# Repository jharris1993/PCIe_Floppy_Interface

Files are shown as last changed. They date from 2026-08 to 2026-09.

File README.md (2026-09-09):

# Floppy Drive Interface

A hardware/software project to develop a programmable floppy-disk controller and Shugart-interface platform, ultimately implemented as an internal PCIe card.

## Project goals

The primary goal is broad compatibility with floppy drives and disk formats that use conventional Shugart-derived interfaces, including 3.5-inch and 5.25-inch drives and, where practical, 8-inch drives.

The design should support programmable controller behavior rather than being restricted to the assumptions of a conventional PC floppy-disk controller. Future support for flux-transition timing is desirable, but it is secondary to the core controller/interface function and must not materially increase initial cost or complexity.

## Development approach

Development is intentionally staged:

1. Validate floppy-drive control and data handling using a practical FPGA or programmable-logic development platform.
2. Implement and test controller functions including drive selection, motor control, seeking, index handling, read/write operation, and FM/MFM data handling.
3. Develop the host-side software and investigate practical integration with current 64-bit Windows.
4. Migrate the validated design to PCIe.
5. Produce a custom single-board implementation when the architecture is sufficiently mature.

## Repository documentation

- [`Requirements.md`](Requirements.md) — authoritative current project requirements.
- [`Design.md`](Design.md) — current, non-authoritative project design.
- [`Dependencies.md`](Dependencies.md) — external projects, specifications, tools, and pinned baselines.
- [`AGENTS.md`](AGENTS.md) — instructions for Codex and other repository-aware coding agents.
- [`CONTRIBUTING.md`](CONTRIBUTING.md) — repository working practices and change discipline.
- [`Project_Decisions/`](Project_Decisions/) — non-authoritative engineering notebook of significant project choices and rationale.
- [`Documents/`](Documents/) — project-created supporting documentation.
- [`Reference_Documentation/`](Reference_Documentation/) — external technical documents and research.
- [`Reference_Illustrations/`](Reference_Illustrations/) — external explanatory illustrations.
- [`Reference_Implementations/`](Reference_Implementations/) — external implementations available for design reference.
- [`Tools/`](Tools/) — project development, verification, and automation tooling.

## Repository structure

```text
project-root/
├── .gitattributes
├── AGENTS.md
├── CONTRIBUTING.md
├── Dependencies.md
├── Design.md
├── Documents/
├── Drivers/
├── Firmware/
├── Hardware/
├── LICENSE.md
├── Licenses/
├── Project_Decisions/
├── README.md
├── Reference_Documentation/
│   ├── Documents/
│   ├── Pinouts/
│   ├── Research/
│   ├── Schematics/
│   ├── Specifications/
│   ├── README.md
│   └── Sources.md
├── Reference_Illustrations/
├── Reference_Implementations/
│   └── Greaseweazle/
├── Requirements.md
├── Software/
└── Tools/
```

Detailed organization should be defined close to the material it describes.

## Project status

Architecture and baseline documentation are under development. Hardware, firmware, host software, and driver implementation should not be assumed complete unless explicitly documented.

## License

This project is governed by the license conditions specified in [`LICENSE.md`](LICENSE.md).

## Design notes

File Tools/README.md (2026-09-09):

# Tools

This directory contains version-controlled development and verification tooling used by the project.

`Codex_Skills/kicad-eda` is the maintained source for the locally installed KiCad EDA skill. Its installation is a copy; removing that copy does not remove this source.

`Codex_Skills/literal-action-authorization` is the maintained source for the personal interaction rule that interprets questions, imperative instructions, and ambiguous requests in context.

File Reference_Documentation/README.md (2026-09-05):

# Reference Documentation

This directory contains external technical documents and project-created research used for engineering reference.

Material here does not define project requirements or the current project design. Evaluate each source for its origin, revision, applicability, and accuracy.

- `Documents/` contains retained reference documents.
- `Pinouts/` contains connector and interface pinouts.
- `Research/` contains project-created research.
- `Schematics/` contains externally sourced electrical schematics.
- `Specifications/` contains retained technical specifications.

See `Sources.md` for source information.

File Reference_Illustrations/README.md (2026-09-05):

# Reference Illustrations

This directory contains external illustrations retained for technical explanation or comparison.

Electrical schematics, connector pinouts, and technical documents belong in `Reference_Documentation/`.

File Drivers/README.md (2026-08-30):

# Drivers

This directory contains host operating-system driver source and related files.

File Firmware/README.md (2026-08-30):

# Firmware

This directory contains FPGA gateware and device firmware.

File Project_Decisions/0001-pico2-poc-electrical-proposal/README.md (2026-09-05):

# Pico 2 drive interface — tentative electrical design

Status: discussion proposal, 2026-09-01. Not a fabrication release or a hardware-verified circuit. This supplements the existing requirements; it does not select the final controller architecture. Pico GPIO numbers remain deliberately unassigned.

## Drawings

- `interface-cells.svg` / `.png`: reusable output, input, and configurable-direction circuits.
- `connector-map.svg` / `.png`: channel allocation, connector selection, and power connections.
- `draw_schematic.py`: editable drawing source; generates SVG and PNG using Python and Pillow. This is an electrical concept drawing, not a KiCad netlist; no electrical-rule check has been performed.

## Proposed circuit

Use discrete AO3400A N-channel MOSFETs as inverting open-drain outputs, and SN74LVC14A Schmitt-trigger inverters powered from the Pico's 3.3 V supply as receivers. All cable-side signals stay in the drive's 5 V domain. The Pico only sees 3.3 V logic. Both paths invert, so GPIO high means cable signal asserted low.

The MOSFET gate connects to its GPIO through 100 ohms, with 10 kilohms gate-to-source. Source is grounded; drain connects directly to the signal. A high GPIO asserts the signal. A low or high-impedance GPIO releases it. The pull-down is on the MOSFET side of any jumper. Do not infer suitability of an arbitrary substitute from gate threshold voltage: specify on-resistance at a gate voltage no greater than the actual GPIO high voltage. AO3400A specifies a maximum 48 milliohms at VGS = 2.5 V, at its stated 25 C test condition [S1]. Its switching figures use different gate drive/load conditions from this circuit; they are not a guaranteed board-level timing result.

Receiver: signal -> 100 ohms -> SN74LVC14A input; output -> 100 ohms -> GPIO. The receiver is powered at 3.3 V and accepts inputs up to 5.5 V. At 3.3 V +/- 0.3 V, the datasheet specifies a maximum propagation delay of 6.4 ns over -40 to +85 C, under its test conditions [S2]. Cable assertion produces a rising edge at the GPIO. Configure PIO accordingly, and sample READ DATA and INDEX with known relative timing.

For a role-changing signal, fit both paths and a 3-pin direction header. The centre contact connects to GPIO; one outer contact goes to the transmitter gate resistor, the other to the receiver output resistor. Fit one shunt only, or none for disabled. In receive mode the MOSFET gate pull-down holds the transmitter off. This provides configuration-time direction selection using one GPIO. It does not provide simultaneous transmit/readback. A genuinely bidirectional open-drain protocol would instead require independent TX and RX GPIOs, with the TX released during reception; a push-pull variant requires its own electrical review.

## Connector and channel allocation

Two 34-pin connectors are retained. For this inexpensive proposal, only one connector's signal bank is connected at a time. Seventeen 3-pin port-select headers route the 17 even-numbered signal positions to J1 (PC twisted cable) or J2 (approved alternate interface). Set the entire bank consistently with power off. Ground contacts are shared. This avoids connecting two terminator packs or incompatible signal outputs in parallel. Simultaneous operation on both connectors is not implemented by this proposal and remains an open requirement interpretation.

| Cable pin | PC controller-end interpretation | Alternate interface interpretation | Cell |
|---|---|---|---|
| 2 | Density control, if supported | Drive-specific; unresolved | Configurable |
| 4 | Reserved; disable | Drive-specific; unresolved | Configurable |
| 6 | Reserved; disable | DS4 on SA455/465 | Configurable |
| 8 | INDEX | INDEX / sector pulse where supported | RX |
| 10 | MOTOR A | DS1 on SA455/465 | TX |
| 12 | SELECT B | DS2 on SA455/465 | TX |
| 14 | SELECT A | DS3 on SA455/465 | TX |
| 16 | MOTOR B | MOTOR ON on SA455/465 | TX |
| 18 | DIRECTION | DIRECTION | TX |
| 20 | STEP | STEP | TX |
| 22 | WRITE DATA | WRITE DATA | TX |
| 24 | WRITE GATE | WRITE GATE | TX |
| 26 | TRACK ZERO | TRACK ZERO | RX |
| 28 | WRITE PROTECT | WRITE PROTECT | RX |
| 30 | READ DATA | READ DATA | RX |
| 32 | SIDE SELECT | SIDE SELECT, if supported | TX |
| 34 | DISK CHANGE, if supported | READY or drive-specific status | Configurable |

Signal names describe functions, not mandatory polarities or universal assignments. Check the exact approved drive manual before enabling pins 2, 4, 6, or 34. Conventional odd-numbered contacts are ground; nonstandard use of those positions needs a different adapter. J1 names are at the controller end of the twisted cable; do not apply the cable twist twice in firmware. The alternate map is an example, not approval of every SA455-family or full-height drive.

Total: nine fixed TX, four fixed RX, four configurable channels = seventeen GPIOs. Full population uses thirteen MOSFETs and eight receiver gates (two hex packages). Assign the receiver gates in cable-pin order 2, 4, 6, 8, 26, 28, 30, 34. SN74LVC14A 14-pin packages use A/Y pairs 1/2, 3/4, 5/6, 9/8, 11/10, 13/12; VCC = 14, GND = 7. Ground unused gate inputs and leave their outputs unconnected. Initial build may omit optional transmitter/receiver parts for unused channels. Additional jumper-sense GPIOs are optional and are not included in seventeen.

## Pull-ups and termination

For drive-to-controller lines, provision a removable 1 kilohm pull-up to +5V_IF near the receiver. Fit it for an open-collector output only after checking existing pull-ups and the drive's sink-current rating. At 5 V it draws approximately 5 mA. This is an initial short-cable value, not a universal floppy termination specification. Provide a footprint accepting an alternate value, including 150 ohms / 0.5 W only where the drive output specification permits that load.

For controller-to-drive lines, normally use the drive's existing input termination. Optional local pull-up footprints are DNP unless required by the selected drive; a local bias resistor does not replace specified far-end cable termination. Some older Shugart drives specify 150-ohm input termination and low-level currents up to 40 mA [S3]. At 5.25 V and a 150-ohm -5% resistor, the resistor alone draws about 36.8 mA. Include receiver input current and wiring/ground resistance in the final budget. A nominal 150-ohm resistor dissipates about 0.167 W when low at 5 V.

The selected MOSFET has ample static sink capability for one such load. A conventional LVC open-drain gate is not automatically suitable for this load. SN74LS06 is another plausible driver, but its specified VOL can reach 0.7 V at 40 mA [S4], whereas the cited old drive input specification calls for at most 0.4 V [S3]. The MOSFET avoids relying on typical TTL output saturation voltage. Do not install substantial series resistance in the drain/cable path: 33 ohms at 33 mA would add approximately 1.1 V to the low level.

## Timing assessment

For 250 kbit/s MFM, data-bit time is 4 us and legal transition intervals are 4, 6, or 8 us. Individual cable pulses are much narrower; their required width comes from the drive manual. A proof-of-concept should target clean edges on the order of 100 ns or better where practical and verify the actual read/write pulse widths at the cable connector.

Illustrative lumped-RC estimate: t(10-90%) = 2.2 R C. With an assumed total line capacitance of 100 pF, 1 kilohm gives 220 ns and 150 ohms gives 33 ns. A 10-kilohm pull-up would give 2.2 us. These are estimates, not simulations: actual cable, receiver, MOSFET drain capacitance (voltage-dependent), connector, and probe capacitance must be included. The gate also has a charging delay: AO3400A lists typical Ciss = 630 pF at its test point; 100 ohms alone gives a 63 ns RC time constant, before GPIO impedance and Miller effects. Do not reuse its fast datasheet switching figures as measurements of this circuit. Tune gate resistance/pulse programming based on scope measurements, or use a lower-charge, suitably specified MOSFET or gate buffer if necessary.

The receiver delay is comfortably below floppy bit periods. The output path is a credible DD prototype, but its pulse distortion and cable settling remain to be measured. PIO must generate edges and pulse widths; firmware should not bit-bang WRITE DATA under interrupts. Do not add debounce or large filter capacitors to READ DATA, WRITE DATA, or INDEX.

## Power and startup

Power the Pico through its USB connector for the prototype. Power receiver VCC from Pico 3V3(OUT). Obtain regulated +5V_IF from the same supply domain as the drive's 5 V electronics; drive power remains on the drive's separate power connector. Add any required 12 V there, according to the drive manual. Do not connect external +5V_IF to Pico VBUS or 3V3. All grounds are common; route motor power return separately from the interface return until the supply connection.

Fit 100 nF ceramic at each receiver IC and about 4.7 uF bulk on each local rail. Keep cable/ground connections short and retain the ribbon's ground conductors. No hot-plug or surge-protection qualification is claimed. The design assumes an internal, correctly wired 5 V drive interface; external/long-cable or odd-pin variants need explicit protection review.

Fit a removable WRITE ARM link in series with the WRITE GATE GPIO path, ahead of the gate resistor. Default is removed. Its MOSFET pull-down remains connected. This inhibits writes during bring-up even if firmware misconfigures the GPIO. On startup, set all TX data latches low before switching GPIOs to output, disable internal pull-ups on TX pins, and only arm writes after drive configuration. A hardware watchdog/write timeout is not implemented by this tentative circuit.

## Verification before drive testing

1. Confirm exact drive connector directions, termination, voltage limits, and pulse requirements.
2. Confirm the GPIO map suits the intended PIO programs and that jumpers match firmware configuration.
3. Test each TX into the expected pull-up load; measure VOL, pulse width, release time, and ringing, including worst simultaneous control states.
4. Test RX with realistic open-collector pulses; measure threshold crossing, polarity, and timing at the GPIO.
5. Check power-up/reset and disconnected-Pico behavior, with WRITE ARM removed. Check both selected/unselected connector banks.
6. Read known-good DD disks, then write expendable media and verify on an independent controller.

Completed for this proposal: datasheet review, DC/RC estimates, generated-drawing inspection. Not completed: SPICE simulation, EDA/ERC, PCB layout, oscilloscope measurements, or hardware read/write testing.

## Sources

- **S1:** [Alpha & Omega AO3400A datasheet](https://www.aosmd.com/sites/default/files/res/datasheets/AO3400A.pdf), Rev 3.1, July 2023, pp. 1-2: package, RDS(on), capacitance and switching conditions.
- **S2:** [TI SN74LVC14A datasheet](https://www.ti.com/lit/ds/symlink/sn74lvc14a.pdf), SCAS285AC, April 2022, sections 5, 6.4, 6.7, 6.9: pinout, voltage limits, thresholds, timing.
- **S3:** [Shugart SA455/465 manufacturer service manual, reproduced by ManualsLib](https://www.manualslib.com/manual/4220043/Shugart-Minifloppy-Sa455.html?page=18), sections 2.2.1-2.2.2, viewer pages 18-19: input current, low level, and 150-ohm termination. This is an illustrative legacy load; the actual proof-of-concept drive remains unspecified.
- **S4:** [TI SN74LS06 datasheet](https://www.ti.com/lit/ds/symlink/sn74ls06.pdf), SDLS020F, July 2016, section 6.5: VOL at specified sink currents.
- [Pico 2 datasheet](https://datasheets.raspberrypi.com/pico/pico-2-datasheet.pdf), release 5, July 2026, sections 3.1 and 5: board I/O and power connections.

Hardware drawings are under the repository's CERN-OHL-S-2.0 license. Drawing generator is under GPL-3.0-or-later.

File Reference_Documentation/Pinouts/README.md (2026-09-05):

# Pinouts

This directory contains connector and interface pinout references.

Pin assignments may vary between drive and interface families. Record each retained item and its applicability in `../Sources.md`.

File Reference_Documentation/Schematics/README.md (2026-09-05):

# Reference Schematics

This directory contains externally sourced electrical schematics.

Connector and interface pinouts belong in `../Pinouts/`.

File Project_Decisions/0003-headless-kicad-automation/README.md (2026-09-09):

# Headless KiCad 10 automation boundary

Date: 2026-09-09

## Context

The initial KiCad automation workflow used GUI conversion and, when automation failed, desktop capture/control. That occupied the user's foreground desktop and obscured whether a failure came from the Codex sandbox, KiCad IPC transport, or an unsupported API operation. KiCad 10 IPC requires a running GUI process, is focused on PCB Editor, and does not expose general schematic authoring. A successful IPC ping therefore is not evidence that document handlers are available.

## Decision

- Headless file and CLI workflows are the default.
- Desktop capture, mouse/keyboard automation, and launching KiCad's GUI require explicit user authorization for the current task.
- Native `.kicad_sch` sources are maintained directly. The scaffold tool only clones a known-good native schematic, regenerates UUIDs, updates instance project names, and changes existing title-block fields; it does not claim arbitrary symbol placement.
- Declarative PCB construction uses the `pcbnew` module bundled with the selected KiCad installation. Placement, pad-to-net assignments, and routes remain explicit inputs; the tool does not autoroute.
- `kicad-cli` is the verification and export authority for ERC, DRC, netlist/BOM, schematic renders, PCB renders, and fabrication outputs.
- On the Windows Codex host, all `kicad-cli` callers run outside the sandbox under the normal user through narrowly scoped approval. Maintained wrappers refuse the `CodexSandboxOffline` identity before invoking KiCad; Administrator elevation is not required.
- The KiCad 10 IPC client is pinned to `kicad-python` 0.7.1. IPC diagnostics distinguish transport connectivity from handler capability.
- Maintained source, dependency pins, tests, and fixtures are committed under `Tools/Codex_Skills/kicad-eda`. Personal skill copies, virtual environments, registry data, IPC sockets, and temporary renders are not committed.

## Consequences

The workflow is reproducible and reversible through Git without taking control of the desktop. KiCad 10 still cannot provide a supported fully general headless schematic editor; circuit-specific native-format changes require careful format work followed by ERC, exported connectivity/BOM checks, and visual inspection. The sandbox may emit nonfatal Windows registry warnings from `kicad-cli`; commands that need the real per-user KiCad state or IPC transport may require narrowly scoped execution outside the sandbox.

The regression suite covers native schematic cloning and CLI parsing, declarative PCB generation with a routed net and clean DRC, and rejection of an invalid duplicate-net specification. More complex fixtures should be added when their corresponding generator features are introduced.

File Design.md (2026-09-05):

# Design

This document describes the current design used to implement `Requirements.md`. It is not authoritative and does not override the project requirements. Implementation choices may change as long as the requirements remain satisfied or are deliberately revised.

## 1. Architectural concept

The system is divided into four primary layers:

```text
Host software / OS integration
            │
      Host command layer
            │
   PCIe interface / transport
            │
 FPGA controller and timing logic
            │
   Shugart-compatible drive I/O
            │
        Floppy drive
```

Early prototypes may replace PCIe with a simpler development transport while preserving the command/controller separation.

## 2. FPGA / programmable logic

The programmable-logic portion is expected to handle timing-critical functions such as:

- drive-control signal generation and sampling;
- step timing;
- index timing and measurement;
- read-data sampling;
- write-data generation;
- FM/MFM encode/decode support;
- data separation or equivalent timing recovery;
- configurable controller parameters;
- buffering and host-facing command execution.

The exact partition between FPGA logic and embedded/host software remains open until a development platform is selected.

## 3. Shugart interface

The drive-side interface should be designed for broad Shugart-derived compatibility rather than only the IBM-PC subset.

The electrical design must explicitly account for:

- signal direction;
- open-collector/open-drain behavior where applicable;
- pull-up requirements;
- voltage levels;
- termination;
- connector pinout variants;
- optional or historically reused signals;
- protection against incompatible external drive wiring.

Signal capabilities that are not required for a particular drive should be software- or hardware-disableable where practical.

## 4. Data handling

The first implementation should prioritize conventional sector operation using FM and MFM encoding.

The architecture should avoid unnecessarily discarding low-level timing information. If practical without substantial complexity, the read path should retain enough timing information to support later diagnostics or transition-level capture.

Full Greaseweazle-style flux capture/replay is not a first-stage requirement.

## 5. Host interface

The final host interface is PCIe.

A likely structure is:

```text
Host driver/software
       │
 command / descriptor interface
       │
 PCIe endpoint + DMA or mapped buffers
       │
 controller command engine
       │
 floppy timing/data engine
```

The exact PCIe endpoint architecture, DMA strategy, BAR layout, interrupt model, and driver interface remain open design decisions.

## 6. Host command model

Commands should express controller operations independently of the physical development transport where reasonable. Candidate operations include:

- query capabilities;
- select/configure drive;
- motor on/off;
- seek/step;
- read sector/track;
- write sector/track;
- read status;
- configure timing/format parameters;
- diagnostic timing operations.

Transport-independent command semantics will make it easier to develop against UART/USB/JTAG or another temporary interface before PCIe is available.

## 7. Windows integration

Windows integration is a research item, not an assumed solved problem.

The project should evaluate at least two host-facing models:

1. presentation as a conventional floppy/controller device where current Windows permits it; and
2. a project-specific device interface with user-mode software when conventional floppy enumeration is impractical.

The architecture should not depend on `A:`/`B:` drive-letter presentation until driver feasibility is demonstrated.

## 8. Development sequence

### Stage 1 — Controller proof of concept
Use a practical programmable-logic development platform to validate drive control, seeking, index handling, read/write timing, FM/MFM processing, and sector-level operation.

### Stage 2 — Command and host software
Define a stable host/controller command boundary and develop diagnostic/test software.

### Stage 3 — PCIe proof of concept
Move the host interface to PCIe using a development board or validated endpoint solution.

### Stage 4 — OS integration
Develop and validate the selected Windows/Linux driver and host integration strategy.

### Stage 5 — Custom hardware
Integrate the proven logic, electrical interface, PCIe endpoint, power, connectors, and protection circuitry onto the final board.

## 9. Open design questions

The following are intentionally unresolved and should be decided through analysis or prototypes rather than assumed:

- FPGA family and development board.
- PCIe endpoint implementation.
- DMA versus programmed-I/O balance.
- FPGA/firmware/software partitioning.
- Exact command protocol.
- Windows device/driver architecture.
- Level shifting and line-interface implementation.
- Extent of 8-inch-drive support.
- Extent of Greaseweazle compatibility.
- Depth and representation of optional flux-timing data.

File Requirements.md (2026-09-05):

# Requirements

This document is the authoritative current requirements specification for the floppy-drive interface project. Requirements are normative unless explicitly marked optional or future.

## 1. Functional scope

### R1 — Primary function
The system shall provide a programmable floppy-disk controller and digital Shugart-interface implementation suitable for a broad range of conventional floppy drives and disk formats.

### R2 — Drive compatibility
The system shall support 3.5-inch and 5.25-inch floppy drives using two separate 34-pin signal-interface connectors.

One connector shall support IBM PC/AT-compatible drives using the conventional twisted-cable drive-selection arrangement.

The second connector shall support other approved 34-pin interface variants, including compatible 5.25-inch drives and older full-height units where electrically practical. To the greatest extent practical, interface differences shall be selected by jumpers. Where possible, these jumpers shall provide configuration inputs to the controller or programmable logic, which shall reconfigure the applicable connector signals.

### R3 — Programmable geometry and timing
The controller shall avoid unnecessary fixed assumptions about disk geometry or drive mechanics. Where technically practical, software or firmware shall be able to configure parameters such as:

- cylinders/tracks;
- heads/sides;
- sectors per track;
- step behavior;
- rotational/index behavior;
- sector size;
- data rate;
- FM/MFM encoding;
- hard- or soft-sector operation where supported by the hardware;
- use or non-use of optional drive signals.

### R4 — Basic drive control
The system shall provide the drive-control functions needed for normal floppy operation, including as applicable:

- drive select;
- motor control;
- direction and step;
- track-zero sensing;
- write gate/data;
- read data;
- index;
- write protect;
- head/side selection.

### R5 — Sector-level operation
The initial functional target shall include reliable sector-oriented read and write operation using common FM and MFM formats.

## 2. Architecture

### R6 — Programmable logic
Timing-critical floppy-controller behavior should be implemented in FPGA or comparable programmable logic when that materially improves determinism, flexibility, or future extensibility.

### R7 — Host interface
The final hardware target shall be a single-board internal PCIe device. USB shall not be required as a bridge in the final product.

### R8 — Staged development
The design may use non-PCIe development hardware during early implementation when this reduces development risk. The architecture should avoid choices that unnecessarily prevent later migration to PCIe.

### R9 — Transport abstraction
Host commands and controller operations should be kept reasonably independent of the physical host transport so that early development interfaces can be replaced without redesigning the controller model.

## 3. Flux timing

### R10 — Future transition timing
The design should preserve a practical path to exposing read-transition timing and, potentially, write-transition timing for diagnostic or disk-reconstruction purposes.

### R11 — Secondary priority
Flux-transition capture/replay is a secondary capability. Components shall not be selected solely for full flux-level functionality when doing so materially increases cost or complexity for the primary controller requirements.

## 4. Host software

### R12 — Current 64-bit Windows research
The project shall investigate practical methods for presenting the hardware to current 64-bit Windows as a conventional floppy device where feasible.

### R13 — Drive-letter behavior
Conventional `A:`/`B:` floppy-drive presentation is desirable where supported by the operating system and driver architecture, but shall not be assumed feasible until demonstrated.

### R14 — OS limitations
Any operating-system, driver-signing, enumeration, or compatibility limitations discovered during implementation shall be documented rather than hidden behind emulation assumptions.

## 5. External compatibility

### R15 — Greaseweazle reference
The Greaseweazle project may be used as a technical reference and possible compatibility target for selected functionality. It shall not define the architecture when doing so conflicts with the project's primary programmable-FDC requirements.

### R16 — External baselines
Any external source code or design used as an implementation baseline shall be recorded in `Dependencies.md` with enough information to identify the exact upstream version or commit.

## 6. Engineering constraints

### R17 — Digital drive interface
The controller shall treat the normal Shugart drive connection as a digital interface. Magnetic-head analog processing remains internal to the floppy drive unless a future design explicitly changes this scope.

### R18 — Prototype practicality
Early prototypes may use development boards, adapters, or conventional prototyping methods. High-speed, signal-integrity, voltage, or placement constraints shall take precedence over a preferred prototyping form when necessary.

### R19 — Evidence before commitment
Unverified assumptions about PCIe, Windows driver behavior, legacy floppy support, or external-project compatibility shall be treated as open engineering questions until demonstrated or supported by authoritative documentation.

## 7. Documentation and change control

### R20 — Significant decisions
Significant architectural or compatibility decisions shall be recorded in `Project_Decisions/` when the rationale would otherwise be difficult to reconstruct later.

### R21 — Source of truth
When repository documents disagree, `Requirements.md` governs project requirements and supersedes conflicting repository documentation.

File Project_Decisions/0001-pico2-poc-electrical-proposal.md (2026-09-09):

# Pico 2 proof-of-concept electrical interface

Date: 2026-09-01

Status: proposed for discussion; not an approved final architecture or fabrication baseline.

## Context

The user requested an inexpensive proof of concept supplementing the original requirements, assumed a Pico 2 with an unspecified GPIO allocation, and requested a tentative drive-interface schematic. PCIe is outside this prototype discussion.

## Proposal

Use open-drain MOSFET transmitters, 3.3 V Schmitt-trigger receivers with 5 V-tolerant inputs, and hardware direction selection for variant connector signals. Preserve two connector options with one selected at a time. Detailed circuits and assumptions are in [the proposal README](0001-pico2-poc-electrical-proposal/README.md).

## Rationale and alternatives

Some legacy drives specify approximately 40 mA low-level interface loads. A suitably specified MOSFET avoids the low-voltage margin problem of assuming every open-drain logic IC can sink that load. Direction-selected circuits fit the existing seventeen-signal premise. True bidirectional operation would use distinct drive and sense paths and needs an explicit protocol requirement. Separate buffered ports would be preferable if both connectors must be electrically active concurrently.

## Consequences and unresolved items

Pico GPIO mapping, drive variants, pulse requirements, cable loading, and power sequencing remain to be validated. AO3400A is a candidate whose GPIO-driven switching must be measured. No hardware or simulation verification is claimed. This proposal does not supersede Requirements.md or commit the final design away from programmable logic.

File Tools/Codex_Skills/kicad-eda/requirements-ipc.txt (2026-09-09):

# Pinned, known-working KiCad 10 IPC environment (Python 3.11, Windows x64).
attrs==26.1.0
cffi==2.1.1
jsonschema==4.26.0
jsonschema-specifications==2025.9.1
kicad-python==0.7.1
protobuf==5.29.6
pycparser==3.0
pynng==0.9.0
PyYAML==6.0.3
referencing==0.37.0
rpds-py==2026.6.3
sniffio==1.3.1
typing_extensions==4.16.0

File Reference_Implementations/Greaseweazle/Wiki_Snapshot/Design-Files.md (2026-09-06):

Design files for all Greaseweazle boards are linked below:

- [F1 Adapter Board](#f1-adapter-board)
- [F7 v1](#f7-v1)
- [F7 v2](#f7-v2)
- [F7 v3](#f7-v3)
- [F7 Lightning](#f7-lightning)
- [F7 Lightning Plus](#f7-lightning-plus)
- [F7 Slim](#f7-slim)
- [V4](#v4)
- [V4 Slim](#v4-slim)
- [V4.1](#v41)

Test jig for F7 v3, F7 Lightning Plus, V4, V4.1, F1 Plus:
- [Test Jig v2.1](#test-jig-v21)

External links to design files for third-party boards:
- [F1 Plus][f1plusdiy]
- [F7 Plus][f7plusdiy]

## F1 Adapter Board

**DirtyPCBs:** The simplest method, using a [direct purchase
link][dirtypcbs] and costing approximately $25 in total. Once the
design is added to your cart, be sure to increase the *Size* to
*10x10*, or your order will be rejected! You can also choose *Color*,
and optionally increase *Thickness* to *1.6mm* without increasing
purchase cost. Your order will yield 10 PCBs, each containing 4 PC
34-pin adapters and 1 Amstrad 26-pin adapter: 50 in total!

**Custom order (Gerbers):** The Gerber sources for the 10x10cm panel
as in the above DirtyPCBs store link can be downloaded
[here](assets/adapter_rev1/F1_10x10_Gerbers.zip).

**Custom order (KiCad):** The original KiCad PCB design is available in my
[PCB Projects git repository][pcbprojects]. The single-board PC design
is available under *greaseweazle/*, the Amstrad design under *gw-26/*, and
the five-to-a-panel design (as in the DirtyPCBs store link) is under
*panels/GW*. You will need to use KiCad to generate Gerbers.

**Schematic:** You can design your own adapter board based on the
original schematic ([PDF](assets/f1_schematic.pdf)).

## F7 v1

Thanks to George R. Mezzomo for the hardware layouts and collaboration on
schematic design. These designs may be freely reproduced: for example, in
the manufacture of PCBs by your favourite board factory. When making boards
please use the latest version (currently v1.1).

**PCB v1.0:**
- [Schematic](assets/f7_rev1/F7_10_Schematic.pdf) (Note: Incorrect
values for C1,C2,C12,C19,C20,R6)
- [Gerbers](assets/f7_rev1/F7_10_Gerbers.zip)

**PCB v1.1:**
- [Schematic](assets/f7_v1.1/F7_11_Schematic.pdf)
- [Bill of Materials](assets/f7_v1.1/F7_11_Bill_Of_Materials.pdf)
- [Gerbers](assets/f7_v1.1/F7_11_Gerbers.zip)
- Fixes:
  - R1-R4 footprint (0603 rather than 0402)
  - DEBUG header extended to 5x1 to include RST pin
  - USB footprint pin spacing
  - USB connector moved closer to board edge
  - STM32 VBAT connected to VDD
  - Diode orientations marked on PCB
  - Board version added to bottom-side copper
  - Some passive component values fixed in schematic and BoM

## F7 v2

Thanks to George R. Mezzomo for the hardware layout and collaboration on
schematic design. These designs may be freely reproduced: for example, in
the manufacture of PCBs by your favourite board factory.

- [Schematic](assets/f7_v2/F7_v2_Schematic.pdf)
- [Bill of Materials](assets/f7_v2/F7_v2_Bill_Of_Materials.pdf)
- [Gerbers](assets/f7_v2/F7_v2_Gerbers.zip)

## F7 v3

Thanks to George R. Mezzomo for the hardware layout and collaboration on
schematic design. These designs may be freely reproduced: for example, in
the manufacture of PCBs by your favourite board factory.

- [Schematic](assets/f7_v3/F7_v3_Schematic.pdf)
- [Bill of Materials](assets/f7_v3/F7_v3_Bill_Of_Materials.pdf)
- [Gerbers](assets/f7_v3/F7_v3_Gerbers.zip)

## F7 Lightning

Thanks to George R. Mezzomo for the hardware layout and collaboration on
schematic design. These designs may be freely reproduced: for example, in
the manufacture of PCBs by your favourite board factory.

- [Schematic](assets/f7_lightning/F7_Lightning_Schematic.pdf)
- [Bill of Materials](assets/f7_lightning/F7_Lightning_Bill_Of_Materials.pdf)
- [Gerbers](assets/f7_lightning/F7_Lightning_Gerbers.zip)

## F7 Lightning Plus

Thanks to George R. Mezzomo for the hardware layout and collaboration on
schematic design. These designs may be freely reproduced: for example, in
the manufacture of PCBs by your favourite board factory.

- [Assets](assets/f7_lightning_plus/f7_lightning_plus.zip)

## F7 Slim

Thanks to George R. Mezzomo for the hardware layout and collaboration on
schematic design. These designs may be freely reproduced: for example, in
the manufacture of PCBs by your favourite board factory.

- [Schematic](assets/f7_slim/F7_Slim_Schematic.pdf)
- [Bill of Materials](assets/f7_slim/F7_Slim_BoM.pdf)
- [Gerbers](assets/f7_slim/F7_Slim_Gerbers.zip)

## V4

Thanks to George R. Mezzomo for the hardware layout and collaboration on
schematic design. These designs may be freely reproduced: for example, in
the manufacture of PCBs by your favourite board factory.

- [Assets](assets/v4/GW_V4_210511.zip)

## V4 Slim

Thanks to George R. Mezzomo for the hardware layout and collaboration on
schematic design. These designs may be freely reproduced: for example, in
the manufacture of PCBs by your favourite board factory.

- [Assets](assets/v4_slim/v4Slim.zip)

## V4.1

Thanks to George R. Mezzomo for the hardware layout and collaboration on
schematic design. These designs may be freely reproduced: for example, in
the manufacture of PCBs by your favourite board factory.

- [Assets](assets/v4.1/GW_V41_231112.zip)

## Test Jig v2.1

Thanks to George R. Mezzomo for the hardware layout and collaboration on
schematic design. These designs may be freely reproduced: for example, in
the manufacture of PCBs by your favourite board factory.

- [Assets](assets/testjig/greaseweazle-testjig-v2.1.zip)

[f1plusdiy]: https://github.com/solarmon/greaseweazle
[f7plusdiy]: https://github.com/aerobaticant/greaseweazle-F7-Plus
[dirtypcbs]: https://dirtypcbs.com/store/designer/details/keirfraser/6387/greaseweazle-rev-1-panel
[pcbprojects]: https://github.com/keirf/pcb-projects

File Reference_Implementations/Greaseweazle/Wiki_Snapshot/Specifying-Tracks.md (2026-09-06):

The read, write and erase commands can all act on a specified set of
disk tracks. The format specifier is presented by **--tracks=** and can
contain any of the following elements:
- **c=\<set\>**: Set of cylinders to access
- **h=\<set\>**: Set of heads (sides) to access
- **step=[0-9]**: Number of physical head steps between cylinders (default 1)
- **hswap**: Physical drive heads are swapped
- **h[01].off=[+-][0-9]**: Physical cylinders of the specified head are offset by the specified amount (used for flippy-modded 5.25" drives only!)

**\<set\>** is a comma-separated list of integers and integer ranges.

For example:
- `c=0-7,9-12:h=0-1`: Accesses both sides of cylinders 0-7 and 9-12.
- `c=0-39:h=0:step=2`: Read a single-sided 40-cyl disk in an 80-cyl drive.
- `c=0-79:h=0:hswap`: Treat physical side 1 as a second single-sided image on a double-sided disk.
- `c=0-79:h=0,1:h1.off=-8`: Read both sides of a C64 flippy disk, including half tracks, in one pass.

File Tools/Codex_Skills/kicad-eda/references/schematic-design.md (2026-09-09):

# Schematic design

## Required inputs

Establish the intended function, interfaces, supply rails, tolerances, environmental conditions, safety constraints, programmable behavior, and test strategy. Obtain authoritative datasheets for every active or pin-sensitive component. Mark missing values as unresolved.

## Structure

- Partition sheets by function and signal flow. Keep sheet interfaces explicit and stable.
- Use descriptive net names. Distinguish rails whose nominal voltage is the same but whose filtering, sequencing, or current path differs.
- Show connector pin numbers, polarity, active-low notation, direction, voltage domain, and off-board protection clearly.
- Put decoupling, bias, termination, protection, clock, reset, and programming circuitry next to the device or interface they serve.
- Use net labels to clarify structure, not to conceal an unreadable connection graph.

## Components and BOM data

Verify symbol pin numbers and electrical types against the exact package/datasheet. Assign an exact footprint before PCB work. Populate manufacturer, manufacturer part number, description, tolerance/rating, and procurement fields required by the project. Record substitutions explicitly; do not treat a parametric match as approved.

## Verification

Run annotation and ERC. Resolve warnings by correcting the circuit; use exclusions or no-connect markers only when their intent is documented. Export a netlist/BOM and check that references, values, footprints, and part numbers agree with the schematic. Render all changed sheets and inspect junctions, labels, overlapping text, bus entries, power symbols, and page boundaries.

## KiCad 10 headless boundary

KiCad 10 has no supported headless schematic-authoring API. Create or transform native `.kicad_sch` files only from a known native source whose embedded symbols and instance data are preserved. `Build-KiCadSchematic.py` can create a project-specific native scaffold from such a template, regenerate UUIDs, update the root instance path, and set title-block metadata. It does not add arbitrary symbols or infer pin geometry. Circuit-specific composition must be followed by CLI ERC, netlist/BOM export, PDF rendering, and visual inspection.

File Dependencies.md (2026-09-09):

# Dependencies and External References

This file records external projects, specifications, tools, and implementation baselines that materially affect the project.

Do not record an external project merely because it was consulted during discussion. Add it when the repository depends on it, implements compatibility with it, or uses it as a significant engineering baseline.

## Source-code baselines

No source-code baselines have been selected.

## Hardware / protocol specifications

Add authoritative specifications here when selected, for example:

| Specification | Purpose | Revision | Source | Notes |
|---|---|---|---|---|
| PCI Express Base Specification | PCIe endpoint/interface design | TBD | PCI-SIG | Record the actual revision used. |
| Floppy/Shugart interface references | Drive electrical and signal behavior | TBD | TBD | Prefer original manufacturer documentation where available. |

## Development tools

Tool versions should be pinned when reproducibility depends on them.

| Tool | Purpose | Required version | Notes |
|---|---|---|---|
| KiCad | Schematic capture, PCB layout, libraries, verification, and fabrication output | 10.0.6 | Standard Windows x64 installation with official libraries and API server enabled. The packaged libraries are the selected baseline; do not replace them with moving GitLab `master` branches. |
| kicad-python | Official KiCad IPC Python binding | 0.7.1 | Last binding release aligned with KiCad 10. Installed in an isolated Codex tool environment; exact transitive versions are recorded by the installer. Requires a running KiCad 10 instance and is limited mainly to PCB operations. |
| FPGA vendor toolchain | HDL synthesis/place-and-route/programming | TBD | Define after FPGA selection. |
| HDL simulator | Simulation and automated verification | TBD | Define after HDL/toolchain selection. |
| Host compiler/toolchain | Host utilities and driver support | TBD | Record separately per supported OS if needed. |

### KiCad 10.0.6 standard-library baseline

The standard installer contains packed/installed forms of the official library repositories. The release-tag commits corresponding to the selected KiCad version are:

| Library | Upstream | Release/tag | Commit | License | Local installed form |
|---|---|---|---|---|---|
| Schematic symbols | `https://gitlab.com/kicad/libraries/kicad-symbols` | `10.0.6` | `7800d91437ce44e2ed0928f2ad31a287457b8a68` | CC BY-SA 4.0 | 223 packed `.kicad_sym` libraries |
| PCB footprints | `https://gitlab.com/kicad/libraries/kicad-footprints` | `10.0.6` | `819223b66f96508feaeaa305301b5e6bb5c1038b` | CC BY-SA 4.0 | 155 `.pretty` libraries containing 15,450 files |
| 3D models | `https://gitlab.com/kicad/libraries/kicad-packages3D` | `10.0.6` | `e62ed1fc7862da83f789bd562671b5e4b82afcdf` | CC BY-SA 4.0 | 7,251 STEP models |
| Project templates | `https://gitlab.com/kicad/libraries/kicad-templates` | `10.0.6` | `3ed4538b0f965d821df63a5fffc4441e723cfe7f` | CC BY-SA 4.0 | 19 template directories |

The separate `kicad-packages3D-source` repository is not an implementation dependency. It contains editable/generator sources for contributing 3D models and is unnecessary for schematic capture, footprint assignment, PCB layout, 3D viewing, or fabrication exports. Add and pin it only if the project begins maintaining custom generated 3D models from those source formats.

## Rules for adding dependencies

For every implementation dependency, record:

1. canonical upstream location;
2. exact release/tag/commit where practical;
3. purpose in this project;
4. applicable license;
5. local modifications or patches, if any;
6. update procedure or compatibility constraint when relevant.

Do not silently update an implementation baseline. A change that can affect compatibility or behavior should be documented and, when significant, recorded in `Project_Decisions/`.

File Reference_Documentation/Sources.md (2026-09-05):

# Reference Sources

## Shugart SA800/801 manual

- Local file: `Documents/SA800-801 Diskette Storage Drive.pdf`
- Subject: Shugart SA800/801 diskette storage drives
- Source and version:

## 34-pin floppy-interface pinout

- Local file: `Pinouts/fdd-bus-interface-34p.png`
- Subject: 34-pin floppy-drive interface
- Source and version:

## Online references

### Floppy interface

- Shugart interface reference: https://retrocmp.de/fdd/general/floppy-bus.htm
- Floppy disk drive interface overview: https://en.wikipedia.org/wiki/Floppy_disk_drive_interface
- Floppy-drive pinout: https://dfarq.homeip.net/floppy-drive-pinout/
- Floppy drives and media: https://www.retrotechnology.com/herbs_stuff/drive.html

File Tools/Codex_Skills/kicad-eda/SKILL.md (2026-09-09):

---
name: kicad-eda
description: Create, edit, inspect, verify, and release KiCad schematics, symbol and footprint libraries, PCB layouts, BOMs, plots, and fabrication outputs. Use for .kicad_pro, .kicad_sch, .kicad_pcb, .kicad_sym, .kicad_mod, ERC, DRC, placement, routing, stackups, Gerbers, drills, or KiCad IPC work. Do not use for unrelated electronics prose that does not involve a KiCad artifact.
---

# KiCad EDA

Produce electrically justified, mechanically consistent, reviewable KiCad artifacts. Treat a project as the unit of work: keep its project, schematic, board, project-local libraries, rules, and release configuration together.

## Before changing a design

- Read repository instructions and the applicable requirements, design, dependency, and decision documents. Requirements govern when documents disagree.
- Identify unresolved electrical, mechanical, fabrication, component-availability, and interface assumptions. Do not convert an assumption into a design choice silently.
- Inspect the whole KiCad project and determine its saved KiCad version. Work on a Git-backed branch or other recoverable copy before a format upgrade or substantial edit.
- Prefer official KiCad 10 CLI and IPC APIs. Do not install or execute third-party plugins, libraries, scripts, or models without checking provenance, license, version, and authorization.

## Route the task

- For schematic creation, connectivity, annotation, power flags, hierarchy, and BOM fields, read [references/schematic-design.md](references/schematic-design.md).
- For placement, stackup, constraints, routing, planes, return paths, and mechanical layout, read [references/pcb-layout.md](references/pcb-layout.md).
- For symbols, footprints, 3D models, design blocks, and templates, read [references/libraries-and-templates.md](references/libraries-and-templates.md).
- For ERC, DRC, plots, BOMs, Gerbers, drills, position files, STEP, and release gates, read [references/release-workflow.md](references/release-workflow.md).
- For a running KiCad session or API-based PCB manipulation, read [references/ipc-automation.md](references/ipc-automation.md).
- In this repository, also read [references/pcie-floppy-project.md](references/pcie-floppy-project.md).

## Editing methods

Choose the least fragile method that supplies the needed capability:

1. Prefer headless, file-based work: native KiCad sources, KiCad's bundled `pcbnew` Python for PCB construction, and `kicad-cli` for checks and exports.
2. Use the official `kicad-python` IPC binding only for operations its capability probe confirms against a running KiCad session. KiCad 10 IPC does not provide general schematic authoring.
3. Invoke [scripts/Invoke-KiCad.ps1](scripts/Invoke-KiCad.ps1) for deterministic checks and exports. On this Windows host, every process that invokes `kicad-cli` must run outside the Codex sandbox under the normal user through a narrowly scoped approval. The wrapper and regression runner enforce this by refusing the `CodexSandboxOffline` identity. This is sandbox escape approval, not Administrator elevation.
4. Use [scripts/Build-KiCadPcb.py](scripts/Build-KiCadPcb.py) for declarative PCB construction and [scripts/Build-KiCadSchematic.py](scripts/Build-KiCadSchematic.py) for native schematic scaffolding or checked transformations. If schematic scaffolding uses `--kicad-cli`, run that process outside the sandbox too.
5. Edit native KiCad S-expressions only when the format and operation are understood. Preserve or regenerate UUIDs deliberately, keep embedded library data consistent, make narrow edits, and validate connectivity plus rendered output.

Do not capture or control the user's desktop, launch KiCad's GUI, or use GUI keystroke/mouse automation unless the user explicitly authorizes that method for the current task. A headless limitation is a capability boundary to report, not implicit permission to take over the desktop.

Never claim that a syntactically valid file is an electrically correct design. Never infer pin numbers, footprints, voltage limits, polarity, stackup, impedance, or manufacturer ordering data from a similar-looking part.

## Completion gates

- Schematic work: verify annotation, connectivity, pin mapping, required fields, and ERC; render every affected sheet and visually inspect it.
- PCB work: verify schematic parity, board outline, stackup/rules, placement constraints, routing, zones, and DRC; inspect relevant copper, mask, silkscreen, fabrication, and 3D views.
- Release work: generate outputs from a clean verified source, inspect the output manifest, and keep generated files separate from source unless repository policy says otherwise.
- Report the exact KiCad/tool versions, checks run, violations or exclusions, generated outputs, and anything not verified. Hardware behavior remains unverified without hardware testing or authoritative evidence.

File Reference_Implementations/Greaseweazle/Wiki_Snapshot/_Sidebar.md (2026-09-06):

## Getting Started
- [**Purchase a Greaseweazle**](Purchase-a-Greaseweazle)
- [**Download the Host Tools**](Download-Host-Tools)
- [Greaseweazle Models](Greaseweazle-Models)

## Building a Weazle
- [Design Files](Design-Files)
- [Hardware Assembly](Hardware-Assembly)
- [Firmware Programming](Firmware-Programming)

## User Installation
- [Hardware Setup](Hardware-Setup)
  - [V4 Setup](V4-Setup)
  - [V4.1 Setup](V4.1-Setup)
- [Software Installation](Software-Installation)
- [IPF Images](IPF-Images)

## Usage
- [Getting Started](Getting-Started)
  - [Yann Serra's Tutorial](Yann-Serra-Tutorial)
- [Supported Image Types](Supported-Image-Types)
- [Drive Select](Drive-Select)
- [Specifying Tracks](Specifying-Tracks)
- [Write Precompensation](Write-Precompensation)
- [Flippy Disks](Flippy-Disks)
- [Firmware Update](Firmware-Update)

## Support
- [Troubleshooting FAQ](Troubleshooting-FAQ)
- [STM32 Fakes](STM32-Fakes)
- [Building Firmware](Building-Firmware)
- [GitHub][github]
- [Discord][discord]

[github]: https://github.com/keirf/greaseweazle/discussions
[discord]: https://discord.gg/fqKm8GJ9jj

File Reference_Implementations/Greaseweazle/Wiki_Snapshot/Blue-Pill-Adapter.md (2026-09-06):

**NOTE: If you received a pre-assembled adapter then
you can skip straight to [Hardware Setup](Hardware-Setup).**

**NOTE: If you received a pre-programmed kit then
you can skip straight to [Through-Hole Assembly](#through-hole-assembly).**

- [Parts List](#parts-list)
- [SMT Assembly](#smt-assembly)
- [Through-Hole Assembly](#through-hole-assembly)
- [Firmware Programming](Firmware-Programming)

## Parts List

Directly connecting a "Blue Pill" to your floppy drive requires the
following parts:
- STM32 "Blue Pill" board
- Adapter PCB
- 2.54mm-pitch Male Header Pins
- 4 x 0805 1k resistors

The "Blue Pill" is available very cheaply from many Chinese Ebay
sellers for less than £2 including postage. The best search term is
"*STM32F103C8T6 board*", sorted by lowest price first, and look for a
board identical to below.

**UPDATE**: Please be aware of [fake STM32 chips](STM32-Fakes) flooding
the Chinese market. You may be advised to use a local source for your
Blue Pill: For example, in UK they can be purchased for £3-4, you can more
easily question a local seller, and you have wasted much less time if
your chip does turn out to be fake.

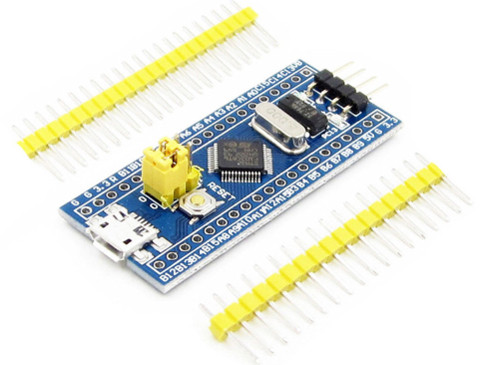
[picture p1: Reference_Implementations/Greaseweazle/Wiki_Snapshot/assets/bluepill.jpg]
STM32 Blue Pill


Two types of adapter PCB are available: One for 34-pin PC-compatible
floppy drives, the other for 26-pin 3-inch Amstrad drives (used in CPC
and Spectrum +3).

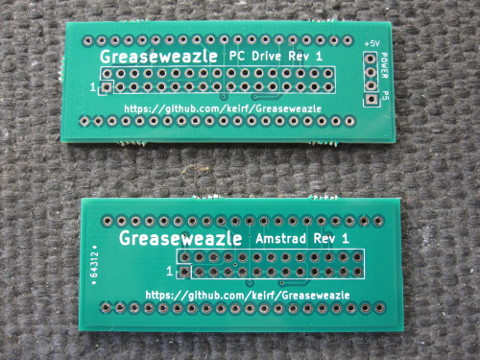
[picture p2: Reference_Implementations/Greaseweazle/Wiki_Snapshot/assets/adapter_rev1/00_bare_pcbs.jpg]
STM32 Blue Pill Adapters


You can have the PCBs made yourself:

**DirtyPCBs:** The simplest method, using a [direct purchase
link][dirtypcbs] and costing approximately $25 in total. Once the
design is added to your cart, be sure to increase the *Size* to
*10x10*, or your order will be rejected! You can also choose *Color*,
and optionally increase *Thickness* to *1.6mm* without increasing
purchase cost. Your order will yield 10 PCBs, each containing 4 PC
34-pin adapters and 1 Amstrad 26-pin adapter: 50 in total!

**Custom order (Gerbers):** The Gerber sources for the 10x10cm panel
as in the above DirtyPCBs store link can be downloaded
[here](assets/adapter_rev1/F1_10x10_Gerbers.zip).

**Custom order (KiCad):** The original KiCad PCB design is available in my
[PCB Projects git repository][pcbprojects]. The single-board PC design
is available under *greaseweazle/*, the Amstrad design under *gw-26/*, and
the five-to-a-panel design (as in the DirtyPCBs store link) is under
*panels/GW*. You will need to use KiCad to generate Gerbers.

## SMT Assembly

Solder four 1k 0805 resistors to the adapter PCB, skipping the
location marked **USBPU**.

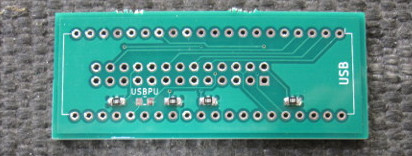
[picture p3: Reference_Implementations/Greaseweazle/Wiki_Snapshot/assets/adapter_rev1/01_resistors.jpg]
Blue Pill resistors


## Through-Hole Assembly

Solder male header pins to the floppy and power headers
(note that the power header is omitted on the Amstrad adapter). On the
PC adapter board I recommend that you remove header pin 5, as in the
picture below (be careful of orientation and pin numbering!). This
picture also illustrates use of a Berg power
connector in place of 1x4 header pins.

Be careful to solder the pins straight: You may wish to solder one pin
on each header, then heat that pin while ensuring the header is correctly
seated. It is very hard to adjust after all pins are soldered!

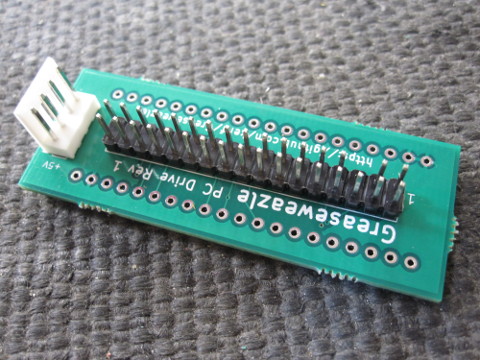
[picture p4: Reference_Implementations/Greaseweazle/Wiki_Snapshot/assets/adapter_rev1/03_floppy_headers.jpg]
Adapter Headers


Now solder the pair of 20-pin header strips to the Blue Pill, making
sure they are straight, and solder the Blue Pill to the reverse side
of the adapter board. Please note:
* The Blue Pill is a tight fit to the adapter: Make
sure the pins are lined up, and expect to press firmly.
* Be careful not to press the Blue Pill fully flush with
the adapter as you will risk shorting the backsides of the two boards
against each other: Instead leave a small clearance of 1-2mm.
* Be sure to install your Blue Pill the right way round: The USB end is
marked on the adapter.

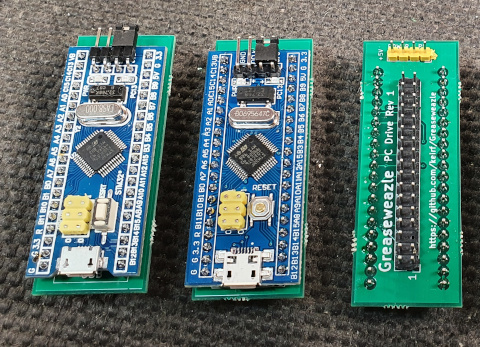
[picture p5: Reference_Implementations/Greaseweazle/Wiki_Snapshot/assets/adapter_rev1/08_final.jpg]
Final result


Ensure that the boot jumpers are both set to 0, otherwise the
Greaseweazle firmware will not run at power on. Note in the picture above
that this setting has been soldered on the underside of the Blue Pill, and
the boot jumper pins have been cropped: You do not need to do this.

[dirtypcbs]: https://dirtypcbs.com/store/designer/details/keirfraser/6387/greaseweazle-rev-1-panel
[pcbprojects]: https://github.com/keirf/pcb-projects

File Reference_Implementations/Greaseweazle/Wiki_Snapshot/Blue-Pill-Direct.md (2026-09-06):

- [Parts List](#parts-list)
- [Firmware Programming](#firmware-programming)
- [Floppy Drive](#floppy-drive)
- [Host PC](#host-pc)

This method is *deprecated** and **unreliable** due to use of weak
Dupont connections. Do not expect support if your direct-connection
setup doesn't work!

## Parts List

Directly connecting a "Blue Pill" to your floppy drive requires the
following parts:
- STM32 "Blue Pill" board
- Dupont jumper wires (Female-Female)

The "Blue Pill" is available very cheaply from many Chinese Ebay
sellers for less than £2 including postage. The best search term is
"*STM32F103C8T6 board*", sorted by lowest price first, and look for a
board identical to below.

**UPDATE**: Please be aware of [fake STM32 chips](STM32-Fakes) flooding
the Chinese market. You may be advised to use a local source for your
Blue Pill: For example, in UK they can be purchased for £3-4, you can more
easily question a local seller, and you have wasted much less time if
your chip does turn out to be fake.

STM32 Blue Pill

## Firmware Programming

Before programming your Blue Pill board you should solder the supplied
header pins.

Please see the [Firmware Programming page](Firmware-Programming) for
further instructions.

## Floppy Drive

You can connect the Blue Pill to any floppy drive implementing a Shugart
interface: Old PC 3.5-inch and 5.25-inch drives are a good choice,
or an Amstrad 3-inch drive for Amstrad CPC and Spectrum +3 disks.
Note that the drive need not be the same model as in the system
to which the disks belong: a Shugart drive is a Shugart drive, and
it only really matters that it takes the correct size physical media.

3.5-inch drives typically require only 5v power and can be supplied
directly from the 5-volt pin on the Greaseweazle board. Older
5.25- and 3-inch drives typically are more power hungry and require 12v
power too: These you must connect to a separate power source.

Connections are as follows, for a PC 34-pin drive and for an
Amstrad 26-pin drive:

| GW Pin | Signal | PC Pin | Ams Pin |
|---|---|---|---|
|  B9 | DENSEL | 2 | - |
|  B6 | INDEX  | 8 | 2 |
|  B10 | SELECT |  12 | 4 |
|  B11 | MOTOR  |  16 | 8 |
|  B12 | DIR |  18 |  10 |
|  B13 | STEP |  20 |  12 |
|  B4 | DKWD |  22 |  14 |
|  B14 | DKWE |  24 |  16 |
|  B7 | TRK0 |  26 |  18 |
|  B8 | WRPROT |  28 |  20 |
|  B3 | DKRD |  30 |  22 |
|  B15 | SIDE |  32 |  24 |

Odd numbered pins may be connected to Ground on the Greaseweazle board.
It is mandatory to connect at least one odd-numbered pin if you are
using an external power source for your floppy drive, to connect the
ground planes of Greaseweazle and the drive.

See the following diagram showing the Dupont jumper connections.

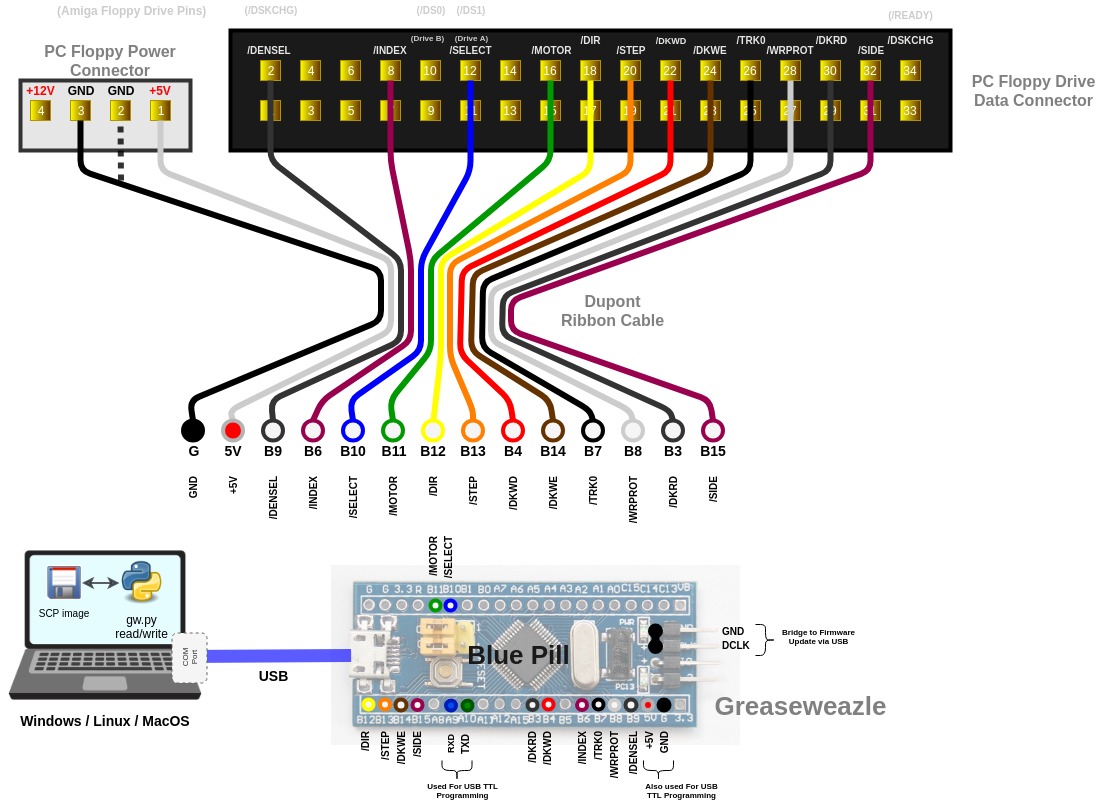
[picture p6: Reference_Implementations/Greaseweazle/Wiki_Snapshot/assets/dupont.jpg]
Connection with Dupont wires


[FULL RESOLUTION DIAGRAM HERE][hires]

In the above example please note that no odd-numbered 34w pins need be
connected to **GND** as grounds are already connected via the power
connector. This would not be the case if using an external power
source.

## Host PC

Connect to your host PC (Linux, Mac, Windows, etc) using a normal USB cable.
Greaseweazle appears as a serial or modem device, depending on your OS.

[hires]: https://github.com/keirf/greaseweazle/wiki/assets/dupont.jpg

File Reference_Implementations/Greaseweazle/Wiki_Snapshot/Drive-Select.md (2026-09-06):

Greaseweazle supports Shugart and IBM/PC multi-drive setups<sup>1</sup>.

The **read** and **write** commands both accept option `--drive N`
where **N** is one of **A**, **B**, **0**, **1**, or **2**. Note that **N**
is not case sensitive: **a** and **b** are also accepted.

The default is **A** (IBM/PC Drive A) requiring an IBM/PC drive and
a "cable with a twist" (see the explanation below). If your drive fails
with a *Track 0 not found* error, you may have:
- A Shugart drive, strapped for DS0 (pin 10): Connect with straight ribbon and use `--drive 0`
- A PC drive being used with a straight cable: Use `--drive b`

**Note:** Greaseweazle F1 does not support multiple drives and any specified non-default
drive letter will be ignored.

### A,B: IBM/PC



In IBM/PC mode the Greaseweazle header acts the same as on a PC
motherboard: Two drives may be connected, each with an independent motor-enable
line. All PC drives are strapped for drive-select DS1 (pin 12),
and a cable twist is used to differentiate between drives **A** and **B**:
- **A**: Drive connected via a cable with twist on pins 10-16
- **B**: Drive connected via a straight ribbon cable

A two-drive cable will have connector(s) before and after a twist,
as shown.

### 0,1,2: Shugart

Up to three drives may be connected, with drive-select lines DS0-DS1 on
pins 10, 12 and 14 respectively. All drives share a common motor-select
signal on pin 16. Drives are addressed by drive identifiers **0**, **1**,
and **2**.

### Summary

The diagrams below summarise the use of pins 10-16 on the respective buses.
Click for full-size.




1. Except Greaseweazle F1 (basic Blue Pill model).

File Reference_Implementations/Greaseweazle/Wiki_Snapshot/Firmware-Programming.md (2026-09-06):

**NOTE: If you have a pre-assembled Greaseweazle device, or a kit
with the MCU pre-soldered, then it is already programmed and
you should skip this section!!**

- [**Programming V4 Devices via USB-DFU**](#programming-v4-devices-via-usb-dfu)
- [**Programming F1 and F7 Devices via ST-Link**](#programming-f1-and-f7-devices-via-st-link)

## Programming V4 Devices via USB-DFU

**WARNING:** All V4 devices are sold pre-programmed and end users should
only need to perform [firmware updates](Firmware-Update). However, the
reflashing process is documented here in case a V4 device is ever somehow
"bricked".

Firstly, the V4 board must be jumpered for programming mode:
- **V4:** Place a jumper across DFU and 3V3 pins on the 12-pin header block
- **V4 Slim:** Place a jumper across the BOOT pins on the 6-pin header block

Download and install the [ArteryISP software][arteryisp] (Windows
only) via the **Program and Debug** -> **ISP Programmer** download
link.

Download the latest firmware release from [here][dlfw].

Connect your V4 board to the Windows host machine, and run the ArteryISP
software.
- Select Port Type **USB DFU**
- Confirm that the V4 board is found and listed
- Click **Next** until you reach the screen including **Download to device**
- Click **Download to device**
- Click **Add** and select the **at32F4** hex file in the **hex/** subfolder of the firmware release
- Click **Next** and then **OK** at the read-protection warning that is shown
- Click **Close**, disconnect the V4 board, remove the programming jumper

## Programming F1 and F7 Devices via ST-Link

**WARNING:** Do not connect to the Greaseweazle USB port during
programming. Greaseweazle is powered by your programmer:
bad things may happen if you simultaneously provide USB power.

Programming requires an ST-Link v2 programmer, clones of which are
available cheaply on Ebay. The clones are recommended over the
official programmer because they are much cheaper, and because they
also power the board during programming; the official programmer requires
the Greaseweazle to be powered separately.

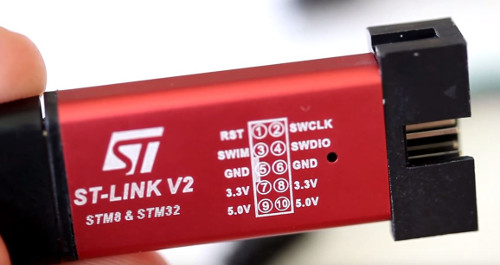
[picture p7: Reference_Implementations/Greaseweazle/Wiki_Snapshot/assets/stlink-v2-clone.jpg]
Example ST-Link v2 clone


Connect the programmer to the **DEBUG** header of the F7 board, or the
right-angle four-pin header of the Blue Pill board:

Programmer | Blue Pill | F7 DEBUG
-----------|-----------|----------------
SWCLK | DCL | CK
SWDIO | DIO | DIO
GND   | GND | GND
3.3V  | 3.3 | 3V3<sup>1</sup>
1. F7 PCB Rev 1: Pin is named VCC

**WARNING: Do not connect to the programmer's **5.0V** pin as you
will destroy your STM32 chip!**

**Windows:**
- Download the latest firmware zip file from [here][dlfw].
- Download and run the ST-Link software ([STSW-LINK004](https://www.st.com/en/development-tools/stsw-link004.html)).
- Connect your ST-Link programmer (**not** Greaseweazle!) to your Windows PC via USB.
- Click **Connect to the target** in the ST-Link software.
- Click **Open file**, navigate to the **hex/** subfolder, and open the correct hex file for your board
  - **f1** hex file for Blue Pill, **f7** hex file for F7 boards
- Click **Program verify**

**MacOS / Linux:**
- Download the latest firmware zip file from [here][dlfw].
- Install [stlink](https://github.com/stlink-org/stlink): `brew install stlink`
- Connect your ST-Link programmer (**not** Greaseweazle!) to your Mac via USB.
- Identify the correct hex file for your board in the **hex/** subfolder
  - **f1** hex file for Blue Pill, **f7** hex file for F7 boards
- Write the file: `st-flash --reset --format ihex write filename`
- Ensure no errors were reported

[arteryisp]: https://www.arterychip.com/en/support/tools.jsp
[dlfw]: https://github.com/keirf/greaseweazle-firmware/releases/latest

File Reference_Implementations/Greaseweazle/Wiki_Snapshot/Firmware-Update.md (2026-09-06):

The Greaseweazle host tools may sometimes require newer firmware
to be programmed into the Greaseweazle device.

Firmware update requires no hardware jumper (except the F1 model, discussed
separately [below](#f1-update-procedure)).
Simply run the update command on your host PC, for example:
```
gw update
```

In the unlikely event that your Greaseweazle is not recognised by your
PC, or otherwise fails to accept the update command, you can force
Greaseweazle into update mode:
- Disconnect USB
- Place a jumper across the **TXO/RXI** pins of the **UART** header
- Connect to USB
- Run the update command
- Disconnect USB and remove the jumper

It is also possible, but not generally recommended, to
[update the bootloader](#bootloader-update-procedure).

## F1 Update Procedure

Before connecting Greaseweazle F1 to your host PC, install a jumper across
**GND** and **DCLK** pins on the 4-pin header situated at one end of the
Blue Pill board, as indicated in the following diagram.

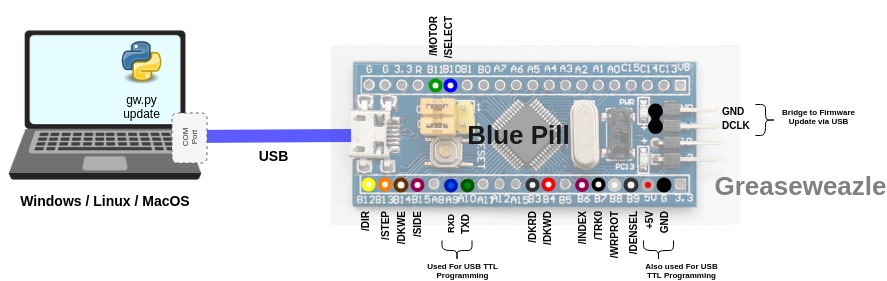
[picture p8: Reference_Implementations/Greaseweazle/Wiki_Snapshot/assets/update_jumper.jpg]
Jumper connection diagram


When you connect Greaseweazle it will now run its built-in
**Update Bootloader**. You can update the firmware to the latest
version from the host PC:
```
gw update
```

On report of successful update you should disconnect Greaseweazle
and then remove the Programming Jumper (**DCLK**-**GND**).

[hires]: https://github.com/keirf/greaseweazle/wiki/assets/dupont.jpg

## Bootloader Update Procedure

**WARNING: An error while updating the bootloader firmware can
brick your device, and require full manual
[Firmware Reprogramming](Firmware-Programming)!!**

Note that it is **NOT** usually necessary to update your bootloader.
Unlike the main firmware it does not need to be version-matched to the
host tools, and it does not sprout new features or bug fixes. If it ain't
broke, don't fix it!

With that said, the process is very similar to a normal update, except that
it is done with the device in normal mode rather than update mode. Thus it
is not necessary to jumper your F1 device.
```
gw update --bootloader
```

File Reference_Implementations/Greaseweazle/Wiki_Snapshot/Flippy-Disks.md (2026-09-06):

Several 8-bit home computers used 5.25" drives with a single read head
but used both sides of the disk to store data, requiring the user to
*flip* the disk to access side B. Double-sided drives
with two heads cannot read both sides in one pass, for two reasons:
1. The second drive head is offset inwards by several tracks, such that
the outer tracks on side B of a flippy disk are inaccessible.
2. The side-B tracks which the double-sided drive *can* read will appear
to be recorded backwards.

The obvious solution is to physically flip the disk, as in the original
system. However if you try this you will receive the error
`Command Failed: GetFluxStatus: No Index`. This is because the index
hole in the disk jacket is in the wrong position for the drive sensor
when the disk is flipped. There are a few possible solutions, which are
also summarised on page 7 of the
[Kryoflux flippy-drive manual][kryoflux_manual]:
1. Punch a second index hole in the disk jacket in the correct flipped
position. This will require removal of the inner disk media from its
jacket.
2. Fake the index pulse signal using Greaseweazle. This requires a drive
which will spin up in the absence of index pulses (many will not).
3. Modify a drive to include a second index sensor (see PDF guides
[here][adafruit] and [here][cowlark]). This allows to select the
correct index sensor based on a switch setting on the modified drive.
4. Obtain a flippy-modded disk drive which can read both sides of a
flippy disk in a single pass.

### Faking the index pulse

First measure the precise rotation speed of your drive by placing a
disk in the drive and running `gw rpm --nr 10`. The
RPM values should be relative constant for every measurement.

Now you can flip the floppy disk in your drive as you would do on
the original hardware and use the following command prefix: `gw read
--fake-index --tracks h=0 ...`. For example, to read a raw single-sided
image of side B:
```
gw read --fake-index 300 --tracks h=0 --drive 0 --raw test.scp
```

### Flippy-modded disk drive

This requires a specially-modified drive as originally specified by
the [Kryoflux project][kryoflux_manual]. You can then read flippy disks
in a single pass, for example (including C64 half tracks):
```
gw read c=0-79:h=0,1:h1.off=-8 test.scp
```

Note that side B will be read backwards in this case. Conversion software
will need to be aware of this.

[adafruit]: https://cdn-learn.adafruit.com/downloads/pdf/flippy-floppy-drive-modification.pdf
[cowlark]: http://cowlark.com/fluxengine/doc/Index_sensor_mod_FDD_1.1.pdf
[kryoflux_manual]: https://www.kryoflux.com/download/kf_525modded_manual.pdf

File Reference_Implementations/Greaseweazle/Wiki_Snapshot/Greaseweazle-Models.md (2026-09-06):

- [Overview](#overview)
- [Features](#features)
- [Gallery](#gallery)
- [Previous Models](#previous-models)

## Overview

There are three MCU lines supported by Greaseweazle, with hardware
identified as follows:
- **F1**: Based on the STM32F103 MCU and the "Blue Pill"
development board.
- **F7**: Based on the STM32F730 MCU and custom PCB,
available in a range of models.
- **V4**: Based on the AT32F4xx MCUs and custom PCB, available in a range
of models.

## Features

**Feature** | F1   | F1 Plus | F7 Lightning Plus | V4.1
------------|------|---------|-------------------|------
Jumperless Update |    | Yes | Yes | Yes
Multiple Drives  |     | Yes | Yes | Yes
Write-Protect Jumper | | Yes | Yes | Yes
Buffered Outputs |     | Yes | Yes | Yes
High-Speed USB   |     |     | Yes |    
12v Power        |     | Yes | Yes |    
Flippy Drive     |     | Yes | Yes | Yes
Disk Change Detect |   | Yes | Yes | Yes
User Outputs | 1 | 3 | 3 | 3

**Multiple Drives:** Allows simultaneous connection
to two PC, or three Shugart, drives on a single ribbon cable. Useful for
cased installations.

**Write-Protect Jumper:** Physically disables write capability, making it
impossible to accidentally overwrite disks during preservation.

**Buffered Outputs:** Higher (40mA) output drive capability, needed for
older floppy drives with strong input pull-ups (resistance <1kOhm).

**High-Speed USB:** 480Mbps bus transfer rate, compared with 12Mbps on
Full-Speed models. Provides greater bandwidth headroom and future
expandability. Not needed for floppy disks up to High Density data rates
(eg 1.44MB PC disks).

**12v Power:** Allows board and drive to be powered from a single 12v
power brick. These models are the only ones to directly support drives
requiring a 12v supply; other models require such drives to be separately
powered.

**Flippy Drive:** Supports [flippy-modded][fmyt] Panasonic drives for reading
5.25" *flippy disks* in a single pass. 

**Disk Change Detect:** Allows disk change signal to be monitored at floppy
interface pin 34. Used by projects such as Rob Smith's
[WinUAE Greaseweazle integration][rsmith].

**User Outputs:** User-configurable outputs. Useful for non-standard
control signals such as *reduced write current* (8" drives).

## Gallery

Model | Picture
------|--------
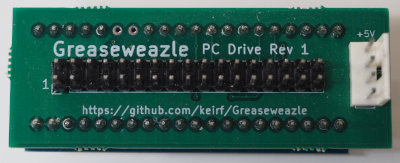
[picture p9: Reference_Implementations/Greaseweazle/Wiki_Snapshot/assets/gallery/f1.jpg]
F1
F1 | 
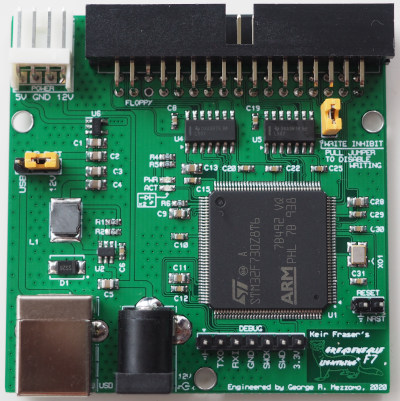
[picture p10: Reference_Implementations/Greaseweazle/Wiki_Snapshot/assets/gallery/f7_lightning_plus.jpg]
F7 Lightning Plus
F7 Lightning Plus | 
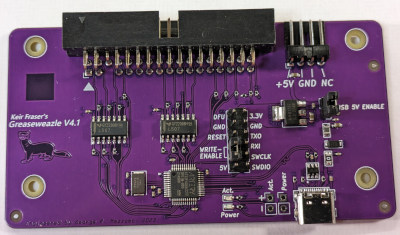
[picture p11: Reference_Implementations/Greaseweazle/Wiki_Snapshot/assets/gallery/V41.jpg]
V4.1
V4.1 | 

## Previous Models

These models are no longer available, but continue to be supported
by the Greaseweazle software. [Design files](Design-Files) are
available for DIY makers.

**Feature** | F7 v1 | F7 v2 | F7 v3 | F7 Plus | F7 Lightning | F7 Slim<sup>1</sup> | V4 | V4 Slim<sup>1
------------|-------|-------|-------|---------|--------------|---------------------|----|---------
Jumperless Update | Yes | Yes | Yes | Yes | Yes | Yes | Yes | Yes
Multiple Drives  | Yes | Yes | Yes | Yes | Yes | | Yes |
Write-Protect Jumper |     | Yes | Yes | Yes | Yes | Yes | Yes | Yes
Buffered Outputs |     | | Yes | Yes | Yes | | Yes |
High-Speed USB   |     | | | | Yes | | |
12v Power | | | | Yes | | | |
Flippy Drive | | | Yes | | | | Yes |
Disk Change Detect | | | Yes | | | Yes | Yes | Yes
User Outputs | 1 | 3 | 3 | 2 | 3 | 0 | 3 | 0
1. Slim models have 26-pin FFC connector, supporting slim-line 3.5-inch
laptop/embedded drives.

Model | Picture
------|--------
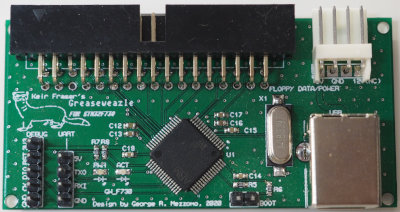
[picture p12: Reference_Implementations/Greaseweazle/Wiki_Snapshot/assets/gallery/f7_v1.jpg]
F7 v1
F7 v1 | 
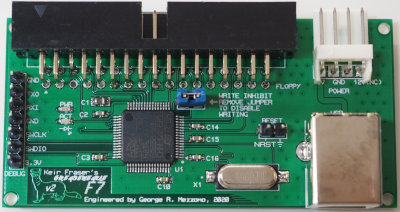
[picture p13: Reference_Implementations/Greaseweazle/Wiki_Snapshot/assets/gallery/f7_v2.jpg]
F7 v2
F7 v2 | 
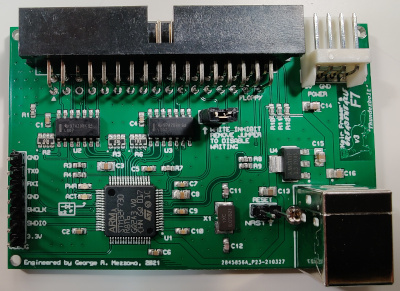
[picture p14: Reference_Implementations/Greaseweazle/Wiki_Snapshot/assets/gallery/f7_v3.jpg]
F7 v3
F7 v3 | 
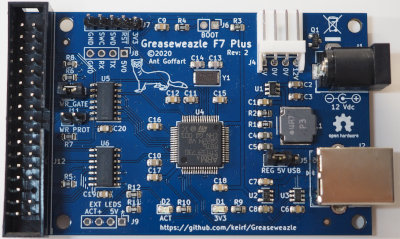
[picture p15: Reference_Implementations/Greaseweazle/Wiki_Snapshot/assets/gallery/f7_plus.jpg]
F7 Plus
F7 Plus | 
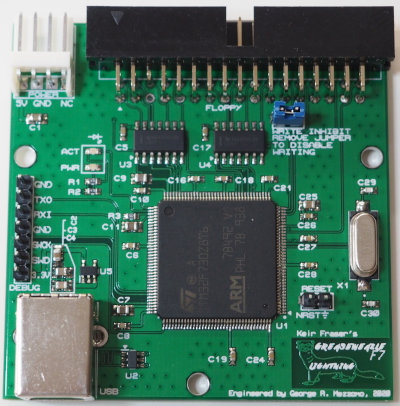
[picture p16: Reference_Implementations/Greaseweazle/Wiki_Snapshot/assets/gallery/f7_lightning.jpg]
F7 Lightning
F7 Lightning | 
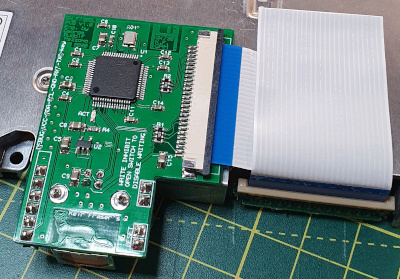
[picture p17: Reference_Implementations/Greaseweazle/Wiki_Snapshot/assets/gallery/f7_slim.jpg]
F7 Slim
F7 Slim | 
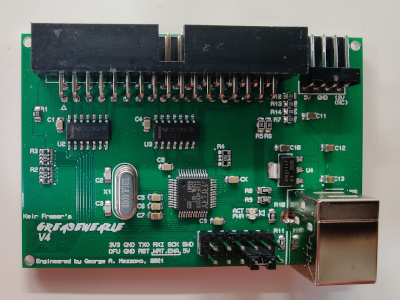
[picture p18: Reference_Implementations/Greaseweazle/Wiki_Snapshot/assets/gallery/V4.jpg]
V4
V4 | 

[fmyt]: https://www.youtube.com/watch?v=WcqluH7dEj4
[rsmith]: https://amiga.robsmithdev.co.uk/winuae

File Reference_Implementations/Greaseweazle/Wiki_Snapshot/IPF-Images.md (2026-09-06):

Greaseweazle optionally supports reading IPF image files via the CAPS/SPS
library, which must be installed in your Greaseweazle folder, or in a
standard system location.

On Windows the CAPS/SPS library is installed automatically alongside the
Greaseweazle executable. On other platforms the
library should be downloaded from the [SPS website][sps].

Please note that the library supports *read-only* access to IPF images: it
is not possible to create new IPF image files.

## Windows

Installed automatically. No further steps required.

## macOS

**Intel:**
1. Download version 4.2 for Mac OS X
([ipflib42_macosx-universal.dmg.zip][sps-mac]).
2. Copy the `CAPSImage.framework` folder to `/Library/Frameworks`.

**M1, M2 (ARM64):**
1. Download version 5.1 for Mac OS X on ARM64
([CAPSImg_5.1.3_macOS_ARM64.tar.xz][fsuae-macos]).
2. Copy the `CAPSImg.framework` folder to `/Library/Frameworks`.

When you first attempt to use the library you may see a dialog appear stating
*"CAPSImage.framework" cannot be opened because the developer cannot be
verified*. In this case:
1. Press **Cancel**
2. Run **Setting** -> **Security**. Click on **Allow Anyway**.
3. Run Greaseweazle again. If the dialog reappears, click **Open**.

## Linux

Download version 4.2 for 32-bit ([ipflib42_linux-i686.tar.gz][sps-linux32])
or 64-bit ([ipflib42_linux-x86_64.tar.gz][sps-linux64]) Linux as appropriate.
The file `libcapsimage.so.4.2` should be installed to a standard system-wide
location. For example (as root):
```
cp libcapsimage.so.4.2 /usr/lib
ldconfig
```
Alternatively set environment variable `LD_LIBRARY_PATH` to the location
of the library. For example, if the library is in the current working
directory:
```
export LD_LIBRARY_PATH=`pwd`
```

[sps]: http://softpres.org/download
[sps-w32]: http://softpres.org/_media/files:ipflib42_w32.zip
[sps-mac]: http://softpres.org/_media/files:ipflib42_macosx-universal.dmg.zip
[sps-linux32]: http://softpres.org/_media/files:ipflib42_linux-i686.tar.gz
[sps-linux64]: http://softpres.org/_media/files:ipflib42_linux-x86_64.tar.gz
[fsuae-macos]: https://fs-uae.net/download#macosx

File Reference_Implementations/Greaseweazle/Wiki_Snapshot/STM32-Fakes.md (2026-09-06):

Unfortunately in sourcing STM32 parts outside the proper retail channels
(ie. cheap Chinese sources on Ebay and AliExpress) we need to be aware
of fake chips being sold as STM32F103C8.

On this page I present a [Rogues' Gallery](#rogues-gallery) of fake
parts, describe how they are not equivalent to a proper STM32F103C8
part, and explain how to test your own STM32 parts and "pill"
development boards.

## Testing your Pill

Greaseweazle includes a Blinky test firmware in the **alt/** subfolder.
When written to a correct and working Blue Pill board, this firmware will
flash the PC13 LED once per second (ie. LED toggles every 500ms).

At the same time, a test diagnostic is logged to the serial line at
115200 baud, 8n1. On failure you can use this, if interested, to work out
which parts of the chip are bad or missing. Note that serial output is on
the programming interface at pins **A9** and **A10**: Not via the USB port!

All chips in the [Rogues' Gallery](#rogues-gallery) fail the Blinky test.

## Good STM32F103C8

First note that the chip must have "STM32F103C8" written on it. If the text
says anything different then the part is probably fake, or less powerful,
or both. The text fills the top of the chip, and there is one circular
depression, indicating the pin-1 corner of the chip.

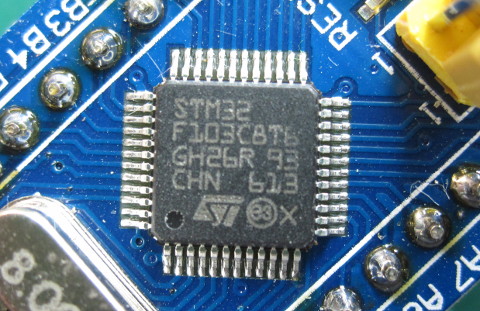
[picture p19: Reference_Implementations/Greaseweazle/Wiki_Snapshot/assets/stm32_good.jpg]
Good STM32F103C8


## Rogues' Gallery

### STM32FEBKC6

This chip was found on a Blue Pill sold as "STM32F103C8T6". This chip is
up front about its fakeness: "STM32FEB" is a Chinese clone of the genuine
STM32, while "KC6" indicates a low-density part with missing features.

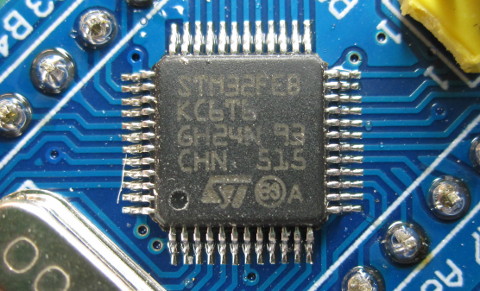
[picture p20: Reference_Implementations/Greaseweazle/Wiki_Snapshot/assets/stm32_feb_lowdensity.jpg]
Low-density fake


### Fake STM32F103C8

Harder to spot, this bad fake has been found on cheap Blue and Black Pills
alike. Note the physical differences from a genuine part in the side-by-side
shot below: There are extra circular depressions on the chip surface, and the
writing is smaller. However note that there are also physical variations 
among genuine chips, and the only way to be sure is to run Blinky.

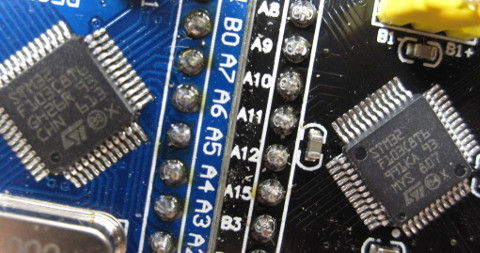
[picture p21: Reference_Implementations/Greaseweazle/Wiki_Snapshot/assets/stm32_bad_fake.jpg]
Bad fake


Of course this part fails Blinky. Although it seems to have all the required
peripherals present on the chip, it does not work properly in many ways.
These are differences from the genuine part that I found in my testing:
- Cannot program at 921600 baud. Success at 115200 baud.
- Cannot start firmware from System Bootloader (Bootloader may not set the Reset SP?)
- Debug registers return valid non-zero info (contravenes Erratum 2.3 of genuine parts)
- Writing to backup registers, and then turning off the backup interface clock, seems to lock up parts of the chip: Future writes to certain registers hang forever with no exception or reset
- I2C peripheral won't allow CR1_ACK to be set in the same write that sets CR1_PE
- DMA peripheral generates spurious extra completion interrupts and is generally prone to lockup

## Fakes Which Pass Blinky

### CS32F103

This clone (which probably also appears in remarked chips posing as genuine
STM32F103) actually passes Blinky and seems to work okay in general. Note that
this chip fixes Erratum 2.3 of genuine STM32F103 (return values from debug
registers) and thus can be detected as a clone part.

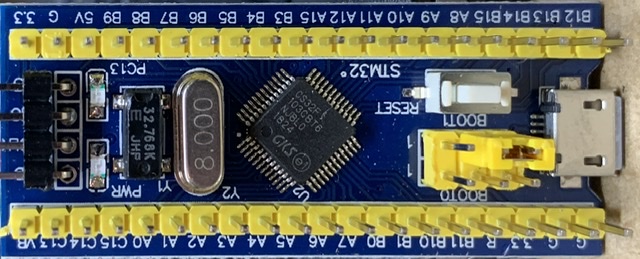
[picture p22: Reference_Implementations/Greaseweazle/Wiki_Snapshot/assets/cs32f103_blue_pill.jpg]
Good fake


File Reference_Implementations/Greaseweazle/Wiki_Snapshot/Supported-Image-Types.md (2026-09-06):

## Sector Image Types

Supported for read and write, with automatic verification:
- ADF (Commodore Amiga, 880k and 1760k; Acorn ADFS)
- ADS, ADM, ADL (Acorn ADFS)
- DSD, SSD (Acorn DFS)
- [DSK, EDSK](#edsk-imd-td0) (Amstrad CPC; Also used by Spectrum +3, SAM Coupé, and others)
  - Automatically disambiguated from raw-sector DSK by header signature
- D64 (Commodore 64 1541 GCR)
- D71 (Commodore 64 1571 GCR)
- D81 (Commodore 64 1581 MFM)
- HDM, XDF (PC-98)
- [IMD](#edsk-imd-td0) (IBM Sectors)
- [IMG, IMA, DSK](#img-ima-dsk) (Generic suffixes for IBM FM/MFM Raw Sector)
- MGT (Sinclair ZX Spectrum DISCiPLE/+D, SAM Coupé)
- MSA, ST (Atari ST)
- SF7 (Sega SF-7000)

#### IMG, IMA, DSK

These formats store the payload data of all sectors back-to-back, in
logical order, with no separators and no metadata.

The sectors appear in increasing logical order of Track #, Head #,
Sector #. Physical layout attributes such as sector interleave are
not represented in these image files.

For example on a double-sided, 80-track, 9-sectors format, the order
of sectors in the file will be:

- T0 H0 S1, T0 H0 S2, ..., T0 H0 S9
- T0 H1 S1, T0 H1 S2, ..., T0 H1 S9 
- ...
- T79 H1 S1, ..., T79 H1 S9

Since these image types do not describe the physical disk and track
layout, they can only be handled by Greaseweazle in concert with a
specified `--format`.

#### EDSK, IMD, TD0

These formats contain an image header and additional metadata which
describes the physical layout and identificatoon of sectors within
each track. This will include attributes such as: Track #, Head #,
Sector #, and checksum.

Thus, unlike the headerless image types described above, these formats
can represent physical attributes such as sector interleave and skew,
and some simple copy protections (bad checksum, unusual sector ids,
and so on).

Greaseweazle can import these image types without need of a specified
`--format`, because they are sufficiently self-describing.

## Import-Only Image Types

Supported only for importing existing images. Can be written to disk
with automatic verification:
- D88, DCP, DIM, FDI, NFD (PC-98)
- IPF (Universal 'Golden Image' Format)
- [TD0](#edsk-imd-td0) (IBM Sectors)

## Raw Image Types

Universal raw image types supported for read and write, no automatic
verification:
- HFE (Raw Bitcells, 1 revolution per track)
- [Kryoflux](#kryoflux) (Raw Flux, multiple revolutions per track)
- SCP (Raw Flux, multiple revolutions per track)

These can be used or analysed in several ways:
- WinUAE, FS-UAE (Universal Amiga Emulator): Directly support SCP files
- [Disk-Utilities][du]: A command-line analyser and transcoder
- [HxC Software][hs]: A GUI visualiser, analyser and transcoder

Import-only (existing image to disk):
- A2R (Applesauce 3.x Raw Flux)

#### Exporting raw flux

Please note that by default `gw read` will re-generate flux when you
specify `--format`. To export
raw flux directly from the disk you *must* specify both `--raw` and
`--format`, or neither. For example:
```
gw read --format=ibm.720 not_raw_flux.scp
gw read --format=ibm.720 --raw really_raw_flux.scp
```

If you specify a `--format` but not `--raw`, the file will store
digitally regenerated "perfect" flux data, and bad sectors will be
filled with `==[BAD SECTOR]==` data. This is probably not what you
want when saving raw flux data!

#### Kryoflux

Kryoflux stream files are supported for both import and export. This
files are stored one per track in the form `name<track>.<side>.raw`. For
example: name00.0.raw, name00.1.raw, ..., name79.1.raw.

To specify a set of Kryoflux stream files to Greaseweazle, simply pass
the name of any one individual file. For example:
```
gw read --tracks=c=0-39 name00.0.raw
```

[du]: https://github.com/keirf/Disk-Utilities/blob/master/README.md
[hs]: https://hxc2001.com/download/floppy_drive_emulator/HxCFloppyEmulator_soft.zip

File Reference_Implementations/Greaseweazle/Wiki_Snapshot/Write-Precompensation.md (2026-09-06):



When writing to a disk, some or all tracks can have **write precompensation**
applied. This technique compensates for the tendency for consecutive flux
transitions to interact and cause them to spread apart. The effect is
particularly noticeable on inner tracks where the bit density is highest.

The precomp specifier is presented by **--precomp=** and can
contain any of the following elements:
- **type=\<t\>**: Precomp type (**mfm**, **fm**, **gcr**): Default **mfm**
- **\<c\>=\<p\>**: Precompensate all cylinders >= **c** by **p** nanoseconds.

For example:
- `40=125`: Apply 125ns MFM precompensation to cylinders 40 and higher

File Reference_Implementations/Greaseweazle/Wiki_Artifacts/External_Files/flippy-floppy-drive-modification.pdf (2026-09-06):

# Flippy Floppy Drive Modification

Created by Jeff Epler

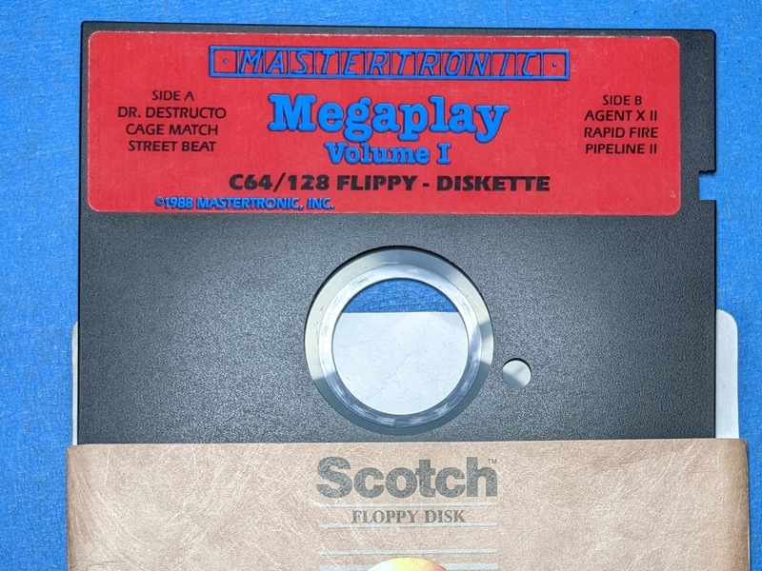
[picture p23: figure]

https://learn.adafruit.com/flippy-floppy-drive-modification

Last updated on 2024-06-03 03:34:20 PM EDT

©Adafruit Industries | Page 1 of 14

3

6

10

13

## Table of Contents

Overview
- Why is a modification required?
- Parts
Modify Your Drive
- Perform a Quick Test
3D Printing & Assembly
- Replacement bezel with opening for slide switch
Using your Modified Drive
- Using the modification
- Copying a normal double-sided disk
- Copying the front side of a single-sided or flippy disk
- Copying the back side of a flippy disk
- Writing the back side of a flippy disk

# Overview

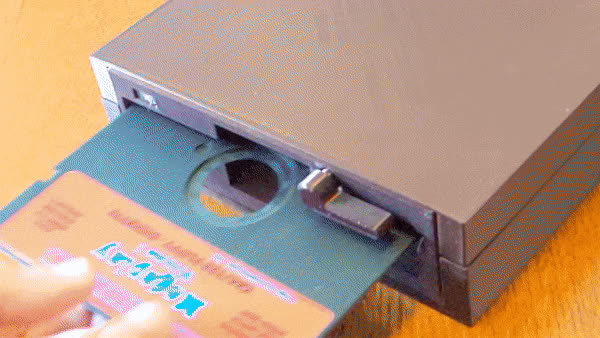
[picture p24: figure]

Some classic 8-bit systems' floppy drives (notably: Apple, Atari, Commodore) did not have an index sensor and had only one read head. As a consequence, it was possible to flip a floppy over and use it to store additional data, a capability used by commercial software and home users alike. These were called "flippy floppies" or "flippies".

But! You can't read the flip side of these disks in an unmodified PC drive, even if you're using archival software like FluxEngine or GreaseWeazle. This guide shows a self-contained and reversible modification for TEAC FD55-GFR drives that enables you flip your floppies like it was the 80s again, and get both sides backed up.

## Why is a modification required?

Because PC drive electronics require the index pulse, the second side of flippy disks can't be read with unmodified PC drives (except for some extremely uncommon disks with two index holes). The second read head doesn't help, because the two heads are offset; the second read head's "track 0" is not the same as the first read head's.

While the procedure outlined here is intended to be safe and reversible, there's always a risk of damage when modifying electronics.


However, it is possible to modify many floppy drives to supply an alternate revolution sensor, and then read the second side of flippy floppies! The method here is based on a procedure proposed by the author of fluxengine, David Given (http://cowlark.com/fluxengine/doc/Index_sensor_mod_FDD_1.1.pdf) (https://adafru.it/YDR) and is for TEAC FD55-GFR drives. The general principle can be applied to other drives, but these instructions are specific to the TEAC FD55-GFR. Even among TEAC FD55-GFR drives there is some variation as PCBs were revised over the drive's lifetime (my drive's main PCB is marked SAN-S294VO or maybe SAN-S294V0). Additionally, there are drives with similar names (such as TEAC FD55 with no -suffix) that are quite different.

However, with care you can apply this technique to various other drives as long as you can locate

+5V
GND
The existing revolution signal, which must be open-collector, not push-pull

Our method is a little different than David Given's, because we made ours fully reversible. However, a consequence of the fully reversible version is that you have to turn off the new sensor using the switch whenever inserting a disk "right side up".

You'll find other methods proposed on the internet, including ones that make modifications to the metal frame of the disk to increase the range of motion and copy both disk sides with a single operation. If you're up to it, check out some other options and then do the one that is best for you! Otherwise, pick up the components below and let's get started soldering (https://learn.adafruit.com/flippy-floppy-drive-modification/soldering) (https://adafru.it/YDS).

•
•
•

## Parts


Reflective Infrared IR Optical Sensor with 470 and 10K Resistors (https://www.adafruit.com/product/2349)
This Reflective IR Sensor is a simple plastic casing with two elements - an IR LED and an IR phototransistor. You can control the IR LED and turn it on to bounce IR...
https://www.adafruit.com/product/2349


Breadboard-friendly SPDT Slide Switch (https://www.adafruit.com/product/805) These nice switches are perfect for use with breadboard and perfboard projects. They have 0.1" spacing and snap in nicely into a solderless breadboard. They're easy to switch...
https://www.adafruit.com/product/805


Silicone Cover Stranded-Core Wire - 50ft 30AWG Black (https://www.adafruit.com/product/3164)
Silicone-sheathing wire is super-flexible and soft, and its also strong! Able to handle up to 200°C and up to 600V, it will do when PVC covered wire wimps out. We like this wire...
https://www.adafruit.com/product/3164


Silicone Cover Stranded-Core Wire - 50ft 30AWG Red (https://www.adafruit.com/product/3165)
Silicone-sheathing wire is super-flexible and soft, and its also strong! Able to handle up to 200°C and up to 600V, it will do when PVC covered wire wimps out. We like this wire...
https://www.adafruit.com/product/3165

Silicone Cover Stranded-Core Wire - 50ft 30AWG Blue (https://www.adafruit.com/product/3166)
Silicone-sheathing wire is super-flexible and soft, and its also strong! Able to handle up to 200°C and up to 600V, it will do when PVC covered wire wimps out. We like this wire...
https://www.adafruit.com/product/3166


# Modify Your Drive

If your drive is in an enclosure, take it out. Disconnect any power and data cables and lay it on a work surface upside down, so that the side with the spindle motor (a large aluminum disk) is facing up.

Take black "electrical" tape and wind it around the spinning motor assembly, leaving a gap of about 1/4 inch (6mm) or so in the circle. If needed, trim excess tape away and make sure the spindle still spins freely.


It may help to first transfer your tape from a large roll to a smaller diameter tool such as the shaft of a screwdriver as shown in the image, so that it can be positioned right next to the drum and unrolled. No matter which tape you use, it is most important to cover the side of the drum all the way to the bottom (PCB side), because of how the sensor will sit. Leave any gaps at the top of the drum.

The author found that 1/2 inch (12mm) tape was a bit wide, but that after winding the part that stuck above the drum could be trimmed back with a utility knife. 1/4 inch (6mm) tape is a bit narrow and care has to be taken to position it vertically for the sensor to function properly. The perfect tape width might be 3/8 inch (9mm), but the author didn't receive any in time for testing.
Next, it's time to do some soldering. Solder the 470 ohm resistor between the two center legs of the sensor, then solder wires for GND, +5V, and the signal switch. Use generous lengths of wire at each point, because the wire must route around the inside of the floppy drive and to the front panel. Check out the photos below to get an idea of how much wire you'll need and where to route it.


Fritzing sketch for the above image (https://cdn-learn.adafruit.com/assets/assets/000/117/620/original/flippy-sensor.fzz?1674571326) https://adafru.it/18eL


On the Adafruit sensor, model H048W, the sensor side is indicated with a transistor symbol on the left in this photo and corresponds to the side marked "S" above. The emitter side on the right is marked with a diode symbol and corresponds to the side marked "E" above.


Using an M2.5x10 screw and nut, affix the sensor to the drive in the location shown. Leave a 1mm gap between the motor and the sensor. By moving it gently with your fingertips, make sure the drive motor can still rotate freely 360 degrees. If not, you may need to adjust the sensor position in its slot, or re-apply the black tape.
If you do need to re-apply the tape, it's recommended to use fresh tape each time.

Solder the VCC, GND, and switch signals to the main PCB as shown:

Red VCC to J5-5
Black GND to J5-2

•
•


Blue switch output to TP-1


Carefully route your wires so that they cannot interfere with the floppy spindle motor. You can route them under the PCB on the side with the ribbon cable, or use the retaining clip for the stepper motor's ribbon cable.

## Perform a Quick Test

Plug everything in and perform a little test using fluxengine.

Call the switch position on the un-soldered side the NORMAL position and the other position the FLIPPY position.

Put the switch in the NORMAL position, insert a floppy right side up, and run fluxengine rpm . Your drive's rotational speed, usually around 360rpm, should be

•

printed. If you get a lower number, make sure the tape and sensor are not interfering with the rotation. If you get a "no index pulse" error, your wiring is incorrect.

Pull the floppy out, turn it over, and reinsert it. Put the switch in the FLIPPY position
and run | fluxengine rpm | again. Your drive's rotational speed, again around
360RPM, should again be printed. If you get a "no index pulse" error, your wiring is incorrect or incomplete. If you get a wildly higher rotational speed, your black tape or sensor positioning is not good.

Hopefully everything was just fine and you're ready to 3D print a fresh bezel for your drive. (https://learn.adafruit.com/flippy-floppy-drive-modification/3d-printing-assembly) (https://adafru.it/YDP)

# Good result

$ ./fluxengine rpm
Rotational period is 167.475 ms (358.262 rpm)

# Bad result -- too slow. Check if motor spins freely

$ ./fluxengine rpm
Rotational period is 442.19 ms (135.688 rpm)

# Bad result - too fast (too many pulses). Check wiring &amp; switch $ ./fluxengine rpm

Rotational period is 143.998 ms (416.673 rpm)

# Bad result - no pulses. Check wiring &amp; switch

$ ./fluxengine rpm
Error: GreaseWeazle error: No index

# 3D Printing & Assembly


## Replacement bezel with opening for slide switch

This modification is super tidy when you print your own bezel with a spot for the slide switch. Print one 525cut.stl, from the file below, in the color of your choice, face up, with supports touching build plate.

525cut.stl is based on 5.25 TEAC drive face plate by jerryt74332 (https://www.thingiverse.com/thing:4003832) (https://adafru.it/YDM) but with an added opening for Adafruit's Breadboard-friendly SPDT Slide Switch (https://www.adafruit.com/product/805) (http://adafru.it/805). The extra opening was added to the original STL file using the Free & Open Source "OpenSCAD (https://openscad.org/) (https://adafru.it/XD4)" program, available for Linux, Windows, and Mac. The OpenSCAD file is included with the models for printing, which may be useful if you want to reposition or resize the opening for the slide switch.

Optionally, also print:

led.stl from 5.25 TEAC drive face plate by jerryt74332 (https://www.thingiverse.com/thing:4003832) (https://adafru.it/YDM), in "clear" or "natural" filament
drive-lever-Body.stl in the color of your choice. The drive lever is modeled after the original lever using the Free & Open Source "FreeCAD (https://www.freecad.org/) (https://adafru.it/YGA)" program, available for Linux, Windows and Mac. The design file "drive-lever.FCstd" is included with the models for printing. If the knob doesn't go on properly or is too loose, change your slicer's "horizontal expansion" in small steps to get a good friction fit.
floppycase-Body.stl and floppycase-Body1.stl, a two-part 5.25" drive enclosure

3D Models For Printing on
Thingiverse (https://www.thingiverse.com/thing:5336383)
https://adafru.it/Zfd
3D Models for Printing on
Printables (https://www.printables.com/model/158541-teac-525-drive-case)
https://adafru.it/Zfe

•

•

•


Gently press the LED diffuser and slide switch into their openings, enlarging the openings slightly with a file if needed. If desired, or if the parts feel loose, add a dab of hot glue on the back to secure them. Note which side the un-soldered contact on the switch is; this will be the NORMAL position. In the photo here, the position towards the middle of the bezel is NORMAL.


Pull the lever gently but firmly out to remove it. Then remove two screws on the bottom of the face plate. Slide the original face plate off. Reverse these steps to mount your new face plate and install the new lever, noting the orientation of the "D"-shaft.


Make sure you haven't disturbed the wiring during this process, then continue on to use your modified drive (https://learn.adafruit.com/flippy-floppy-drive-modification/3d-printing-assembly) (https://adafru.it/YDP).

If the plain jane floppy enclosure isn't for you, you can also check out Adafruit's own case for 5.25 inch floppy disk drives (https://learn.adafruit.com/floppy-case) (https://adafru.it/YDQ).

# Using your Modified Drive


## Using the modification

When you installed the switch in the new bezel (or other location of your choice), you noted which of the 3 terminals of the switch didn't have a wire soldered to it. This is the NORMAL position, and your drive will operate as usual. The other position is the FLIPPY position, which links the output of the added sensor into the drive's control circuitry. Once you've established which is which, it's a great idea to add a small sticker or mark so that you don't have to remember it forever.

Sample command lines for are shown below, but the mod is also tested with and is expected to work with other host software as well.

Greaseweazle (https://github.com/keirf/greaseweazle/wiki/) (https://adafru.it/YDU)
FluxEngine (https://cowlark.com/fluxengine/) (https://adafru.it/YDV)

## Copying a normal double-sided disk

Use this mode for capturing true double sided formats, like ibm360_525 or ibm1200_525. Slide the switch to NORMAL and insert the disk face up:

fluxengine read ibm360_525 -o diskname.img

•
•

## Copying the front side of a single-sided or flippy disk

Use this mode for capturing the front side of a disk, or the back side of the (rare!) flippy disk with two index holes. Slide the switch to NORMAL and insert the disk face up. If using a "head specification", select head 0 only.

fluxengine read commodore1541 -h 0 -c 0-79x2 -o diskname-s1.d64

## Copying the back side of a flippy disk

Use this mode for capturing the second side of a flippy disk. Set the slide switch to FLIPPY and insert the disk face down. If using a "head specification", select head 0 only.

fluxengine read commodore1541 -h 0 -c 0-79x2 -o diskname-s2.d64

## Writing the back side of a flippy disk

I didn't test it, but this mod should also enable writing to the second side of a flippy disc.

This requires a write-enable notch on the left hand side of the disk (or a second write-protect-ignore modification, not documented here). Set the slide switch to FLIPPY and insert the disk face down. If using a "head specification", select head 0 only.

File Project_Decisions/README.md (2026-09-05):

# Project Decisions

This directory is the project's non-authoritative engineering notebook. It records significant project choices and their rationale, including important alternatives where useful.

Each record should identify the decision, context, alternatives considered, rationale, consequences, and relevant references.

Records in this directory do not override `Requirements.md`. When a project choice changes a requirement or the current design, update `Requirements.md` or `Design.md`, as applicable.

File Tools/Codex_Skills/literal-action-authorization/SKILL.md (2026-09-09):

---
name: literal-action-authorization
description: Interpret user messages in context and distinguish questions, imperative instructions, and ambiguous requests before changing files, settings, repositories, applications, or external state.
---

# Contextual Action Authorization

Use conversational context to understand the request while keeping authorization explicit when wording or consequences make it necessary.

## Interpretation process

1. Read the message together with the relevant preceding conversation.
2. Classify it as an unambiguous question, an unambiguous imperative instruction, or ambiguous between those meanings.
3. Answer questions without performing the action being discussed.
4. Follow imperative instructions only within their explicit scope.
5. Treat ambiguous wording as a question. Explain what is possible and wait for an imperative statement before changing state.

Context can resolve references such as “it,” “that change,” or “the previous plan.” It cannot supply missing authorization when the wording remains genuinely ambiguous.

A topic label, hypothetical, preference, or discussion of proposed work is not an instruction. Read-only inspection may be used when necessary to answer accurately, provided it does not perform the action being discussed.

## Destructive-action boundary

Do not delete, overwrite, discard, publish, push, deploy, install system-wide software, change permissions, control the desktop, or perform another destructive, irreversible, privileged, externally visible, or difficult-to-recover operation unless the user gives an imperative statement authorizing that specific action and target.

Authorization for one action does not imply authorization for related actions such as staging, committing, pushing, publishing, installing, deleting, sending messages, deploying, or controlling the desktop.

## Examples

- “Can you repair this file?” → If both a polite request and a capability question remain plausible, explain whether it can be repaired; do not edit it.
- “Please repair this file.” → Repair it within the stated scope.
- “We discussed the repair. Go ahead with it.” → Perform the previously defined repair.
- “Would deleting the cache solve this?” → Answer the question; do not delete it.
- “Please delete only the generated cache directory.” → Resolve that directory precisely, then delete it.
- “Should this be committed?” → Recommend whether to commit; do not stage or commit.
- “Please commit these changes locally.” → Stage and create the local commit; do not push unless separately instructed.

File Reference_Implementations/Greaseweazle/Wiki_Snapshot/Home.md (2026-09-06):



**Greaseweazle** is a USB device and host tools allowing versatile
floppy drive control. By extracting the raw flux transitions from a
drive, any disk format can be captured and analysed: PC, Amiga,
Amstrad, PDP-11, musical instruments, industrial equipment, and
more. Greaseweazle also supports writing to floppy disks, from a range
of image file formats including those commonly used for online
preservation (ADF, IPF, DSK, IMG, HFE, ...).

### [Purchase a Greaseweazle][Purchase]
### [Download the Host Tools][Download]

### Greaseweazle V4.1 Users

Please read the V4.1-specific [setup page](V4.1-Setup) for discussion of the
V4.1 board and how to connect to a floppy drive.

### Redistribution

Greaseweazle source code, and all binary releases, are freely redistributable
in any form. Please see the [license][COPYING].

[Purchase]: https://github.com/keirf/greaseweazle/wiki/Purchase-a-Greaseweazle
[Download]: https://github.com/keirf/greaseweazle/wiki/Download-Host-Tools
[COPYING]: https://github.com/keirf/greaseweazle/blob/master/COPYING

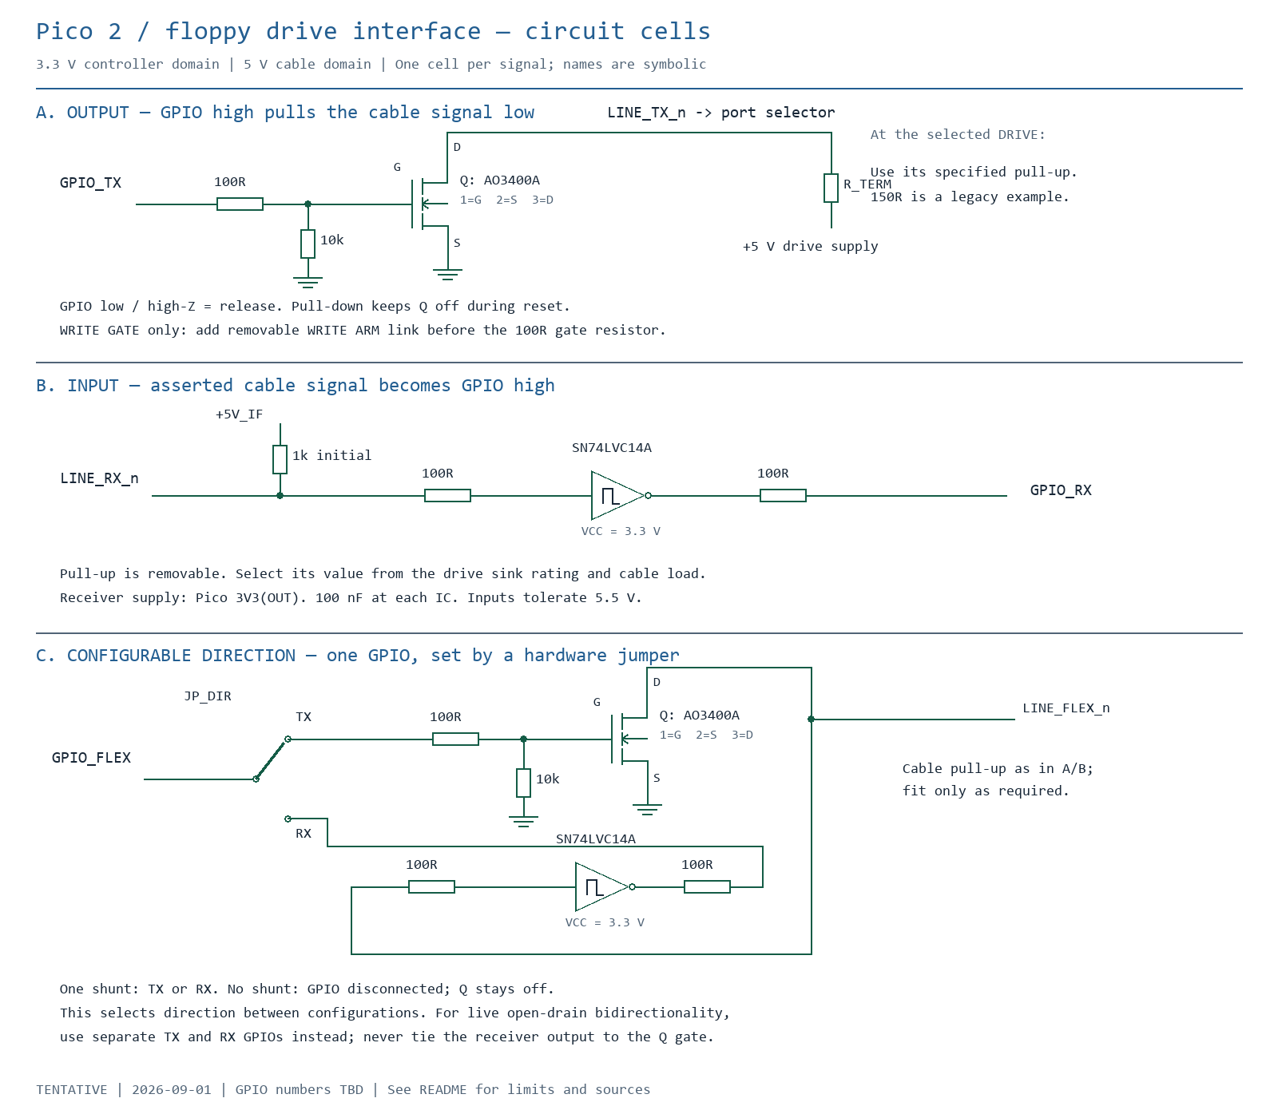
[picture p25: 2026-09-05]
Project_Decisions/0001-pico2-poc-electrical-proposal/interface-cells.png

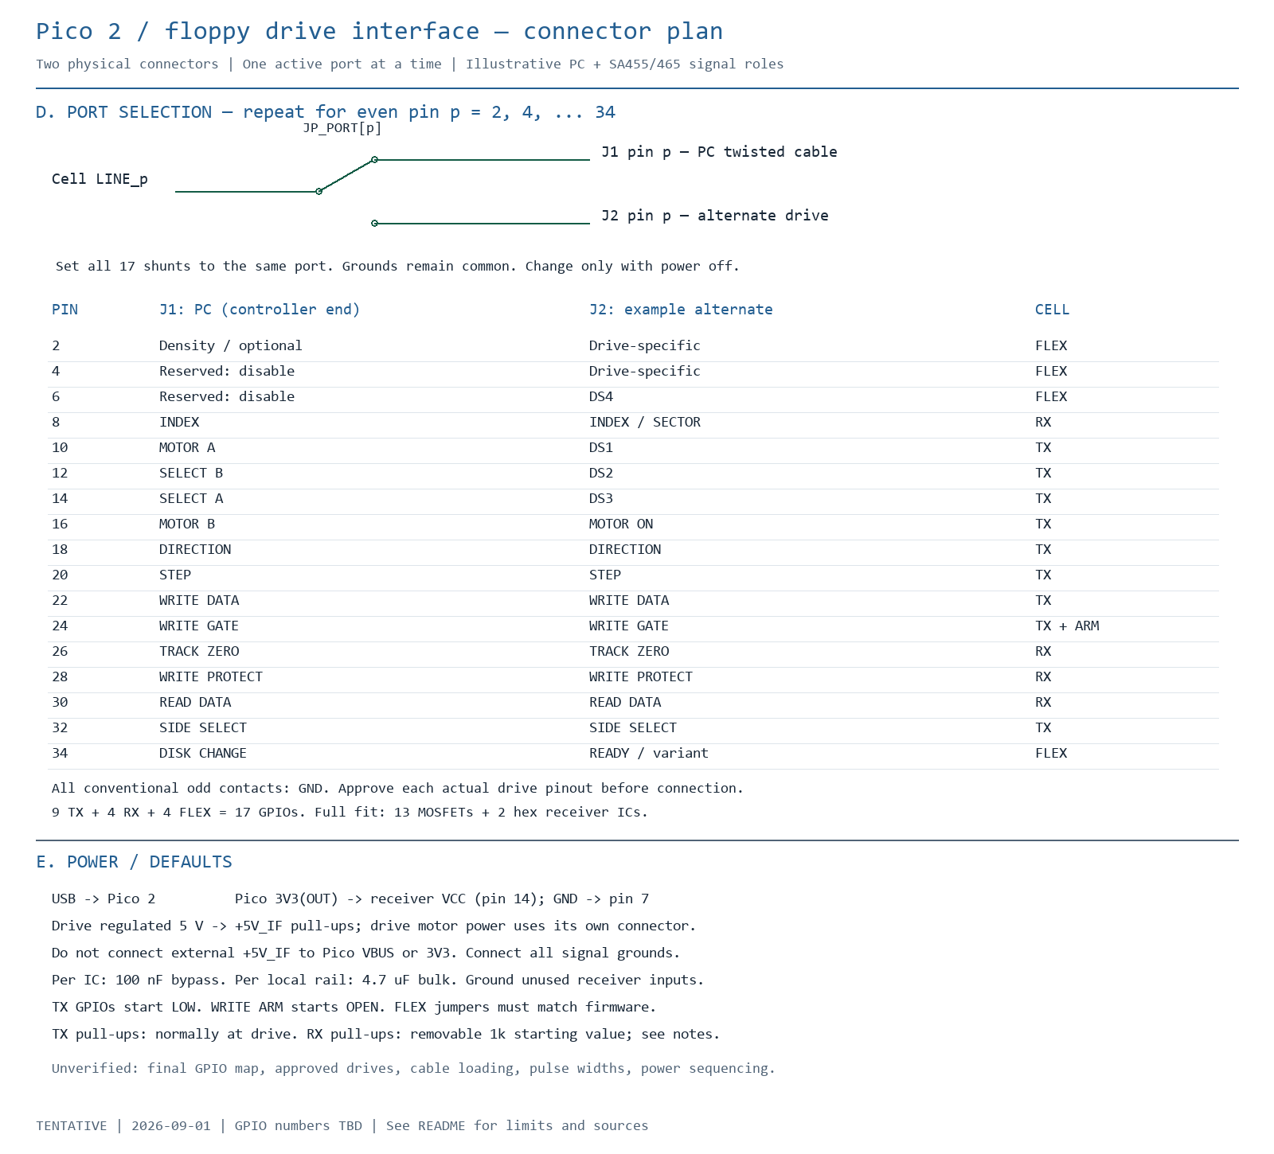
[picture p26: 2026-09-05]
Project_Decisions/0001-pico2-poc-electrical-proposal/connector-map.png

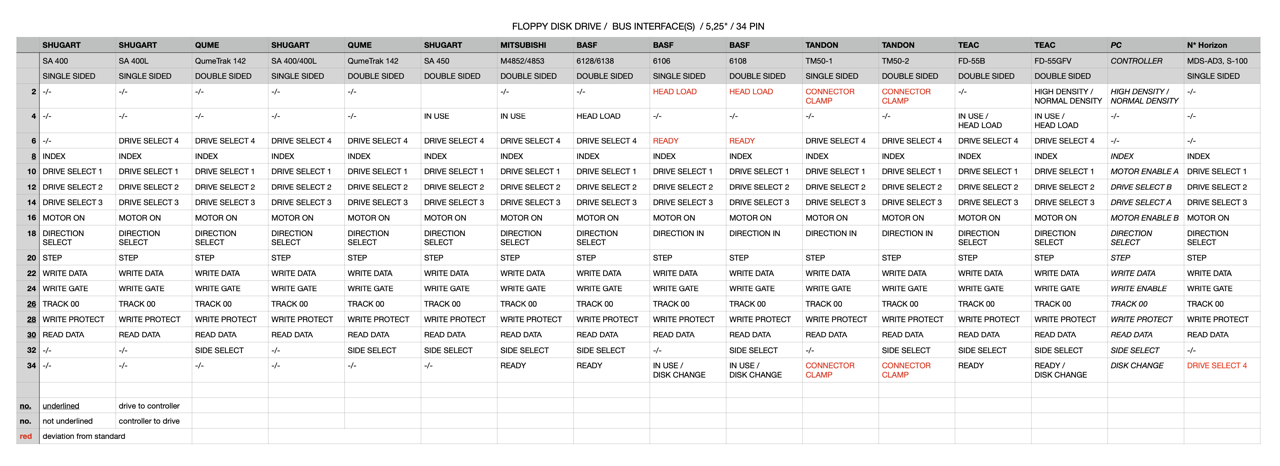
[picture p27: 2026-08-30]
Reference_Documentation/Pinouts/fdd-bus-interface-34p.png

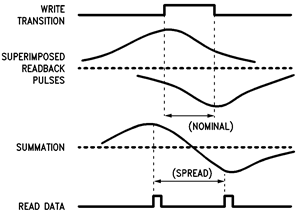
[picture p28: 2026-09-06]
Reference_Implementations/Greaseweazle/Wiki_Snapshot/assets/bit-shift.png

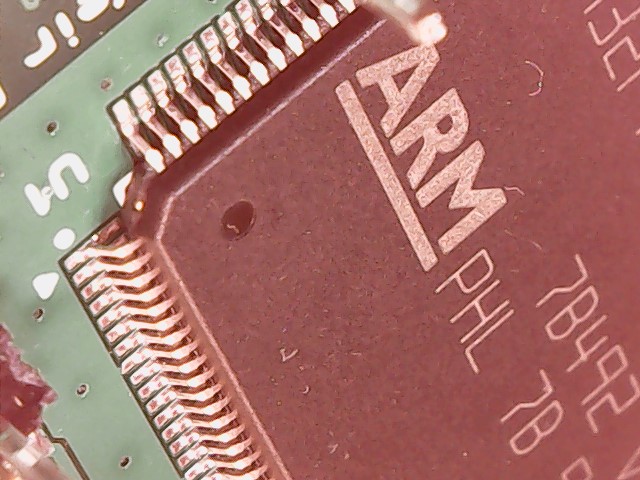
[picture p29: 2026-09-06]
Reference_Implementations/Greaseweazle/Wiki_Snapshot/assets/f7_lightning_plus/WIN_20200910_11_55_07_Pro.jpg

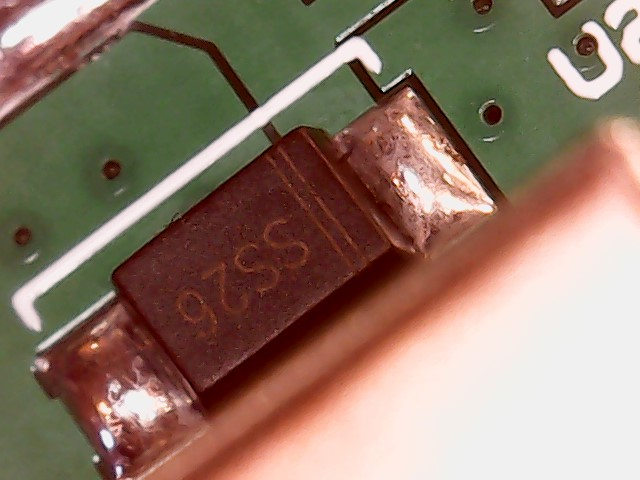
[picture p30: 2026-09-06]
Reference_Implementations/Greaseweazle/Wiki_Snapshot/assets/f7_lightning_plus/WIN_20200910_11_38_08_Pro.jpg

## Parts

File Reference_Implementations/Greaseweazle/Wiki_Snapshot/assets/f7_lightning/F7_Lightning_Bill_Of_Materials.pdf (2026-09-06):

## Bill Of Materials for Greaseweazle F7 Lightning

Design Title | Greaseweazle F7 Lightning
Author | George Rudolf Mezzomo
Document Number | 01
Revision | 1.1
Design Created | terça-feira, 19 de novembro de 2019
Design Last Modified sábado, 23 de maio de 2020

### Total Parts In Design 55

30 Capacitors
Quantity | References | Value | PCB Package
3 | C1,C4,C12 | 10u | CAPC2012X100_MOD
4 | C2-C3,C14,C25 | 1.0u | CAPC2012X100_MOD
18 | C5-C6,C8,C10,C13,C15-C24,C26-C28 | 100n | CAPC1608X87_MOD
3 | C7,C9,C11 | 2.2u | CAPC2012X100_MOD
2 | C29-C30 | 27pF | CAPC1608X87_MOD
Sub-totals:
11 Resistors
Quantity | References | Value | PCB Package
2 | R1-R2 | 470 | 0603
1 | R3 | 3.00K | 0603
5 | R4,R8-R11 | 1.0K | 0603
3 | R5-R7 | CAY16-103J4LF | CAY16-103J4LF
Sub-totals:
5 Integrated Circuits
Quantity | References | Value | PCB Package
1 | U1 | STM32F730Z8T6 | QFP50P2200X2200X160-144N
1 | U2 | USBLC6-2SC6 | SOT95P280X145-6N
2 | U3-U4 | 7407 | SO14
1 | U5 | AP2112K-3 | SOT95P282X130-5N
Sub-totals:
9 Miscellaneous
Quantity | References | Value | PCB Package
2 | ACT,PWR | DIODE-LED | 0603
1 | DEBUG | CONN-SIL7 | CONN-SIL7
1 | FLOPPY | 10056845-134LF | CON34_2X17_R2_FCI
1 | POWER | CONN-H4 | CONN-SIL4
2 | RESET,WRITE INHIBIT | CONN-SIL2 | CONN-SIL2
1 | USB | 61729-0010BLF | 617290010BLF
1 | X1 | ABLS-16 | ABLS
Sub-totals:

Totals:

| | | terça-feira, 26 de maio de 2020 05:33:31

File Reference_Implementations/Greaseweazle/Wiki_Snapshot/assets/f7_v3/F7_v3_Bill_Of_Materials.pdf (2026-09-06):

# Bill Of Materials for Greaseweazle F7 Thunderbolt

Design Title | Greaseweazle F7 Thunderbolt
Author | George Rudolf Mezzomo
Document Number | 01
Revision | 1.0
Design Created | 10 February 2020

## Design Last Modified 25 March 2021 Total Parts In Design 41 16 Capacitors

Quantity | References | Value
8 | C1-C2,C4-C7,C9-C10 | 100n
1 | C3 | 4.7u
2 | C8,C15 | 1.0u
2 | C11-C12 | 30pF
3 | C13-C14,C16 | 10u
Sub-totals:

## 12Resistors

Quantity | References | Value
5 | R1,R7,R10-R12 | 1.0K
3 | R2,R5-R6 | CAY16-103J4LF
3 | R3,R8-R9 | 3k
1 | R4 | 4K7
Sub-totals:

## 4 IntegratedCircuits

Quantity | References | Value
1 | U1 | STM32F730R8T6
2 | U2-U3 | 7407
1 | U4 | LD1117S33
Sub-totals:

## 9Miscellaneous

Quantity | References | Value
2 | ACT,PWR | DIODE-LED
1 | DEBUG | CONN-SIL7
1 | FLOPPY | 10056845-134LF
1 | POWER | CONN-H4
2 | RESET,WRITE INHIBIT | CONN-SIL2
1 | USB | 61729-0010BLF
1 | X1 | X50328MSB2GI
Sub-totals:
Totals: | 25 March 2021 11:32:40

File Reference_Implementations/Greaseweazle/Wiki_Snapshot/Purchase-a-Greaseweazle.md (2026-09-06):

Official retail links for fully-assembled Greaseweazles are listed below.

  - UK:
    - Direct sales via my [ebay store][ebay] (Zero Flux Development)
    - [AmigaDeals][amigadeals]
    - [AmigaKit][amigakit]
    - Retro Ready: [webstore][retroready], [ebay][retroready-ebay]
    - [RetroEZ][retroez]
    - [RetroPassion][retropassion]
  - EU:
    - [amigastore.eu (ES)][amigastore]
    - [HobbyRetro (ES)][hobbyretro]
    - [Retro-Updates.com (NL)][retro-updates-nl]
    - [Sordan (IE)][sordan] (also available [with case][sordancase])
    - [ultimateMiSTer (PT)][mister] (free shipping coupon: **KEIRFRASER**)
  - North America:
    - [Decromancer][decromancer]
    - Emmy Bear: [ebay][eba-ebay], [tindie][eba-tindie]
  - Australia:
    - [RetroKit][retrokit-au]

Although listed by region, most resellers will ship worldwide.

[f7plusbuy]: https://sellmyretro.com/offer/details/43881
[ebay]: https://www.ebay.co.uk/usr/zeroflux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
[sordan]: https://sordan.ie/product/1527/newest-greaseweazle-v41-usb-floppy-adapter-flux-reader-writer/
[sordancase]: https://sordan.ie/product/1530/greaseweazle-v41-usb-floppy-adapter-flux-reader-writer--case/
[mister]: https://ultimatemister.com/product/greaseweazle-v4-usb-floppy-adapter-flux-reader-writer
[amigadeals]: https://www.amigadeals.com/products/greaseweazle-v4-1
[amigakit]: https://www.amigakit.com/greaseweazle-p-91322.html
[retroready]: https://retroready.one
[retroready-ebay]: https://www.ebay.co.uk/sch/i.html?_ssn=retro_ready_one
[retroez]: https://www.retroez.com/store/Greaseweazle-V4-USB-Floppy-Adapter-Flux-Reader-Writer-p381405857
[retropassion]: https://www.retropassion.co.uk/product/greaseweazle/
[eba-ebay]: https://www.ebay.com/str/emmybeararcadeshackerlan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
[eba-tindie]: https://www.tindie.com/stores/emmybeararcades/
[amigastore]: https://amigastore.eu/en/894-greaseweazle-v4.html
[decromancer]: https://decromancer.ca/greaseweazle/
[hobbyretro]: https://hobbyretro.com/en/retro/greaseweazle-v4-usb-floppy-adapter-flux-reader-writer
[retro-updates-nl]: https://www.retro-updates.com/product/11583377/greaseweazle-v4-usb-floppy-adapter-flux-reader-writer
[retrokit-au]: https://www.retrokit.com.au/product/greaseweazle-v4/

## Greaseweazle Merch

T shirts and other merchandise are available via Spreadshirt, shipping from
the EU and USA. These shops make no profit for the project; they exist
just for fun and to spread the Greaseweazle word!

 - EU shop: [greaseweazle.myspreadshop.co.uk](https://greaseweazle.myspreadshop.co.uk/all)
 - USA shop: [greaseweazle.myspreadshop.com](https://greaseweazle.myspreadshop.com/all)

Further notes:
1. The EU shop is a UK domain with UK pricing. However the shirts are
manufactured in Germany. Hence there will be no import taxes to pay
when shipping within the EU.
2. Conversely, UK shipping may attract
import tax if the value is over £135. However Spreadshirt promise to
refund these taxes if you contact them.
3. The T Shirt design is
tested. I have not seen a hoodie or mug in the flesh. Send me pictures
if you order one!
4. Spreadshirt have various other garments and items available for
splashing with the Greaseweazle logo. Let me know if there are any
specific items you would like to see added from their range.
5. Finally: Always click the discount-code banner. (There always seems to
be one!)

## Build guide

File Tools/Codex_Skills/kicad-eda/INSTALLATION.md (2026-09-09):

# Local installation record

The maintained skill source is this directory. The normal installed copy is:

`%USERPROFILE%\.codex\skills\kicad-eda`

The optional official IPC client environment is:

`%USERPROFILE%\.codex\tools\kicad-eda-python`

The installer records exact package versions in `installed-packages.txt` inside that environment and verifies the installed skill against this source.
The reproducible package set is also committed as `requirements-ipc.txt`.

KiCad's bundled Python at `C:\Program Files\KiCad\10.0\bin\python.exe` supplies the matching `pcbnew` module for headless board construction. It is part of KiCad and is not copied into the Codex environment.

Approve KiCad CLI work outside the Codex sandbox using the exact installed `kicad-cli.exe` path. Scripts that invoke it must run as the normal Windows user; they intentionally stop when executed as `CodexSandboxOffline`. Outside-sandbox execution does not require Administrator elevation.

The maintained repository copy is authoritative. Reinstall by copying this directory to the personal skills directory and recreating the isolated environment from `requirements-ipc.txt`. The local copy and environment are deployment artifacts, not repository content.

To uninstall, remove only the installed skill directory and IPC environment shown above, then restart Codex. Project files and this maintained source are unaffected. KiCad itself is not modified by this skill installation.

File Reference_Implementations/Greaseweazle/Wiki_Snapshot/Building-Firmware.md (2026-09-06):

This project is cross-compiled on an x86 Ubuntu Linux system. However
other similar Linux-base systems (or a Linux virtual environment on
another OS) can likely be made to work quite easily.

To install the prerequisites:
```
sudo apt install git gcc-arm-none-eabi python3-pip srecord stm32flash zip
python3 -m pip install --user bitarray crcmod pyserial requests
```

To build the firmware, producing a distribution folder and zip
archive:
```
git clone https://github.com/keirf/greaseweazle-firmware.git
cd greaseweazle-firmware
make dist
```

If you wish to build firmware incrementally, for example for development
testing, then you can build all targets as follows (you can modify or
remove the `-j8` parameter to adjust build parallelism):
```
make -j8
```

You will now find HEX files for flashing at:
```
out/<mcu>/<level>/greaseweazle/target.hex
<mcu> := at32f4 | stm32f1 | stm32f7
<level> := debug | prod
```

You can flash the relevant HEX to your Greaseweazle via
serial or ST-Link. The `flash` and `ocd` build targets may be
useful for automatically doing this on Linux, via
serial adapter or OpenOCD/ST-Link.

If you require debug logging over the serial line at 3Mbaud then
use the HEX file within the relevant `debug` folder.

For example, to build and automatically flash the F7 firmware with
debug logging to an attached Greaseweazle via ST-Link and OpenOCD:
```
make -j8 ocd target=stm32f7/debug
```

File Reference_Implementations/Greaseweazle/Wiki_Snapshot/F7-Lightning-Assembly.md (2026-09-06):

**NOTE: If you received a pre-assembled adapter then
you can skip straight to [Hardware Setup](Hardware-Setup).**

- [Parts List](#parts-list)
- [Assembly Guidance](#assembly-guidance)
- [Firmware Programming](Firmware-Programming)

## Parts List

You should obtain (or have received) the following parts, in addition
to the Greaseweazle PCB. Note that kits may include
an excess quantity of the "passives" (resistors, capacitors).

Board Reference | Footprint | Value/Type | Quantity
----------|------|-------|---------
C1,C4,C12 | 0805 | 10uF  | 3
C2-C3,C14,C25 | 0805 | 1uF | 4
C5-C6,C8,C10,C13,C15-C24,C26-C28 | 0603 | 100nF | 18
C7,C9,C11 | 0805 | 2.2uF | 3
C29-C30   | 0603 | 27pF  | 2
 | | | 
R1-R2     | 0603 | 470R  | 2
R3        | 0603 | 3k0   | 1
R4,R8-R11 | 0603 | 1k0   | 5
R5-R7     | CAY16 | 10k   | 3
 | | | 
U1        | LQFP144 | STM32F730Z8 | 1
U2        | SOT23-6L | USBLC6-2SC6 | 1
U3-U4     | SOIC-14 | 74LS07 | 2
U5        | SOT25 | AP2112K-3 | 1
 | | | 
ACT,PWR   | 0603 | LED | 2
DEBUG | 7x1 | Pin Header | 1
RESET, WRITE_INHIBIT | 2x1 | Pin Header | 2
FLOPPY POWER | 4x1 | TE 171826-4 | 1
FLOPPY DATA | 17x2 | Box Header | 1
USB       | USB-B | | 1
X1        | HC-49/US | 16MHz | 1

## Assembly Guidance

Please note that the small size and pitch of some components, particularly
U1, means that you will need some soldering proficiency, and
equipment such as the following:
- A workbench with decent lighting
- Moderate magnification (eg. a magnifying bench light)
- Good quality leaded (60/40) solder (eg. Stannol, Kester)
  - **Avoid lead-free solder!**
- Plenty of flux
- Tweezers

Although not a step-by-step guide, I will note some caveats.

1. The kit comes with the STM32 chip placed in a fold of antistatic
material, taped to the PCB. Be warned, the chip will be loose when you
peel the tape!

2. The kit-supplied LEDs are manufacturer codes HSMS-C190 and
HSMY-C190.  The cathode terminal is marked by a *tiny* dot, and should
be oriented towards the right-hand side of the PCB.
You can find the manufacturer datasheet
[here](https://docs.broadcom.com/docs/AV02-0551EN).

3. You may wish to remove pin 5 and/or pin 3 from the FLOPPY DATA header.
Some floppy-drive cables use one of these pins as an orientation key.

4. The 10k resistor arrays are a little tight on their pads. Be careful
that they are correctly aligned.

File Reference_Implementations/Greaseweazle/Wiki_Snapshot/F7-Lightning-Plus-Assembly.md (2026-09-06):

**NOTE: If you received a pre-assembled adapter then
you can skip straight to [Hardware Setup](Hardware-Setup).**

- [Parts List](#parts-list)
- [Assembly Guidance](#assembly-guidance)
- [Firmware Programming](Firmware-Programming)

## Parts List

You should obtain (or have received) the following parts, in addition
to the Greaseweazle PCB. Note that kits may include
an excess quantity of the "passives" (resistors, capacitors).

Board Reference | Footprint | Value/Type | Quantity
----------|------|-------|---------
C2-C5,C14 | 0805 | 10uF<sup>1</sup>  | 5
C9,C11,C13 | 0805 | 2.2uF | 3
C1,C7,C17,28 | 0805 | 1uF | 4
C8,C10,C12,C15-C16,C18-C27,C29-C31 | 0603 | 100nF | 18
C6   | 0603 | 10nF  | 1
 | | | 
R1        | 0603 | 49.9k | 1
R2        | 0603 | 9.53k | 1
R3,R9-R11,R14 | 0603 | 1k0   | 5
R4 | 0603 | 470R | 1
R5-R6,R13,R15 | 0603 | 3k0   | 4
R7-R8,R12     | CAY16 | 10k   | 3
 | | | 
U1        | LQFP144 | STM32F730Z8 | 1
U2        | SOT23-6L | AP3211KTR-G1 | 1
U3        | SOT23-6L | USBLC6-2SC6 | 1
U4-U5     | SOIC-14 | 74LS07 | 2
U6        | SOT25 | AP2112K-3.3TRG1 | 1
 | | |
D1 | SMAF | SS22F, SS26F | 1
L1 | 5mmx5mm | 4.7uH 2A | 1
12V | PRT-00119 | PRT-00119 | 1
ACT   | 0603 | G-Y LED | 1
PWR   | 0603 | Red LED | 1
DEBUG | 7x1 | Pin Header | 1
RESET, WRITE_INHIBIT | 2x1 | Pin Header | 2
PWR_SLCT | 3x1 | Pin Header | 1
FLOPPY POWER | 4x1 | TE 171826-4 | 1
FLOPPY DATA | 17x2 | Box Header | 1
USB       | USB-B | | 1
XO1       | 4-SMD | ECS-3225MV-160 | 1
1. C5 must be rated 16V or higher

## Assembly Guidance

Please note that the small size and pitch of some components, particularly
U1, means that you will need some soldering proficiency, and
equipment such as the following:
- A workbench with decent lighting
- Moderate magnification (eg. a magnifying bench light)
- Good quality leaded (60/40) solder (eg. Stannol, Kester)
  - **Avoid lead-free solder!**
- Plenty of flux
- Tweezers

Although not a step-by-step guide, I will note some caveats.

1. The DIY kit comes with the STM32 chip placed in a fold of antistatic
material, taped to the PCB. Be warned, the chip will be loose when you
peel the tape!

2. The LED cathode terminal is marked by a green dot under the lens,
which should be oriented towards the right-hand side of the PCB.

3. You may wish to remove pin 5 and/or pin 3 from the FLOPPY DATA header.
Some floppy-drive cables use one of these pins as an orientation key.

4. The 10k resistor arrays are tight on their pads. Be careful
that they are correctly aligned.

5. Jumpers are required at WRITE_INHIBIT (to enable writes) and at
PWR_SELECT to select power from USB or external 12V supply.

6. Be careful not to use too much solder for the external oscillator (XO1).
It is easy to flood solder up the side of the can and short the device.
In this case the activity LED will flash three times repeatedly, at power
on. You will need to try wicking up the excess solder. It may be safer to
use hot air to attach XO1.

#### Assembly Video

With thanks to [Martijn Wieland](https://www.tsb.space/).

Lightning Plus assembly video (http://www.youtube.com/watch?v=bOUBt1eJvGM "Lightning Plus assembly video")

#### IC Orientations








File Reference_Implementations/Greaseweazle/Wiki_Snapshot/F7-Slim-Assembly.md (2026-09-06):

**NOTE: If you received a pre-assembled adapter then
you can skip straight to [Hardware Setup](Hardware-Setup).**

- [Parts List](#parts-list)
- [Assembly Guidance](#assembly-guidance)
- [Firmware Programming](Firmware-Programming)

## Parts List

You should obtain (or have received) the following parts, in addition
to the Greaseweazle PCB. Note that kits may include
an excess quantity of the "passives" (resistors, capacitors).

Board Reference | Footprint | Value/Type | Quantity
----------|------|-------|---------
C1-C2,C4,C6,C10-C14 | 0603 | 100nF | 9
C3        | 0805 | 4.7uF | 1
C5,C7-C8  | 0805 | 1uF   | 3
C9,C15    | 0805 | 10uF  | 2
 | | | 
R1-R2     | CAY16 | 10k  | 2
R4        | 0603  | 470  | 1
 | | | 
U1        | LQFP64 | STM32F730R8 | 1
U2        | SOT25 | AP2112K-3 | 1
 | | | 
ACT       | 0603 | LED | 1
DEBUG | 6x1 | Pin Header | 1
RESET, WRITE_INHIBIT | 2x1 | Pin Header | 2
FLOPPY DATA | 26x1mm | FFC Connector | 1
USB       | USB-B | | 1
XO1       | 4-SMD | ECS-3225MV-160 | 1

## Assembly Guidance

Please note that the small size and pitch of some components, particularly
U1, means that you will need some soldering proficiency, and
equipment such as the following:
- A workbench with decent lighting
- Moderate magnification (eg. a magnifying bench light)
- Good quality leaded (60/40) solder (eg. Stannol, Kester)
  - **Avoid lead-free solder!**
- Plenty of flux
- Tweezers

Although not a step-by-step guide, I will note some caveats.

1. The kit comes with the STM32 chip placed in a fold of antistatic
material, taped to the PCB. Be warned, the chip will be loose when you
peel the tape!

2. The LED cathode terminal is marked by a green dot under the lens,
which should be oriented towards the STM32 chip.

3. The 10k resistor arrays are tight on their pads. Be careful
that they are correctly aligned.

4. XO1 should be soldered with hot air: The pads are too small for safe
hand soldering.

5. Pin 1 of the floppy connector is towards the USB end of the board. Do
not connect the wrong way round!

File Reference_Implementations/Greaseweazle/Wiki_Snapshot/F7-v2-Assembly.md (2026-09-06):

**NOTE: If you received a pre-assembled adapter then
you can skip straight to [Hardware Setup](Hardware-Setup).**

- [Parts List](#parts-list)
- [Assembly Guidance](#assembly-guidance)
- [Firmware Programming](Firmware-Programming)

## Parts List

You should obtain (or have received) the following parts, in addition
to the Greaseweazle PCB. Note that kits may include
an excess quantity of the "passives" (resistors, capacitors).

Board Reference | Footprint | Value/Type | Quantity
----------|------|-------|---------
C1        | 0805 | 4.7uF | 1
C2-C7,C10-C11,C13-C16 | 0603 | 100nF | 12
C8-C9,C12 | 0805 | 1uF   | 3
C17-C18   | 0603 | 27pF  | 2
C19-C20   | 0805 | 10uF  | 2
 | | | 
R1-R2     | 0603 | 470R  | 2
R3-R6     | 0603 | 1k    | 4
 | | | 
U1        | LQFP64 | STM32F730R8 | 1
U2        | SOT25 | AP2112K-3 | 1
 | | | 
ACT,PWR   | 0603 | LED | 2
DEBUG | 7x1 | Pin Header | 1
RESET, WRITE_INHIBIT | 2x1 | Pin Header | 2
FLOPPY POWER | 4x1 | TE 171826-4 | 1
FLOPPY DATA | 17x2 | Box Header | 1
USB       | USB-B | | 1
X1        | HC-49/US | 8MHz | 1

## Assembly Guidance

Please note that the small size and pitch of some components, particularly
U1, means that you will need some soldering proficiency, and
equipment such as the following:
- A workbench with decent lighting
- Moderate magnification (eg. a magnifying bench light)
- Good quality leaded (60/40) solder (eg. Stannol, Kester)
  - **Avoid lead-free solder!**
- Plenty of flux
- Tweezers

Although not a step-by-step guide, I will note some caveats.

1. The kit comes with the STM32 chip placed in a fold of antistatic
material, taped to the PCB. Be warned, the chip will be loose when you
peel the tape!

2. The kit-supplied LEDs are manufacturer codes HSMS-C190 and
HSMY-C190.  The cathode terminal is marked by a *tiny* dot, and should
be oriented towards the right-hand side of the PCB.
You can find the manufacturer datasheet
[here](https://docs.broadcom.com/docs/AV02-0551EN).

3. You may wish to remove pin 5 and/or pin 3 from the FLOPPY DATA header.
Some floppy-drive cables use one of these pins as an orientation key.

### STM32 Orientation

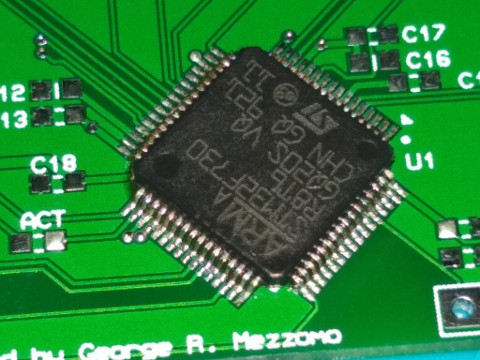
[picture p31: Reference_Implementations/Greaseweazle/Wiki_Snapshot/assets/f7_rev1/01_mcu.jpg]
STM32 orientation


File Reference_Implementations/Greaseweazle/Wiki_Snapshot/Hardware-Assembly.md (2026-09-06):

Model-specific assembly instructions.

- [**F1 "Blue Pill": Adapter Board**](Blue-Pill-Adapter)
- [**F7 Lightning Plus**](F7-Lightning-Plus-Assembly)

### Archive

These models are not available for self assembly, but build instructions
and design files are archived here.

- [**F7 v1**](F7-v1-Assembly)
- [**F7 v2**](F7-v2-Assembly)
- [**F7 Lightning**](F7-Lightning-Assembly)
- [**F7 Slim**](F7-Slim-Assembly)

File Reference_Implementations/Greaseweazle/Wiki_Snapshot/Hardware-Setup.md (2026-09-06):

This is the hardware setup page for F1 and F7 models of Greaseweazle. If you
have a **V4** device then please read the [dedicated setup page](V4-Setup).

You should
also read the [**Software Installation**](Software-Installation) page to set up
the control software on your host PC, and peruse the **Usage** pages listed in
the wiki sidebar.

## Greaseweazle Jumper Configuration

Some of the more complex Greaseweazle boards have jumpers which can
configure certain actions:

**WRITE INHIBIT:** Install this jumper to *enable* writes. You can
remove this jumper when preserving disks, to avoid any possibility
of accidental writes.

**PWR SELECT:** On the Lightning Plus a jumper is used to determine
whether the board and floppy-power connector are powered from USB or
from external 12V supply.

Please see the [F7 Plus wiki](https://github.com/aerobaticant/Greaseweazle-F7-Plus/wiki)
for instructions on configuring the F7 Plus.

## Floppy Drive

You can connect Greaseweazle to any floppy drive implementing a
Shugart interface: Old PC 3.5-inch and 5.25-inch drives are a good
choice, or an Amstrad 3-inch drive for Amstrad CPC and Spectrum +3
disks.  Note that, broadly speaking, the drive need not be the same
model as in the system to which the disks belong: a Shugart drive is a
Shugart drive, and it only really matters that it takes the correct
size physical media.

Please also note that GCR formats (as used by Apple II, Mac, and
Commodore 64) can be problematic with some floppy drives due
to the non-standard bitcell timings. Unfortunately finding a compatible
drive can be a matter of trial and error.

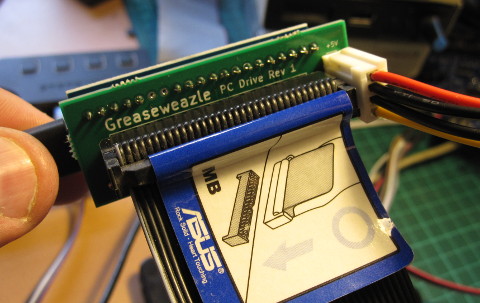
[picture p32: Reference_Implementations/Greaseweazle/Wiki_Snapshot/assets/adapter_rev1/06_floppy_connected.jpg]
Floppy Connection


### Power

3.5-inch drives typically require only 5v power and can *usually* be
supplied directly from the power header on the Greaseweazle
board. Older 5.25- and 3-inch drives typically are more power hungry
and require 12v power too: These you must connect to a separate power
source, or use a Greaseweazle Plus which accepts an external 12v
supply.

If you have problems accessing your drive via a Greaseweazle you believe
is correctly set up, it can be because the drive requires more power than
it can obtain via USB. In this case try connecting your drive to its own
power supply.

### Drive Terminations

The standard floppy bus is *open collector* with *termination*
(pull-up resistors) at the far receiving end.

The terminations on older 5.25- and 8-inch drives can be as strong as
150 ohms, requiring buffered outputs in the Greaseweazle to
successfully drive these signal lines low. These drives will thus only
work with [buffered models](Greaseweazle-Models) such as F7 Plus and
F7 Lightning Plus. It is also important that only *one* drive in a
bussed setup has 150-ohm terminations: Greaseweazle cannot drive into
multiple strong pull-ups in parallel.

The strong termination in older drives is usually *optional*
because only the last drive on a ribbon cable is expected
to terminate. The terminating resistors on intermediate drives are
traditionally either disabled by a jumper, or removed entirely.
This correctly terminates the signal lines and also prevents overloading
the drive controller's outputs with excessive pull-up current.
However, if termination is missing entirely then the
drive input signals will float (usually at around 2 volts) with unpredictable
results!

1. If using 3.5-inch and 3-inch drives, this is not a concern. Their
terminations are weaker and cannot be disabled.
2. If using a 5.25- or 8-inch drive on its own, make sure that the
termination resistors are present and enabled.
3. If using a 5.25- or 8-inch drive in a multi-drive setup, you probably
do not need the termination resistors.

Note that an unterminated setup will work with other flux boards such
as Kryoflux and Supercard Pro, which actively drive their outputs both
high and low. Greaseweazle by contrast has standard open-collector
outputs which rely on termination resistors to pull signals high.

## Host PC

Connect to your host PC (Linux, Mac, Windows, etc) using a normal USB cable.
Greaseweazle appears as a serial or modem device, depending on your OS.

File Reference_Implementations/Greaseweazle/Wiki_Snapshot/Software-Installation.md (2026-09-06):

Installation steps depend on your host OS:
- [Windows](#windows)
- [macOS](#macos)
- [Linux](#linux)

## Windows

Greaseweazle is packaged as a Windows executable, hence there are no
extra application components to download or install. Simply
[download](Download-Host-Tools) the Greaseweazle host software, unzip,
and run it in place from a CMD window.

Greaseweazle uses Microsoft's **usbser.sys** device driver. The steps
to install the driver depend on your Windows OS version.

**Windows 10 & 11:** The correct driver is automatically installed.

**Windows 8.1:** The driver must be manually installed as follows:
1. Download and install [**Zadig**][zadig]
2. Connect Greaseweazle via USB
3. Start Zadig
4. Select "*List all devices*" from the Options pull-down menu
5. Select "*Greaseweazle*" in the dropdown list
6. Select "*USB Serial (CDC)*" as the driver
7. Select "*Install driver*" or "*Replace driver*"

From now on Greaseweazle will automatically appear as a **COM** device
(typically **COM3**). To test correct connection to Greaseweazle hardware:
```
gw info
```

After installing the Greaseweazle command-line tools, you may be interested
in a Windows GUI wrapper. There are two available, maintained by third parties:
- [FluxMyFluffyFloppy][fmffgui] (Frank Bopple)
- [GreaseweazleGUI][ggui] (Don Mankin)

## macOS

Greaseweazle tools are installed as a Python 3 package from the command line.

To install Python 3 and Xcode tools:
```
xcode-select --install
brew install python
```

If available, the easiest way to install Greaseweazle is using pipx:
```
brew install pipx
pipx ensurepath
pipx install git+https://github.com/keirf/greaseweazle@latest
```

If pipx is unavailable, you can instead install into your system Python
environment:
```
python3 -m pip install git+https://github.com/keirf/greaseweazle@latest
```

When you connect Greaseweazle it will automatically appear as a
**/dev/cu.usbmodem** device.

To test correct connection to Greaseweazle hardware:
```
gw info
```

## Linux

Greaseweazle tools are installed as a Python 3 package from the command line.

To install Python 3 and C compiler on Ubuntu and other Debian-derived Linux:
```
sudo apt install gcc python3-pip python3-dev
```

If available, the easiest way to install Greaseweazle is using pipx:
```
sudo apt install pipx
pipx ensurepath
pipx install git+https://github.com/keirf/greaseweazle@latest
```

If pipx is unavailable, you can instead install into your system Python
environment:
```
python3 -m pip install git+https://github.com/keirf/greaseweazle@latest
```

To make the Greaseweazle device accessible as a normal user, and to
avoid conflicts with ModemManager under Ubuntu Linux, you need
to add some udev rules (included in the
[release download](Download-Host-Tools)) before connecting the Greaseweazle:
```
sudo cp scripts/49-greaseweazle.rules /etc/udev/rules.d/.
```

When you connect Greaseweazle it will automatically appear as a
**/dev/ttyACM** device (typically **/dev/ttyACM0**). To test correct
connection to Greaseweazle hardware:
```
gw info
```

If you install the Ubuntu udev rules, Greaseweazle should also appear
as **/dev/greaseweazle** (this is a symlink to the correct ttyACM device).

[fmffgui]: https://github.com/FrankieTheFluff/FluxMyFluffyFloppy
[ggui]: https://desertsagesolutions.com/greaseweazlegui
[bitarray]: https://www.lfd.uci.edu/~gohlke/pythonlibs/#bitarray
[zadig]: https://zadig.akeo.ie/

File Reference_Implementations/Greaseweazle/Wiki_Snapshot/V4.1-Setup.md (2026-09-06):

This page describes hardware setup of the **Greaseweazle V4.1**. You should
also read the [**Software Installation**](Software-Installation) page to set up
the control software on your host PC, and peruse the **Usage** pages listed in
the wiki sidebar.

To set up your V4.1 board you will need the following additional items:
- [Floppy drive](#floppy-drive)
- [Floppy data cable](#floppy-data-cable)
- [Floppy power](#floppy-power)
- [USB cable](#usb-cable)

See the following advanced notes on setup:
- [Jumper configuration](#jumper-configuration)
- [Drive terminations](#drive-terminations)
- [External LEDs](#external-leds)

## IMPORTANT NOTE

To avoid damage to your drive or Greaseweazle, please set up your
hardware in the following order:
1. Connect your drive to Greaseweazle before connecting to USB
or external power supply.
2. Connect Greaseweazle to USB power.
3. Switch on drive power, if drive is not powered via Greaseweazle.
4. Disconnection order is the opposite of connection order.

## Additional Items

### Floppy drive

You can connect your V4.1 to any floppy drive implementing a Shugart
interface: Old PC 3.5-inch and 5.25-inch drives are a good choice, or
an Amstrad 3-inch drive for Amstrad CPC and Spectrum +3 disks.  Note
that, broadly speaking, the drive need not be the exact same model as
in the system to which the disks belong: a PC 3.5-inch drive can read
and write Amiga and ST disks, for example.

An 8-inch drive can be connected via a suitable interface board such
as [FDADAP](http://www.dbit.com/fdadap.html).

Please also note that GCR formats (as used by Apple II, Mac, and
Commodore 64) can be problematic with some floppy drives due
to the non-standard bitcell timings. Unfortunately finding a compatible
drive can be a matter of trial and error.

### Floppy data cable

Your drive connects to Greaseweazle using a standard 34-pin ribbon
cable. Note that pin 1 is furthest from the Greaseweazle power connector,
and thus is "upside down" compared with the connector on most floppy
drives.

By default the V4.1 boards acts like an IBM-PC controller addressing
**Drive A**: This assumes a PC floppy drive and a ribbon cable with a
'twist' on pins 10-16.

A common alternative setup is a PC drive with straight ribbon cable.
In this case you must select drive **B** (`--drive=b`)

Another common setup is an Amiga, Atari ST, or other vintage drive
which responds to drive-select DS0 (pin 10). In this case you must use
a straight cable and select drive **0** (`--drive=0`).

For further info please
see the documentation for [Drive Select](Drive-Select).

### Floppy power

3.5-inch drives typically require only 5v power and can *usually* be
supplied directly from the power header on the Greaseweazle
board. Older 5.25- and 3-inch drives typically are more power hungry
and require 12v power too: These you must connect to a separate power
source.

If you have problems accessing your drive and you believe your Greaseweazle
is correctly set up, it can be because the drive requires more power than
it can obtain via USB. In this case try connecting your drive to its own
power supply.

For a suitable drive power supply for 3.5- and 5.25-inch drives, search for
*"Molex power supply"*. These usually feature 5V and 12V supply at 2A, and
a full-size Molex power connector; They connect directly to a
5.25" drive, or to a 3.5" drive via a Molex-to-floppy adapter cable.

When using an external power supply you have two options for powering the
Greaseweazle board:
1. **USB (Default):** Make sure to connect Greaseweazle
to its USB power source **before** powering your drive.
2. **External:** Connect external power source via Greaseweazle power
connector. Remove jumper **USB 5V ENABLE**. You may switch on external
power before or after connecting to USB.

### USB cable

V4.1 requires a USB-C data cable to connect to your host PC (Linux,
Mac, Windows, etc). Greaseweazle appears as a serial or modem device,
depending on your OS.

## Jumper configuration

Greaseweazle V4.1 has various jumpers through which a number of features
can be accessed:

* **WRITE-ENABLE**: Factory-jumpered to allow your
Greaseweazle to write to disk. Remove this jumper to physically
disable write support and provide an extra layer of safety when
preserving precious vintage media.

* **USB 5V ENABLE**: Factory-jumpered to power your Greaseweazle board
(and optionally your drive) via USB. Disconnect this jumper if you power
Greaseweazle and drive from a shared external power source.

* **Firmware Update Mode:** Your V4.1 will automatically enter firmware-update
mode when requested. However this mode can also be manually forced by placing
a jumper across the **TXO** and **RXI** pins.

## Drive terminations

The standard floppy bus is *open collector* with *termination*
(pull-up resistors) at the far receiving end.

The terminations on older 5.25- and 8-inch drives can be as strong as
150 ohms. It is also important that only *one* drive in a bussed setup
has 150-ohm terminations: Greaseweazle V4.1 cannot drive into multiple
strong pull-ups in parallel.

The strong termination in older drives is usually *optional*
because only the last drive on a ribbon cable is expected
to terminate. The terminating resistors on intermediate drives are
traditionally either disabled by a jumper, or removed entirely.
This correctly terminates the signal lines and also prevents overloading
the drive controller's outputs with excessive pull-up current.
However, if termination is missing entirely then the
drive input signals will float (usually at around 2 volts) with unpredictable
results!

1. If using 3.5-inch and 3-inch drives, this is not a concern. Their
terminations are weaker and cannot be disabled.
2. If using a 5.25- or 8-inch drive on its own, make sure that the
termination resistors are present and enabled.
3. If using a 5.25- or 8-inch drive in a multi-drive setup, you probably
do not need the termination resistors.

Note that an unterminated setup will work with other flux boards such
as Kryoflux and Supercard Pro, which actively drive their outputs both
high and low. Greaseweazle by contrast has standard open-collector
outputs which rely on termination resistors to pull signals high.

## External LEDs

If casing your V4.1, you may want to use external LEDs in place of the
on-board ones. This can be achieved by connecting LEDs across the supplied
**Act.** and **Power** LED headers. A series current-limiting resistor is
built into the +ve terminal of each header. If you wish to use a different
resistor value, instead connect the +ve lead of your LED to the 5V pin on
the 6x2 jumper block via your chosen resistor.

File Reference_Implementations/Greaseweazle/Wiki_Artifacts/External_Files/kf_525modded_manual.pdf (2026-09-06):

KRYOFLUX 5.25 MODIFIED FLOPPY DISK DRIVE FOR PRESERVATION AND FORENSICS

Drive modification engineered by Robert McIntyre and Christian Bartsch; manual by Christian Bartsch, Aki Sivula and John Ferrell. Photos by Aki Sivula and Tommi Lempinen.

Manual Revision 0.24 (2024-05-03)

www.kryoflux.com | forum.kryoflux.com

This drive has been carefully aligned and modified to be able to read side 1 even if this has been written with the disk flipped over in a single headed drive.

There are two versions of this modification/drive:

Version #1 (“Panasonic”) works by modifying the drive so that it can step into the negative domain and access a virtual track -8 on the upper head – which is the location of track 0 of a “flipped disk” written with a single headed drive. Note: During a dump you'll see a message that says "00.0 : Control Command Rejected by the Device" - When you see this, it has passed the track 0 sensor. Since the Teac and Newtronics do not bypass the track 0 sensor, neither are the prone to getting stuck in the negative domain, nor are they passing the track 00 sensor. This drive can be used like a standard drive with a standard controller as well.

Version #2 (“Teac”, “Newtronics”) works by re-aligning track 0 to -8, which means that it is permanently shifted, so data read off standard disks will need to be adjusted in software. The version #2 drive does therefore no longer work with a standard controller (as it is permanently track-shifted).

IMPORTANT

Version #1 must be the only device on the Shugart bus (=connected to KryoFlux) OR any other drive connected (only one modded drive per bus) must not have contact to pin 33 (usually ground, used here for TRK00 bypass). Also, regardless of what the manual might say, KryoFlux must be powered (=connected to USB) before the drive itself is powered. Otherwise track 00 might become “invisible” for the drive. In both scenarios the drive will bang its head against the mechanical barrier trying to find track 00.

Note: This drive is by definition to be used with the KryoFlux floppy disk controller only. Chances are that, depending on brand and model, the drive will work with other controllers. However, such operation cannot be guaranteed.

© 2009-2024 KryoFlux Products & Services Limited | 57 Warburton Road | Twickenham | TW2 6EW | United Kingdom | http://www.kryoflux.com

SETUP

This drive can be connected to the KryoFlux with the supplied (if bought with a KryoFlux) or a standard floppy disk data cable. Please note that the data connector on the PCB has a marking for data line #1 which must be aligned with the red (or otherwise coloured) stripe of the data cable. As outlined above, Version #1 must be the only drive on the bus or any other drive must not be connected to data line 33.

WARNING: Floppy disk drives tend to initialize themselves at startup, e.g. by doing a seek to tack 00, which will activate the track 00 sensor (“/TRK00”). Stopping a dump process while the drive is below track 0 (reading between -8 and -1) will leave the drive in an undefined position. The KryoFlux controller will, at the end of any dump process, re-position the drive to track 0. If the drive is left undefined, the next access (with a seek for track
00) will move the head further back (“outwards”) until it reaches a mechanical barrier. This will result in “banging”, a loud rattling sound, which might misalign or further damage the drive. If you hear such sound, remove power immediately. The drive can then carefully be repositioned by turning the motor spindle which moves the head. DO NOT PUSH the head carriage by hand!

Damage caused by scenarios outlined above is exempt from warranty.

CLEANING

Disks are old and most are very dirty. You may need to clean the heads on your drive from time to time to ensure you are producing accurate dumps.

Old media might be mouldy or the coating might come off the surface of the floppy disk platter. Regardless of these edge cases, even normal use will produce some dirt which, over time, will clog the heads. Even though heads are made of ceramic and are very sturdy, the construction they are being held by in place (usually sheet metal) allows for some wobble to enable the best contact to the magnetic platter. These small joints of metal are VERY FRAGILE. When cleaning the drive use only cotton swabs and 100% pure isopropyl alcohol (“IPA”). Do not use abrasive cleaners or solvents. Please also avoid cleaning disks. They only reach parts of the head which are in direct contact with the surface, but not the edges, where most of the clogging will occur. When cleaning, DO NOT PUSH. Excessive force will damage the device.

Cleaning of the drive head

Simply use cleaning floppy for the drive with IPA. For best results unscrew the drive's metal lid and gently clean the drive head (upper and lower heads with cotton swabs + IPA). Be careful when lifting the upper head up. When cleaning the heads excessive force may damage the heads or their alignment. It is possible to permanently damage the head carriage with a cotton swab.

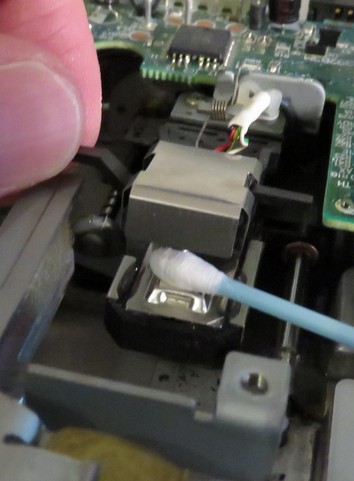
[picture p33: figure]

Fig. 1: Cleaning the lower head while carefully lifting the upper one

Typically a disk drive reads a disk without any distracting noise but by carefully listening as it spins you can hear the difference when the disk or the drive head requires cleaning. When the drive head starts to squeal, to drag or even scrape the diskette stop dumping immediately and clean the drive head and the disk.

Bear in mind that dirty drive head that contains pieces of iron oxide may damage a disk’s surface permanently by scratching it. Always after cleaning try dumping first the known good disk that loads without problems and disk surface is clean.

Cleaning the disk surface

A common problem with old disks is the iron oxide coating that can strip away as its binders become brittle. Mould or dirt can as well be the reason for the fault but often reading is still possible after careful cleaning.

Spin the disk manually 360 degrees and check both sides. Dip the cotton swab in IPA mixed with distilled water and clean the disk surface carefully to remove mould or dirt. Practice is best way to learn how to properly clean the disk surface. We recommend to practice with spare/scratch disks. If you want to be really careful, take a new disk, cut the sleeve (three sides available) and remove the platter. Then cut original disk open, clean the platter on a clean surface and eventually put the cleaned disk in the new disk sleeve and try to read the disk.

Disks cleaning with 100% IPA is possible but often IPA mixed with distilled water gives better results. 40% IPA is recommended. In some rare cases 100% IPA might damage the disk surface, so be careful with very fragile disks. Don’t practice on master disks! IPA availability depends on country, but often pharmacies or electronics stores are a good place to start. Anything non-pure should be avoided!

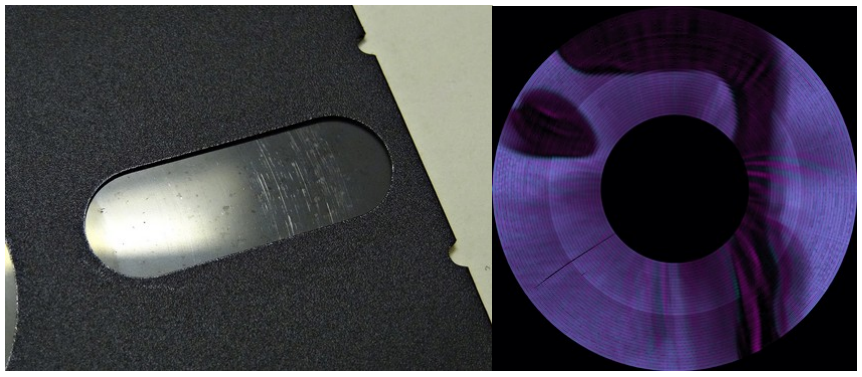
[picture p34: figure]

Fig. 2+3: Physically damaged disk surface (left) and partially degaussed disk (right; analogue illustration)

Left disk is an example of severe damage of the disk surface. Right disk was only partially readable since disk was very likely damaged by a magnet that was sweept over the disk.

USAGE

Please read the main manual, here are some command lines to get you started.

Note: All of these command line parameters can also be added to the GUI as presets.

Open a command prompt and navigate to where DTC resides. Now use the following commands depending on which flippy modded drive you have. These commands are to dump disks made for a C64 and will work on a computer where drive D: is the data directory.

Commodore 64 command examples:

Panasonic dual sided dump:
dtc –dd1 -p -b-8 -fD:\DiskName\DiskName_ -i0 -g2 –y –i6 –l8 –t10

Panasonic single sided dump:
dtc –dd1 -p -b-8 -fD:\DiskName\DiskName_ -i0 -g0 –i6 –l8 –t10

Newtronics and Teac dual sided dump:
dtc -p -a8 -fD:\DiskName\DiskName_ -i0 -g2 –y –i6 –l8 –t10

Newtronics and Teac single sided dump (g0 = side 0, g1 = side 1)
dtc -p -a8 -fD:\DiskName\DiskName_ -i0 -g0 –i6 –l8 –t10

Commodore 64 (side 0) and Atari 8-bit (side 1)
dtc –dd1 -p -b-8 -fD:\DiskName\DiskName_ -i0 -g0 –i6 -y -g1 -i3a –l8 –t10
- Convert streams to G64 files
dtc -p -m1 -fD:\DiskName\DiskName_ -i0 -fD:\DiskName.g64 -y -g2 -k2 -i22a -l8

Parameters explained:

-dd1 sets the drive density line to 1. It means double-density mode; but it actually depends on the model and jumper settings. This is a flip switch, hence correct operation might depend on opposite setting as well.

Finding the correct setting is easy with a Panasonic drive: dump an unformatted, degaussed disk with with dd0 and dd1 and compress dump data (e.g. ZIP or RAR). Whichever archive is smaller is the mode you are looking for. DD mode on the Panasonic enables longer flux transitions to pass without the AGC kicking in and adding a "random" flux transition. The result is smaller archives files (a lot less random data on unformatted tracks) and some disks using way too long flux transitions for modern drives are only readable this way. Some poorly readable track data is actually more readable in HD mode (as it really needs better amplification), so if DD fails it's worth a try. Some drives can also be jumpered to default to DD in that case this parameter is not necessary; in this case it must be set to switch to HD mode.

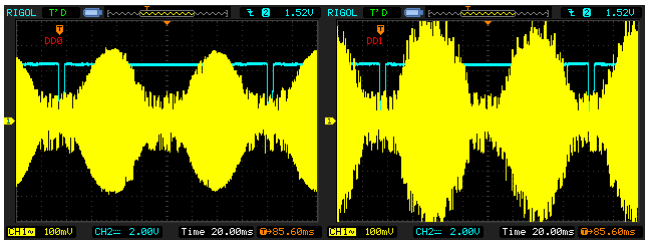
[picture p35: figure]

Fig. 4+5: Example of –dd0 (left) and –dd1 (right) on Newtronics; dd1 causes too high amplification.

-p Any file that contains a path after the –p parameter will have the directories created if necessary. Directories creation is recursive.

-b-8 / -a8 Physical track offset for the flippy modded drive you use. Panasonic uses -b-8 and Newtronics or Teac drives -a8 which stands for -a+8. Some disks are not duplicated properly, as the drive used for duplication couldn’t work at -8 (they did the exact same thing what we do to mod the drives, kindly confirmed by Trace Digital). When that happens *T warnings are displayed and the proper offset should be calculated from the expected track number vs the real track number found. Since the drives couldn’t detect track 0 anyway (at least the common earlier models) they could get away with this. But it’s a lot of hassle to rewrite the FreeForm script used to drive the Trace machine, so normally they used proper track offsets as long as it was possible. Be aware that if you stop dumping while the head is in the negative tracks (stopping DTC with CTRL-C) the head will usually get confused, and will only work as expected once you move it above track 0 with dumping or drive calibration command etc. You probably want to reset the board as well, just in case… alternatively, always wait until the head is above track 0.

-f Add the root filename that will be extended as necessary with track numbers and all folder will be created if they don’t exist (and you have the OS permissions to do so)

-i0 Stream file and preservation mode enabled. Zero is not mandatory so giving only -i defaults to 0.

-g2 Decode the disk format of both sides. Parameter –g0 decode the disk format for side 0 and –g1 for side 1.

-y Flip side of the disk is reversed. This stands for a double sided drive to read a single sided disk. This has nothing much to do with the physical track offset, it just tells that the rotation of the disk is reversed the way it is read. Setting the physical track offset is what activates the track bypass/allow moving below track 0 to negative tracks. –y is not needed when using –g0.

-i6 Standard CBM format (CBM DOS). All parameters from the beginning to the command line to the first image format parameter (any –i<number>) specify the local parameters for the format described, except for parameters that modify hardware or software behaviour itself, rather than something to do with a format. The parameters reset to defaults after each –I found.

-i3a Standard Atari 8-bit disk (FM XFD)

-m1 Set device mode to image file. In this case producing for G64.

-k2 Set track distance to 40 tracks. Default value is 1 and it stands for 80 tracks.

-i22a CBM GCR image with mastering info.

Multiple formats:

Since parameters are reseted after each -i specifying multiple formats is possible in this way even for the same track correctly decoding to different files (if specified).

For example in the command:
dtc –dd1 -p -b-8 -fD:\DiskName\DiskName_ -i0 -g2 –y –i6 –l8 –t10

–dd1 global (hardware change)

-p global (software change), but only active from after this (in our case active from the beginning of the command)

-b-8 global (hardware)

-fD:\DiskName\DiskName_ -i0 Format specific with the only parameter being the filename.

-g2 –y –i6 Double sided, reversed side 1, standard CBM format. Note, that adding a filename is possible with –f. In that case the fully decoded data for the CBM format would be saved as well to the file specified here as a sector dump which that can be used either directly (e.g. as .D64, .ADF, .ST, .IMG etc) in various emulators or indirectly for e.g. comparing the data content of the dumps; see if for example two Vorpal protected games are identical or not.

All the formats you can specify in DTC are fully decoded to sector images, although most of the more exotic formats are only really useful for content comparison and guiding the track dumping process itself (e.g. retry bad tracks).

Bad duplication:

A few disk are badly duplicated. For example Commodore 64 game 4x4 Off Road has a few track errors, which don’t affect the game, but fail the complete verification. This is not very common though and only affects a handful of releases. The format decoding is important to decide whether the read was actually good; without a format specified for a given track there would be no way to know if the data read was bad and no retry would occur. Sometimes it is actually desirable to image a disk without specifying a format (except for using stream files); when the disk is nearly falling apart, or completely unknown/unsupported format, so retries won't occur unnecessarily.

In those cases you could use something like this:
dtc –dd1 -p -b-8 -fD:\DiskName\DiskName_-i0

Since no format gets actually decoded, each track will only ever be read once. SPS refer to this as "blind dump" -it may or may not be good.

Protections

Certain disks require custom formats for dumping. Typical examples for Commodore 64 are Rapidlok or Vorpal protected disks. For instance Card Sharks uses Rapidlok and dumping with –i6 shows <unformatted>. In such case its best to change the –i6 in the command line to –i16. In case of Vorpal use –i18. This specifies the Vorpal custom format.

Pete Rittwage’s Commodore 64 preservation page database can often give guidance for possible protection http://c64preservation.com/database

However many games have different revisions and releases and they might contain completely different protections.

ABOUT FLIPPY DISKS

Important! We are using the correct term "cylinder" here, which means the physical location of data on the platter. The word "track" is very often used instead of "cylinder", but usually means the lower or the upper side of a cylinder. Cylinder 0 has two sides, 0 and 1. Speaking of tracks this would be track 0 and 1. Cylinder 1 has two sides, 0 and 1, with the tracks 2 and 3. Therefore a disk with 80 cylinders (0-79) would have a total of 160 tracks (0-159).

But back to the question. There isn't. At least not as long as a flippy disk is read in a floppy drive it was made for. Newer drives, which refers to all standard PC drives made after 1985, are dual headed. To avoid mechanical problems (too much pressure applied to the platter from two sides), there is an offset between these two heads. The relative distance is 8 cylinders. This distance is irrelevant when using such a drive with a disk written with or for such a drive. When accessing a cylinder, e.g. cylinder 10, side 0 for this cylinder will appear at head 0, side 1 for this cylinder will appear at head 1.

Now let's try this with a flippy disk. Let's try and read cylinder 10 again. Side 0 will read back correctly and will read data meant for cylinder 10. Side 1 will have a problem. The disk was written in a drive with one head only. Therefore track 10 is on the exact same position on both sides of the platter. Because of the offset (which is +8 for head 1 to be precise), head 1 will read data meant for track 18, not 10.

This problem could be taken care of in software. If you know the offset, data can be shifted to appear at the correct position. But let's try to read cylinder 0. Side 0 will read back correctly again, side 1 will return data meant for cylinder 8.

We would have to step back another 8 cylinders to access data for cylinder 0... but we can't! The drive will stop stepping when reaching cylinder 0.

There is a simple solution to this problem. Drives with one head only had their disks flipped to read or write the second side. Just flip the disk, and side 1 will appear at head 0 at the correct position.

BUT: You might notice the disk is not spinning. Chances are high it really does not. It might, but only if the disk has two index holes punched into the jacket. The reason is that modern drives use the index hole to detect drive speed and if the disk is spinning at all. Using a jacket with one index hole only will make this hole appear on the wrong side which the drive can not see.

To read a flippy disk with a modern drive, there are three major options:

1. Cut the jacket open and place the platter into a jacket that does have two index holes. You can punch in another hole into the original jacket as well. Now tell this a collector and make sure you can run fast enough...
2. Add a fake index to your floppy drive. Place a small magnet on the underside of the motor spindle and attach a small hall effect sensor (it will measure the magnet going by) to the drive's electronics. The drawback is that the index you generate is not connected with the original one. So while this does work, it's not usefull for preservation.
3. Modify a drive to make it step to -8.

SUPPORT

Sometimes its better to give disks for professionals instead of trying to dump them with own effort. If the disk is accidentally destroyed the disk the data is gone forever. If you are unsure how to handle fragile disks you can always contact Kryoflux support.

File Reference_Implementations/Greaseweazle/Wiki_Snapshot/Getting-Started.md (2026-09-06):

There exist several good guides to Greaseweazle and disk preservation
in general. Here are some articles by third-party authors to get you
started:
- Yann Serra: [Wiki article](Yann-Serra-Tutorial)
- Tech Tangents: [YouTube video][tt-yt] *"Archival Floppy Disk Preservation and Use"*
- Tech Tangents: [Wiki article][tt-wiki] *"Floppy Disk Imaging"*

[tt-yt]: https://www.youtube.com/watch?v=UxsRpMdmlGo
[tt-wiki]: https://wiki.techtangents.net/wiki/Floppy_Disk_Imaging

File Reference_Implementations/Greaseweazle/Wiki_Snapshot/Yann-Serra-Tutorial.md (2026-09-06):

**The following is a getting started guide contributed by Yann Serra**

Greaseweazle is a hardware and software solution that lets you archive
or regenerate old floppy disks. Reading them is useful for recovering
old data or forgotten programs that you can use in your favourite
emulators. And writing them is useful for collectors who need real boot,
game or application floppy disks to run authentic machines from the 70s,
80s and 90s.

To start, you obviously need a Greaseweazle board, since the gw software
provided here runs with it only. See [where to purchase a Greaseweazle
board](https://github.com/keirf/greaseweazle/wiki/Purchase-a-Greaseweazle).

Then, you need some floppy drives.

### Compatible with any standard floppy drive

The Greaseweazle board is compatible with any Shugart or IBM standard
floppy drive, that includes any 3.5 and 5.25-inch drive with a 34-pin
connector, or a 3-inch "Amstrad" drive with a 26-pin connector (actually
just a shorten 34-pin connector: same signals on same pins, just the
no-signal pins are missing), or a 8-inch drive with a 50-pin connector
(extended 34 pin connector with irrelevant signals). You need an extra
adaptor to connect 26-pin or 50-pin drives to the Greaseweazle’s 34-pin
connector.

Commodore (excluding Amiga) and Apple drives (including Macintosh),
which use a proprietary connection, are not supported. But you can
read/write Commodore 8-bit and Apple II/Mac floppy disks with most
regular 34 pin drives.

**Important Note:** GCR formats (as used by Apple II, Mac, and
Commodore 64) can be problematic with some floppy drives due
to the non-standard bitcell timings. Unfortunately finding a compatible
drive can be a matter of trial and error.

### Two IBM drives, or four Shugart drives supported on the same cable

The Greaseweazle solution supports two IBM drives or three Shugart
drives on the same cable.

If the drives are of "IBM" standard (any drive coming from a
MS-Dos/Windows machine), then you use a ribbon cable with a twist: the
drive on the edge will be drive A, and the drive in the middle connector
will be drive B.

If your drives are Shugart standard from any computer before mid-90's
(Amiga, Atari, Acorn…), then you use a flat ribbon cable, and tells
which drive is unit \# 0, 1, 2 or 3 by moving their configuration jumpers
accordingly (located near their rear, where it’s written
“DS0/DS1/DS2/DS3”).

See [here](https://github.com/keirf/greaseweazle/wiki/Drive-Select) for
a more in-depth explanation of how to connect them.

### Three levels of access for reading or writing any floppy disk

Depending on the disk image you wish to create (from a floppy disk) or
restore (to a floppy disk), the Greaseweazle solution can access three
levels of information on a floppy disk: the user content in the sectors,
the formatted tracks, or the flux of polarised information on the
surface.

**Sectors:** a floppy disk is made up of tracks, themselves subdivided
into sectors, which contain the data directly accessible to users. It is
this data that makes up the content of disk images in block mode (.img,
.st, .dsk, .adf...).

**Formatted tracks:** for each floppy disk format, the tracks contain a
particular number of sectors, of a particular size, with a particular
identification in some headers, and gaps of a certain size between all
these elements. In some case, there are also intentional identification
errors as a form of copy-protection. All these details are stored in
'meta' images (.edsk, .imd...) that can tell which floppy disk format
they contain. It matters, for instance, in case of Amstrad or CP/M
computers that use several formatting variants.

**Flux:** Information is encoded in the form of magnetic pulses on the
surface of floppy disks. Disk images such as .scp or .hfe store these
pulses regardless of the encoding used, thereby preserving an exact copy
of an original floppy disk, even with its intentional encoding errors
that constituted the most advanced copy protections.

### How to use it, level \#1: the simplest/new-comer way

After [having
downloaded](https://github.com/keirf/greaseweazle/wiki/Download-Host-Tools)
and
[installed](https://github.com/keirf/greaseweazle/wiki/Software-Installation)
the gw command line (it's just Python3 code, so it works on every modern
system, including Raspberry Pis), you backup a physical disk to an image
file with :

```
gw read --format=<profile.of.your.floppy.disk> <name_of_your_image.suffix> --drive=<ID>
```

For example:

```
gw read --format=amiga.amigados MyAmigaDisk.adf --drive=A
```
…will backup the physical Amiga disk you inserted into the drive, that
is located at the end of your twisted cable, to a file named
“MyAmigaDisk.adf”, in the current directory.

In some circumstances, you can omit the --format and the --drive
options. For instances, the drive A being the default choice, and .adf
disk images being most often a backup of an Amiga 880KB disk format, you
can type here:  

```
gw read MyAmigaDisk.adf
```

To generate some content to a physical disk from a disk image, you just
replace the “read” argument with “write”, like this:

```
gw write --format=amiga.amigados MyAmigaDisk.adf --drive=A
```

In the above commands, what you tell after the “--format=” option is
just the name of a predefined profile matching one of the many software
formats that computer brands defined for their disks systems. Thanks to
this profile, the gw command can check the content is read or written
without error.

You should also take care about the suffix you put as the extension of
your image name (“.adf”, for instance), as it defines the preferred disk
image format for the floppy disk you are working with.

Here are some tables that would help you to find which predefined
profile you should use for the floppy disk format you want to backup to
disk image or to recreate from a disk image. And also, the preferred
suffix your disk image should have according to the profile.

| **3.5-inch disks**  | **profile** | **sides** | **cyls** | **RPM** | **kbit/s** | **sct/trk** | **byt/sct** | **encoding** | **size (KB)** | **suffix** |
|---|---|---|---|---|---|---|---|---|---|---|
| Acorn BBC | acorn.adfs.320 | 1 | 80 | 300 | 250 | 16 | 256 | MFM | 320 | .adm |
|   | acorn.adfs.640 | 2 | 80 | 300 | 250 | 16 | 256 | MFM | 640 | .adl |
| Archimedes | acorn.adfs.800 | 2 | 80 | 300 | 250 | 5 | 1024 | MFM | 800 | .adf |
| RiscPC | acorn.adfs.1600 | 2 | 80 | 300 | 500 | 10 | 1024 | MFM-HD | 1600 | .adf |
| Amiga | amiga.amigados | 2 | 80 | 300 | 250 | 11 | 512 | AMFM | 880 | .adf |
|   | amiga.amigados\_hd | 2 | 80 | 300 | 500 | 22 | 512 | AMFM-HD | 1760 | .adf |
| Atari ST | atarist.360 | 1 | 80 | 300 | 250 | 9 | 512 | MFM | 360 | .st, .msa |
|   | atarist.400 | 1 | 80 | 300 | 250 | 10 | 512 | MFM | 400 | .st, .msa |
|   | atarist.440 | 1 | 80 | 300 | 261 | 11 | 512 | MFM | 440 | .st, .msa |
|   | atarist.720 | 2 | 80 | 300 | 250 | 9 | 512 | MFM | 720 | .st, .msa |
|   | atarist.800 | 2 | 80 | 300 | 250 | 10 | 512 | MFM | 800 | .st, .msa |
|   | atarist.880 | 2 | 80 | 300 | 261 | 11 | 512 | MFM | 880 | .st, .msa |
| C64/C128 | commodore.1581 | 2 | 80 | 300 | 250 | 10 | 512 | MFM | 800 | .d81 |
| IBM PC | ibm.720 | 2 | 80 | 300 | 250 | 9 | 512 | MFM | 720 | ..img |
| (Sam Coupé) | ibm.800 | 2 | 80 | 300 | 250 | 10 | 512 | MFM | 800 | .img, (.mgt) |
| (Macintosh HD) | ibm.1440 | 2 | 80 | 300 | 500 | 18 | 512 | MFM-HD | 1440 | .img, (.dsk) |
|   | ibm.1680 | 2 | 80 | 300 | 500 | 21 | 512 | MFM-HD | 1680 | .img |
|   | ibm.dmf | 2 | 80 | 300 | 500 | 21 | 512 | MFM-HD | 1680 | .img |
|   | ibm.2880 | 2 | 80 | 300 | 1000 | 36 | 512 | MFM-ED | 2880 | .img |
| Macintosh 68K | mac.400 | 1 | 80 | VAR | 375 | 12-8 | 512 | GCR | 400 | .dsk |
|   | mac.800 | 2 | 80 | VAR | 375 | 12-8 | 512 | GCR | 800 | .dsk |
| MSX | msx.1dd | 1 | 80 | 300 | 250 | 9 | 512 | MFM | 360 | .dsk |
|   | msx.2dd | 2 | 80 | 300 | 250 | 9 | 512 | MFM | 720 | .dsk |
| Nec PC98 | pc98.2hs | 2 | 81 | 300 | 500 | 9 | 1024 | MFM-HD | 1458 | .hdm, .xdf |
| Piano | akai.800 | 2 | 80 | 300 | 250 | 5 | 1024 | MFM | 800 | .img |
|   | akai.1600 | 2 | 80 | 300 | 500 | 10 | 1024 | MFM-HD | 1600 | .img |
|   | ensoniq.mirage | 1 | 80 | 300 | 250 | 5+1 | 1K+512 | MFM | 440 | .img |
|   | ensoniq.800 | 2 | 80 | 300 | 250 | 10 | 512 | MFM | 800 | .img |
|   | ensoniq.1600 | 2 | 80 | 300 | 500 | 20 | 512 | MFM-HD | 1600 | .img |
|   | gem.1600 | 2 | 80 | 300 | 500 | 20 | 512 | MFM-HD | 1600 | .img |
|   | sci.prophet | 2 | 80 | 300 | 250 | 5 | 1024 | MFM | 800 | .img |
| ZX Spectrum | zx.trdos.640 | 2 | 80 | 300 | 250 | 16 | 256 | MFM | 640 | .mgt, .dsk |
|   | zx.quorum.800 | 2 | 80 | 300 | 250 | 5 | 1024 | MFM | 800 | .mgt, .dsk |
| MicroWare OS-9 | mm1.os9.80ds.hd32spt | 2 | 80 | 300 | 500 | 32 | 256 | MFM-HD | 1280 | .img |
|   | mm1.os9.80ds.hd36spt | 2 | 80 | 300 | 500 | 36 | 256 | MFM-HD | 1440 | .img |
| | | | | | | | | | | |
| **5.25-inch disks** | **profile** | **sides** | **cyls** | **RPM** | **kbit/s** | **sct/trk** | **byt/sct** | **encoding** | **size (KB)** | **suffix** |
| Acorn Atom | acorn.dfs.ss | 1 | 40 | 300 | 125 | 10 | 256 | FM | 100 | .ssd |
|   | acorn.dfs.ds | 2 | 40 | 300 | 125 | 10 | 256 | FM | 200 | .dsd |
| BBC | acorn.adfs.160 | 1 | 40 | 300 | 250 | 16 | 256 | MFM | 160 | .ads |
|   | acorn.adfs.320 | 1 | 80 | 300 | 250 | 16 | 256 | MFM | 320 | .adm |
|   | acorn.adfs.640 | 2 | 80 | 300 | 250 | 16 | 256 | MFM | 640 | .adl |
| Atari 800 | atari.90 | 1 | 40 | 288 | 125 | 18 | 128 | FM | 90 | .img |
| Vic20/C64 | commodore.1541 | 1 | 35 | 300 | VAR | 21-17 | 256 | GCR | 170 | .d64 |
| /C128 | commodore.1571 | 2 | 35 | 300 | VAR | 21-17 | 256 | GCR | 340 | .d71 |
| Dragon 32/64 | dragon.40ss | 1 | 40 | 300 | 250 | 18 | 256 | MFM | 180 | .img |
|   | dragon.40ds | 2 | 40 | 300 | 250 | 18 | 256 | MFM | 360 | .img |
|   | dragon.80ss | 1 | 80 | 300 | 250 | 18 | 256 | MFM | 360 | .img |
|   | dragon.80ds | 2 | 80 | 300 | 250 | 18 | 256 | MFM | 720 | .img |
| IBM PC | ibm.160 | 1 | 40 | 300 | 250 | 8 | 512 | MFM | 160 | .img, .ima |
|   | ibm.180 | 1 | 40 | 300 | 250 | 9 | 512 | MFM | 180 | .img, .ima |
|   | ibm.320 | 2 | 40 | 300 | 250 | 8 | 512 | MFM | 320 | .img, .ima |
|   | ibm.360 | 2 | 40 | 300 | 250 | 9 | 512 | MFM | 360 | .img, .ima |
|   | ibm.1200 | 2 | 80 | 360 | 500 | 15 | 512 | MFM-HD | 1200 | .img |
| Luxor ABC | luxor.80 | 1 | 40 | 300 | 250 | 8 | 256 | FM | 80 | .img |
| | luxor.160 | 1 | 40 | 300 | 250 | 16 | 256 | MFM | 160 | .img |
| | luxor.320 | 2 | 40 | 300 | 250 | 16 | 256 | MFM | 320 | .img |
| | luxor.640 | 2 | 80 | 300 | 250 | 16 | 256 | MFM | 640 | .img |
| MSX | msx.1d | 1 | 40 | 300 | 250 | 9 | 512 | MFM | 180 | .dsk |
|   | msx.2d | 2 | 40 | 300 | 250 | 9 | 512 | MFM | 360 | .dsk |
| Nec PC88/PC98 | pc98.2d | 2 | 40 | 300 | 250 | 8 | 512 | MFM | 320 | .hdm, .xdf |
|   | pc98.2dd | 2 | 77 | 360 | 250 | 8 | 512 | MFM | 616 | .hdm, .xdf |
|   | pc98.n88basic.hd | 2 | 77 | 360 | 500 | 26 | 256 | MFM-HD | 998 | .hdm, .xdf |
|   | pc98.2hd | 2 | 77 | 360 | 500 | 8 | 1024 | MFM-HD | 1232 | .hdm, .xd |
| CP/M - Osborne 1 | occ1.sd | 1 | 40 | 300 | 125 | 10 | 256 | FM | 100 | .img |
|   | occ1.dd | 1 | 40 | 300 | 250 | 5 | 1024 | MFM | 200 | .img |
| Olivetti M20 | olivetti.m20 | 2 | 35 | 300 | 250 | 16 | 256 | MFM | 278 | .img |
| Tandy CoCo | coco.decb | 1 | 35 | 300 | 250 | 18 | 256 | MFM | 157.5 | .img |
|   | coco.decb.40t | 1 | 40 | 300 | 250 | 18 | 256 | MFM | 180 | .img |
|   | coco.os9.40ss | 1 | 40 | 300 | 250 | 18 | 256 | MFM | 180 | .img |
|   | coco.os9.40ds | 2 | 40 | 300 | 250 | 18 | 256 | MFM | 360 | .img |
|   | coco.os9.80ss | 1 | 80 | 300 | 250 | 18 | 256 | MFM | 360 | .img |
|   | coco.os9.80ds | 2 | 80 | 300 | 250 | 18 | 256 | MFM | 720 | .img |
| TSC Flex | tsc.flex.ssdd | 1 | 80 | 300 | 250 | 18 | 256 | MFM | 358 | .img |
|   | tsc.flex.dsdd | 2 | 80 | 300 | 250 | 18 | 256 | MFM | 715 | .img |
| | | | | | | | | | | |
| **8-inch disks** | **profile** | **sides** | **cyls** | **RPM** | **kbit/s** | **sct/trk** | **byt/sct** | **encoding** | **size (KB)** | **suffix** |
| DEC RX | dec.rx01 | 1 | 77 | 360 | 250 | 26 | 128 | FM | 250.25 | .img |
| (PDP-11/VAX) | dec.rx02 | 1 | 77 | 360 | 250 | 26 | 256 | M2FM | 500,5 | .img |
| Luxor ABC | luxor.1000.data | 2 | 77 | 360 | 500 | 26 | 256 | MFM | 1000 | .img |
| | luxor.1000.program | 2 | 77 | 360 | 500/250 | 26 | 256/128 | MFM/FM | 1000 | .img |
| | luxor.1000.abcnet | 1 | 77 | 360 | 500/250 | 26 | 256/128 | MFM/FM | 1000 | .img |
| | | | | | | | | | | |
| **3-inch disks** | **profile** | **sides** | **cyls** | **RPM** | **kbit/s** | **sct/trk** | **byt/sct** | **encoding** | **size (KB)** | **suffix** |
| Sega SC-3000 | sega.sf7000 | 1 | 40 | 300 | 250 | 16 | 256 | MFM | 160 | .sf7 |

The gw command does an honest job at supporting dozens of disk formats
and image formats, but it doesn’t directly support all of them yet. This
list keeps evolving. To know all the possible disk format profiles and
disk image suffixes supported by your latest version of the gw command,
just type:  

```
gw read --help
```

Don't despair if you don’t see the profile of your floppy disk in the
list. Predefined profiles are just shortcuts for working with specific
formats. Right now, Greaseweazle offers other ways of saving and
recreating all your floppy disks.

### Level \#2: Troubleshooting common errors

Here are the few common errors many beginners encounter and how you can
resolve them:

**<span class="underline">Error “No Index”:</span>**

**Symptom:** The gw command has asked the drive to start its motor, but
the drive never confirms that the floppy disk is actually spinning.

**Probable cause:** you have not specified the correct drive unit in the
command line.

**Solution:** add "--drive=" to the command line and specify the correct
ID. This could be:

--drive=a when you are using the PC drive at the end of the cable, on a
cable with a twist.

--drive=b: when you are using the PC drive in the middle of the cable,
on a cable with a twist.

--drive=0, or 1, or 2: on a flat cable (without any twist), when you are
using the drive whose plastic jumpers (on the rear) configure the DS0,
DS1 or DS2 unit respectively.

Special case: when you connect a PC drive (without plastic jumpers) to a
flat cable, it always has unit DS1 (--drive=1).

**Other possible causes:** there is no power supply for the drive, you
plug the ribbon cable upside-down, you forgot to insert a floppy disk
into the drive.

**<span class="underline">Error “Track 0 not found”:</span>**

**Symptom:** the drive has been selected, but something is missing to
tell that it has managed to position its head on track 0.

**Probable cause:** the drive doesn't have enough power to operate
normally.

**Solution:** the power source needs to be changed. Either:

\- if the drive is powered by the Greaseweazle board, plug the
Greaseweazle board into another USB port.

\- if the drive is powered by an external power source (power supply,
self-powered USB hub, etc.), unplug the other devices connected to this
power source.

\- If the error persists, supply your drive with a more efficient power
source.

**Other possible causes:** When several drives are attached on the
ribbon cable, this error can also be caused by a wrong drive selection.
Check the solution given for the “No Index” error in this case.

**<span class="underline">Errors “Flux Overflow” or “Flux
Underflow”</span>**

**Symptom:** The data from the Greaseweazle board is not arriving at the
right speed.

**Probable cause:** there is interference in the USB connection.

**Solution:** plug the Greaseweazle card into another USB port on your
computer. If no USB port solves the problem, change your USB cable.

**<span class="underline">Errors: “Verify Failure”, “Failed to verify
Track”</span>**

**Symptom:** When writing, something is preventing a certain area on the
surface of your diskette from storing information correctly.

**Probable cause:** there is mould on the surface of your floppy disk.

**Solution:** gently clean the surface of your floppy disk with a
microfibre cloth soaked in 70% Isopropyl alcohol. Unfortunately, the
result is not guaranteed. If the errors keep recurring on other
diskettes, clean the heads of your drive too.

For more troubleshooting, see [this
page](https://github.com/keirf/greaseweazle/wiki/Troubleshooting-FAQ).

### Level \#3: more disk formats with meta-profiles and meta-disk images

The gw command also provides 'metaprofiles' which, without necessarily
referring to a particular type of formatting, capture all the sectors
present on a floppy disk, whatever their number, size, numbering scheme
or formatting bytes used. These metaprofiles are called:

**- ibm.scan**: all FM or MFM encoded floppy disks,

**- raw.125**: all single-density floppy disks,

**- raw.250**: all double-density floppy disks,

**- raw.500**: all high-density floppy disks.

They are accompanied by 'meta-images' which store not only the contents
of the sectors, but also their number, size, etc. These 'meta-images'
are:

**- .edsk**: this is the disk image format favoured by British Z80
machine emulators (Sinclair, Amstrad, Sam Coupé and all MGT floppy disk
systems).

**- .imd**: a format invented in the MS-DOS era to allow a PC to save
any type of floppy disk readable by its floppy disk controller as an
image.

To use these meta-profiles and meta-images, you must manually specify
the geometry of the floppy disk using the "**--tracks=**" option,
followed by various arguments:

**- c=**: the range of cylinders to be read. This means the tracks
accessible by the drive head, the first being numbered "0" and the last
being the 39th or 79th depending on the 40 or 80 track formats. For
example: "c=0-79".

**- h=**: the drive heads to be used, to indicate whether only one side
is to be accessed ("h=0"), both sides of the diskette ("h=0-1"), or only
the second side of the diskette ("h=1").

See [here](https://github.com/keirf/greaseweazle/wiki/Specifying-Tracks)
for a more in-depth explanation of how to use the --tracks option.

For example, to backup a 180 KB Amstrad CPC floppy disk, which has a
single side with 40 tracks, to a "MyCPCdisk.edsk" image, using a drive
with ID "0" (Amstrad floppy disks are 3-inch, 3-inch drives being of the
Shugart type, they necessarily have ID "0", "1" or "2"), you would do :

```
gw read --format=ibm.scan MyCPCdisk.edsk --drive=0 --tracks=c=0-39:h=0
```

Writing a floppy disk from a meta-image is much simpler. All the
geometry of the floppy disk being already indicated in the meta-image,
you indicate neither the profile nor the quantity of tracks in the
command line:

```
gw write MyCPCdisk.edsk --drive=0
```

Note that emulators that use .edsk images prefer the ".dsk" suffix. When
reading a floppy disk with the gw command, you should always use the
".edsk" suffix to avoid confusion with plain ".dsk" images. But remember
to rename your ".edsk" images to ".dsk" before using them with an
emulator.

However, you can use such an image with the suffix ".dsk" to write a
floppy disk; the command will detect its type automatically when reading
it.

### Level \#4: manage 5.25-inch 48-TPI disks with your 5.25-inch 96-TPI drive

With 5.25-inch disks, there are two sizes for the floppy drive’s head:
48 TPI and 96 TPI.

When they are written by a 48 TPI floppy drive, floppy disks contain
around 40 'thick' tracks (from 35 to 42, depending on the format).

When they are written by a 96 TPI floppy drive, they contain around 80
'thin' tracks (sometimes up to 82).

<!---
<img src="media/image1.jpg" style="width:5.54444in;height:3.03212in" alt="Une image contenant capture d’écran, jaune, Graphique, texte Description générée automatiquement" />
--->

The good news is that you can absolutely read a 48 TPI floppy disk from
a 96 TPI floppy drive when you ask your drive to read one track every
two tracks. You tell this in the command line with the "**--tracks=**"
option and its "**step=2**" argument applied to the interval of tracks
you want to read.

For instance, let’s say you want to read a 2-side, 40-track Dragon 32/64
floppy disk, using a 5.25-inch Teac FD-55GFR floppy drive, which is a
96-TPI drive. You would do:

```
gw read --format= dragon.40ds MyDragonDisk.img --tracks=c=0-39:step=2
```

Side note: a 48 TPI floppy disk is in all cases also a “double density”
disk (DD), while a 96 TPI drive is most often also a “high density”
floppy drive (HD). This has nothing to do with track thickness, but is
related to the amount of current the floppy drive head uses to
read/write a floppy disk made of iron oxide (double density) or cobalt
(high density). To force an HD floppy drive to adapt to a DD floppy
disk, it may be useful to add the **--dd L** option to the command line.

Writing a 48 TPI floppy disk with a 96 TPI floppy drive is a bit more
complicated than just replace “read” by “write”. This floppy drive
writes tracks that are twice too thin compared to real 48 TPI tracks. If
your floppy disk has been previously written with a 48 TPI floppy drive,
then half of the old “thick” tracks will remain in between the new
"thin" tracks you are writing. At the end, the 48 TPI drive in your old
computer will read at the same time your newly written thin track + half
of an old thick track. It will fail.

<!---
<img src="media/image2.jpg" style="width:5.73333in;height:3.73264in" alt="Une image contenant texte, capture d’écran, jaune, arc-en-ciel Description générée automatiquement" />
--->

A solution - not guaranteed! - would be to completely erase your floppy
disk before writing on it, by passing a magnet over its entire surface.
This will leave no trace of the old thick tracks between the new thin
tracks.

But the most reliable solution is to only write 48 floppy disks with 48
TPI floppy drives.

### Level \#5: work at the magnetic flux level to read/write any disk (even copy-protected)

In the examples above, the gw command automates a complex process of
backing up the useful contents of an uncopy-protected floppy disk to a
disk image compatible with your emulator. Or it does the opposite: it
automates the writing of a physical floppy disk from a disk image that
contains the data useful to an emulator. But that's not necessarily what
you want to do.

The Greaseweazle solution also allows you to archive the complete
magnetic flux on the surface of your floppy disk. This is useful when
you want to keep an archive of an original floppy disk, possibly
copy-protected, so that you can recreate a strictly identical copy
later. It is also useful for capturing a floppy disk whose formatting is
not directly supported by the gw command.

It works like a photocopy of the surface of your disk. It works with any
disk format, you don't even need to tell which format your disk is, just
put the right suffix at the end of your archive name. The supported
archive formats are:

-   **.scp :** A long detailed digitized flux in very high definition,
    better for archiving purposes of special disk formats. But expect
    dozens of MegaBytes for the size of the archive of a simple double
    density disk. This archive format was invented for the older
    archiving solution SuperCard Pro.

-   **.ctr :** The same as above. This archive format was invented for
    the older archiving solution Kryoflux.

-   **.raw :** The same as above, but with one separate file per track.
    This archive format was invented for the older archiving solution
    Kryoflux.

-   **.hfe :** a digitized flux at the exact resolution of the bitcells,
    the smallest bits of useful data on a floppy disk. Expect around
    twice the size of your original disk for the archive (2 MB for the
    archive of an Amiga disk, for instance). This archive format was
    invented for the HxC floppy drive emulator.

However, when you work at the flux level, you need to **manually tell**
gw the speed of the recording it is supposed to read. The speed of the
recording is the rotation speed in RPM for .scp, .ctr and .raw archives,
or a bitrate in kbit/s for .hfe archives. And, as before, you must also
tell the number of tracks to read.

**RPM (for .scp, .ctr and .raw archives):** the Rotations Per Minute
your disk was initially recorded with. Most of the drives spin at 300
RPM, except:  
- the latest 5.25-inch and all the 8-inch drives, who spin at 360 RPM.

\- the Atari 810 and 1050 drives, who spin at 288 RPM.

So, here's the scenario you might encounter: you want to archive an
Acorn BBC floppy disk that was written on a 300 RPM drive with your last
generation 5.25-inch 1200 KB drive, which runs at 360 RPM. The data will
be read too quickly. Specifying the original RPM number, with the option
“--adjust-speed”, will correct this problem.

Here are some examples:  
  
- To archive an Atari 800XL 5.25-inch disk, that has one side formatted
and 40 “thick” tracks (48 TPI), originally written at 288 RPM, into a
“MyAtari800Disk.scp” file, using a 5.25-inch Teac FD-55GFR drive, that
is a 96 TPI drive spinning at 360 RPM, you will do:

```
gw read MyAtari800Disk.scp --tracks="c=0-39:h=0:step=2" --adjust-speed=288rpm
```

\- To archive an IBM PC-XT “360 KB” 5.25-inch disk, that has two sides
and 40 “thick” tracks (48 TPI) originally written at 300 RPM, into a
“MyIBMdisk.scp” file, using the same 96 TPI/360 RPM drive, you will do:

```
gw read MyIBMdisk.scp --tracks="c=0-39:step=2" --adjust-speed=300rpm
```

\- To archive a MSX 3.5-inch disk, that has one side formatted, into a
“MyMSXdisk.scp” file, using any 3.5-inch drive, disk and drive being
both in 80 tracks and 300 RPM:

```
gw read MyMSXdisk.scp --tracks="c=0-79:h=0”
```

\- To archive any Amiga disk, being double density (880 KB) or high
density (1760 KB), being copy-protected or not, into a “MyAmigaDisk.scp”
file, using any 3.5-inch drive:

```
gw read MyAmigaDisk.scp
```

Side note: When you do not specify a format, the gw command does not
check that the flux it is reading is error-free. This is desirable for
capturing protections that are based on malformed data. But there is a
risk that you will also capture random errors. To avoid this pitfall, it
is possible to combine format checking with saving the content in flux
mode, using the --format and --raw options together, as follows:

```
gw read --format=amiga.amigados MyAmigaDisk.scp --raw
```

**Bitrate** **(for .hfe archives only):** for disks encoded in FM/MFM,
there are four possible bitrates, depending on the 'density' of your
floppy disk:

\- 125 kbit/s for 'single density' floppy disks (aka SD: early
computers)

\- 250 kbit/s for 'double density' floppy disks (aka DD: most computers
created during the 80’s)

\- 500 kbit/s for "high density" floppy disks (aka HD: IBM PC-AT and
every other computer launched after it)

\- 1000 kbit/s for "Extra high density" floppy disks (aka ED, mainly
latest IBM PS/2 and NeXT’s computers)  
You specify this by adding “::bitrate=” right after the suffix of your
.hfe archive name.

Here are some examples:

To archive an Atari ST 3.5-inch disk, that has two sides formatted at
double density, into a “MyAtariSTdisk.hfe” file suitable for a HxC drive
emulator, using any 3.5-inch drive:

```  
gw read MyAtariSTdisk.hfe::bitrate=250
```

To archive an Amstrad CPC 3-inch disk, that has only one side formatted
at double density and 40 tracks, into a “MyAmstradCPCdisk.hfe” suitable
for a HxC drive emulator, using an original Amstrad 3-inch floppy drive
that has unit ID 0 and that also reads/writes 40 ‘thick’ tracks:  

```
gw read MyAmstradCPCdisk.hfe::bitrate=250 --tracks="c=0-39:h=0” --drive=0
```

The good news is all the speed and tracks information is stored into
these archives. So, you don’t have to tell it again when you write the
.scp or .hfe file back to the disk. For instance:  

```
gw write MyAmstradCPCdisk.hfe
gw write MyMSXdisk.scp
```

### Level \#6: Working with 8-inch floppy drives and the TG-43 option

When working with 8-inch floppy drives, you may encounter issues with writing and reading disks reliably, especially on tracks 43 and higher. This is where the `--gen-tg43` option becomes essential.

#### Understanding TG-43 (Track Greater than 43)

The TG-43 signal is a control signal that tells the floppy drive to reduce the write current when accessing tracks 43 and above on 8-inch floppy disks. This is necessary because:

1. **Higher linear velocity**: As you move toward the outer tracks of a spinning disk, the linear velocity increases even though the rotational speed remains constant.

2. **Read amplifier saturation**: The faster-moving magnetic medium on outer tracks produces stronger read signals that can saturate the read amplifier circuitry, leading to data corruption and read/write errors.

3. **Write current reduction**: The TG-43 signal reduces the write head's output current for tracks ≥43, preventing read amplifier saturation and ensuring reliable data storage.

#### Using the --gen-tg43 option

When writing to 8-inch floppy disks use the `--gen-tg43` option:

```
gw write --gen-tg43 --format=dec.rx02 MyDisk.img
```

This enables pin 2 (TG-43) on the floppy drive interface, which signals the drive to reduce write current for tracks 43 and above.

#### Drive compatibility and filtering

Some drives have additional filtering capabilities:

- **Track 60+ filtering**: Some 8-inch drives include hardware filters that help reduce read errors on tracks 60 and above caused by overly strong magnetic signals.

- **Controller differences**: Not all floppy disk controllers implement TG-43 properly:
  - Many PC floppy controllers don't support TG-43 for 8-inch drives
  - DEC RX02 controllers may not implement TG-43 correctly
  - In these cases you need to enable --gen-tg43 to help the read circuitry handle disks that were written with excessive current (without TG-43), as the stronger magnetic patterns can saturate the read amplifier 

The TG-43 feature is essential for reliable 8-inch floppy disk operations and is one of the key differences between 8-inch and smaller floppy disk technologies.

### Level \#7: yes, you can read any disk, except (probably) "flippy" 5.25-inch disks

In most cases, Commodore, Apple and Atari 800 5.25-inch floppy disks
that were recorded on both sides, by physically flipping the disk, will
not be supported.

The problem is not in the Greaseweazle solution, but in the 5.25-inch
floppy drive you use, that is physically incompatible with “flippy
disks”. It relies on the “index hole” to evaluate the speed of the disk
before any read/write operation. But when you flip a disk upside down,
the index hole is no more in front of the optical probe.

That said, it has been reported that some rare 5.25-inch drives support
reading floppy disks without using index hole, thanks to a special
configuration of their plastic jumpers. On the Panasonic JU-475-4, for
instance, you achieve this mode of operation by removing the jumper from
the GX position and move it on the EX position.

If your drive has this kind of feature, then you must manually tell the
gw command what is the rotation speed (in RPM) of your drive with the
option “--fake-index”. For instance, if you want to read the flipped
side of a C64 floppy disk with a JU-475-4, which is a 96 TPI and 360 RPM
drive, you would insert it upside down into your drive and type:

```
gw read --format=commodore.1541 MyC64sideB.d64 --tracks=”c=0-35:h=0:step=2” --fake-index=360rpm
```

Note that --fake-index is related here to the rotation speed of the
drive you are using. It is not the rotation speed used by the original
computer to write the floppy disk you are reading. For instance, let’s
take one complex example: you want to dump the flipped side of a
35-track Apple II floppy disk, written in 300 RPM and 48 TPI, into a
“MyApple2SideB.scp” archive, using a 96 TPI and 360 RPM drive. You would
insert the disk upside down into your drive and type:

```
gw read MyApple2SideB.scp --tracks=”c=0-35:h=0:step=2” --adjust-speed=300rpm --fake-index=360rpm
```

For more information about flippy disks, see [this
page](https://github.com/keirf/greaseweazle/wiki/Flippy-Disks).

### Level \#8: Restore floppy disks from even more image disks

Beyond .edsk, .imd, .scp, .ctr, .raw and .hfe, other self-descriptive
disk images exist. The gw command cannot create them for some reason
(legal, lack of documentation, time missing…), but it can read them to
write their content back to a physical floppy disk. The supported
formats are:  
  
**.a2r :** archive of flux, dedicated to Apple II floppy disks,

**.d88, .dcp, .dim, .fdi** : meta-image dedicated to Japanese Nec
88xx/98xx and X68000 floppy disks,

**.tdo** : similar to .imd.

**.ipf** : similar to .hfe + metadata. Please note that support of .ipf
disk images is optional. To install its library on your system, read
[this page](https://github.com/keirf/greaseweazle/wiki/IPF-Images).

Then, to generate an Amiga physical floppy disk from a MyAmigaGame.ipf
file, for instance, you would do:

```
gw write MyAmigaGame.ipf
```

### Level \#9: complete your Greaseweazle experience with other tools

You still can’t find in the gw command the support for the disk images
of your choice? Then use .scp, .hfe; .edsk or .imd images with
Greaseweazle and install third-party tools that will make the bridge between
theses disk images and other ones. Here are some extra tools, compatible
with Windows, macOS and Linux, that you could use to expand your
Greaseweazle experience:

**[Disk Utilities](https://github.com/keirf/disk-utilities):** helpful
to convert a .scp or an old .dfi flux archive of a protected floppy disk
into an .ipf image easier to write with a Greaseweazle or to use with an
emulator.

[**HxC Floppy
Emulator**](https://github.com/jfdelnero/HxCFloppyEmulator/releases/tag/HxCFloppyEmulator_V2_15_1_2):
to convert many exotic disk images (Apple II .po or .do, Atari ST .stx;
Atari 800 .atr, NorthStar .nsi, Dragon 32/64 .vdk, Thomson MO/TO .fd,
TRS-80 .jv3 or .jv1, and a dozen of audio keyboard proprietary images,
among others) to .hfe or .scp archives writable with the gw command.

It can also convert .scp or .hfe archives created with gw command to
.po, .do, .stx, .nsi, .vdk, .fd, or .jv3 images usable with emulators.

This software exists in command line and GUI versions. The GUI version
also offers a graphic disk analyser to visually detect errors on flux
archives created with Greaseweazle.

**[SamDisk](https://simonowen.com/samdisk/):** to convert even more
exotic disk images (Amstrad .dsc and .cfi, C64 CMD FD-2000/4000 .d2m or
.d4m, HP LIF .lif, Jupiter Ace Sam Coupé .sad or .sbt, Sega System 24
.s24, TRS-80 .dmk, ZX Spectrum .mbd, .opd,.scl or .udi, among others) to
.edsk meta-images writable with the gw command.

It can also help to convert .edsk images created with the gw command to
.d2m, .d4m, .lif, .sad, .mbd, and .opd images compatible with some
emulators.

**a8rawconv ([FTP
link](http://ftp.pigwa.net/stuff/emulators_and_utils/8-bit/a8rawconv/))**:
to convert .scp archives of Atari 800 disks created by the gw command to
.atr, .atx, or .xfd images compatibles with emulators. Or the opposite:
to convert .atr, .atx and .xfd images into a .scp archive writable to
floppy disk with the gw command.

[Fluxengine](https://github.com/davidgiven/fluxengine/releases): This is
an alternative command to gw, which supports other floppy disk formats,
like Apple II AppleDos or ProDos, Victor 9000, among others.

### Level \#10: create your own profile to support a specific disk format

All the profiles used with the --format option are described in the
[diskdefs.cfg](https://github.com/keirf/greaseweazle/blob/master/src/greaseweazle/data/diskdefs.cfg)
configuration file that is installed with the gw command. If you feel
that you are familiar with the characteristics of a certain floppy disk
formatting which is not directly supported by any profile of the gw
command, you can write its specifications as a new profile into a
configuration file following the pattern in diskdefs.cfg.

Then, to read a floppy disk with a custom profile that you named, for
instance, my.disk.format and that you saved in a configuration file
named, for instance, MyFormats.cfg, you would type:  

```
gw read --diskdefs=MyFormats.cfg --format=my.disk.format MyDisk.img
```

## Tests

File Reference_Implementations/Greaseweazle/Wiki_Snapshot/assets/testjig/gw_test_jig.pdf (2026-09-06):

# Greaseweazle Test Jig v2

Introduction
The Tester will test the following Greaseweazle boards, aka the Device Under Test (DUT): V4, V4.1, F7 v3, F7 Lightning Plus. The following aspects of the DUT are automatically tested:
- USB connector
- Floppy connector, including load test of all outputs
- Header pins RXI, TXO
- Flash protection (must be disabled)

Tester Setup
1. Connect a straight 34-way ribbon to the Tester's boxed connector
2. Connect a USB-C charger cable to the USB-C port POWER IN
3. Connect to the USB-C port TO DUT depending on DUT model:
a. V4.1: Connect a USB-C to USB-C cable.
b. All other: Connect a USB-C male to USB-A female adapter. Connect a USB-A to USB-B cable to the adapter.
4. When power is applied to POWER IN via the charger cable, you should see USB displayed and a double beep (if your Tester has a speaker).

Connecting the DUT
1. Connect the straight 34-way ribbon to the DUT
2. Connect to the Tester port TO DUT via the USB cable
3. Test starts automatically after connecting via USB, and takes about one second

Successful Test
- DUT: Green LED flashes rapidly; Red LED is constantly lit
- Tester: 7-segment display shows dash-dash-dash
- Tester: Emits two high-pitch beeps

Test Failure
The Tester emits two low-pitch tones, while one of the following error codes flash on the 7-segment display:
- Enn: An error in USB communications (nn is a numeric code)
- Unlikely to see this!
- Pnn: An error at pin nn of the DUT 34-pin floppy header
- Bad soldering? Unconnected or solder short?
- OSC: Pin 22 does not oscillate properly
- Bad LS07 driver on DUT?
- OPT: Option bytes error
- Ensure DUT Flash is not be read/write protected
- HDR: Error at the RXI/TXO pins of the GW 7x2 pin header
- Bad soldering? Solder short?
The purely-numeric code which alternates with the above is for internal use only, and should be ignored.

Following 7-segment display messages are not usually errors
- USB: Waiting for USB device connection to GW board
- Expected while no USB cable connection to DUT
- If cable is connected, this is an error (test fail)
- ---: Test has successfully passed!

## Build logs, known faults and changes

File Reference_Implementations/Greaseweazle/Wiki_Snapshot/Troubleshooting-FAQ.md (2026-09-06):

- **Greaseweazle is not detected by my host PC**
  - Test your USB cable with another device. Charging-only micro USB
  cables which
  omit the data wires are very common and will
  not work to connect Greaseweazle (or any other device) to your PC.
  - If the activity LED blinks a repeated pattern, see the
    next question in the FAQ.
  - **F1 only:** Check the resistance between Blue Pill pins **A12**
  and **3.3**. If this is not 1.5k ohms then you should remove Blue
  Pill surface-mounted resistor R10 and manually connect a 1.5k
  resistor between **A12** and **A0**.
  - **F1 only:** Be aware of [STM32 fake chips](STM32-Fakes) which do
      not work properly.
  - **Linux only:** Have you previously installed Kryoflux software? Then
      please [read this](https://github.com/keirf/greaseweazle/discussions/312).

- **Greaseweazle blinks the activity LED and is not detected via USB**
  - Greaseweazle performs a power-on self test and blinks a diagnostic
  code on failure:
    - **1 blink:** Board version straps are unstable.
      Check for bad soldering around those pins (PC13-15).
    - **2 blinks:** Board version straps not recognised. Check you're
      loading the latest firmware.
    - **3 blinks:** Oscillator failed to start up. Check the external
      oscillator.
    - **4 blinks:** Unrecognised or incorrect microcontroller chip.

- **Commands fail with 'Track 0 not found' or 'No Index'**
  - The default drive is **A**, which assumes
  a PC drive (drive-select DS1, pin 12) and a ribbon cable with
  a twist across pins 10-16.
  - A common alternative setup is a PC drive with straight ribbon cable.
  In this case you must select drive **B** (`--drive=b`)
  - Another common setup is an Amiga, Atari ST, or other vintage drive
  which responds to drive-select DS0 (pin 10). In this case you must use
  a straight cable and select drive **0** (`--drive=0`).
  - For further info please
  see the documentation for [Drive Select](Drive-Select).

- **Commands still fail with 'Track 0 not found'**
  - Confirm that your ribbon cable is the correct way round.
    - Look for pin 1 on the Greaseweazle and for pin 1 on the drive.

- **Commands still fail with 'No Index'**
  - Check your drive connections again.
  - Check that you have a disk inserted in your drive.
  - Check whether your drive requires 12-volt power.
    - If so you will need an external power supply to spin the motor.

- **Writes fail with 'Failed to verify Track 0.0'**
  - Check that your disk media is good.
  - Can you read disks okay with your setup? If not, write verification
    cannot possibly succeed.
  - Check the write-enable jumper on your Greaserweazle board.

- **Commands fail with 'ImportError: urllib3 v2.0 only supports OpenSSL 1.1.1+, [...]'**
  - Downgrade Python's urllib3 to v1.x. For example: `python3 -m pip install "urllib3<2"`

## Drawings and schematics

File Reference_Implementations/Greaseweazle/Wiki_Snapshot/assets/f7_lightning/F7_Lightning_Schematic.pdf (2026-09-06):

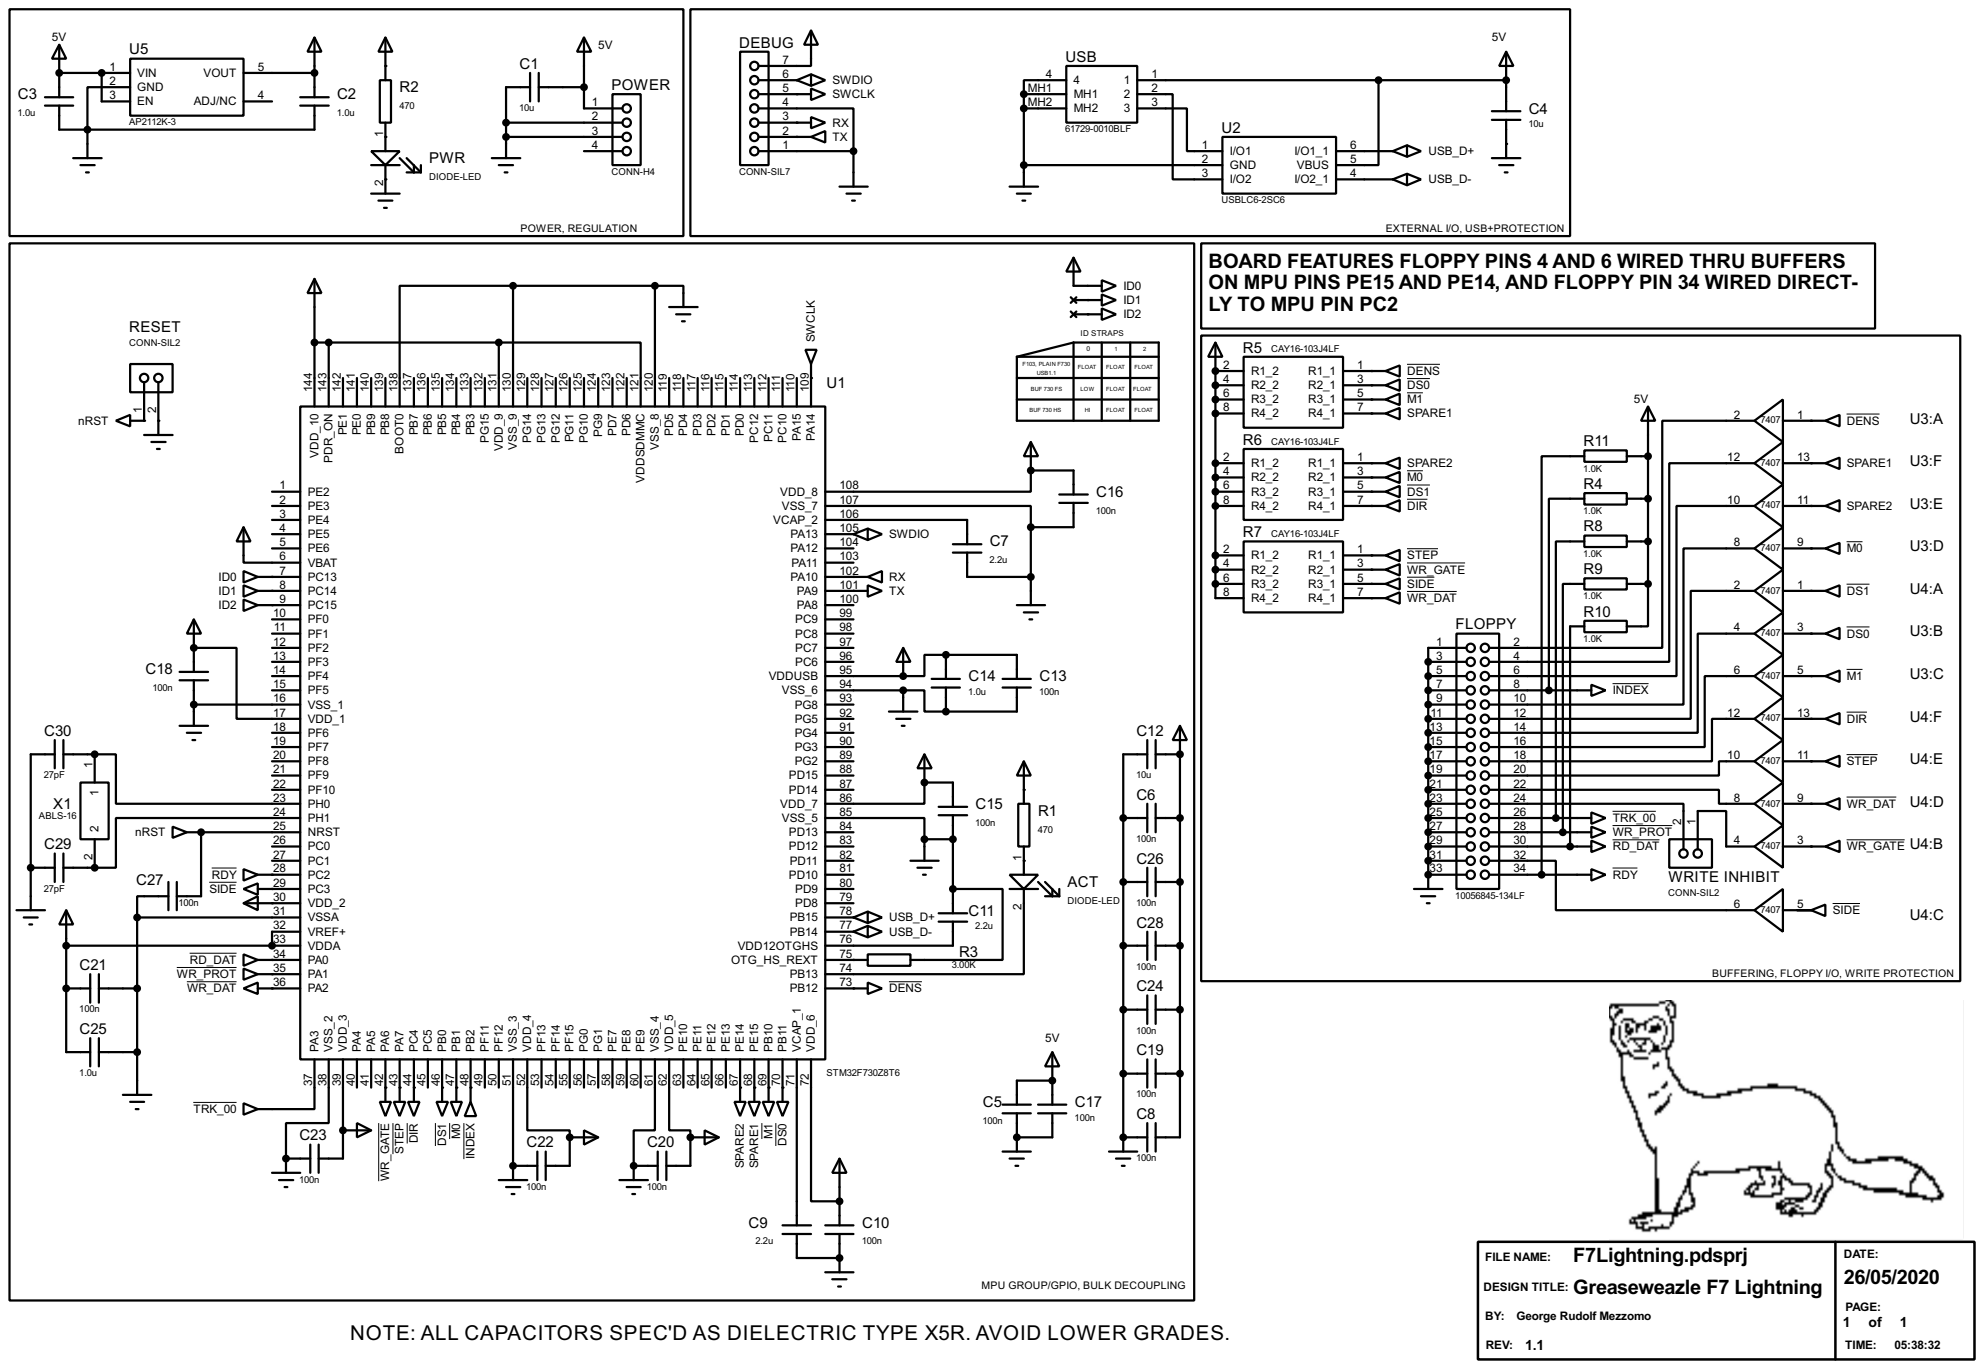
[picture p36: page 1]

BOARD FEATURES FLOPPY PINS 4 AND 6 WIRED THRU BUFFERS
ON MPU PINS PE15 AND PE14, AND FLOPPY PIN 34 WIRED DIRECT- LY TO MPU PIN PC2

FLOAT 0 | 1 | 2 F103, PLAIN F730

BUF 730 FS | LOW | FLOAT | FLOAT

BUFFERING, FLOPPY I/O, WRITE PROTECTION

FILE NAME:
DESIGN TITLE: Greaseweazle F7 Lightning

MPU GROUP/GPIO, BULK DECOUPLING

NOTE: ALL CAPACITORS SPEC'D AS DIELECTRIC TYPE X5R. AVOID LOWER GRADES.

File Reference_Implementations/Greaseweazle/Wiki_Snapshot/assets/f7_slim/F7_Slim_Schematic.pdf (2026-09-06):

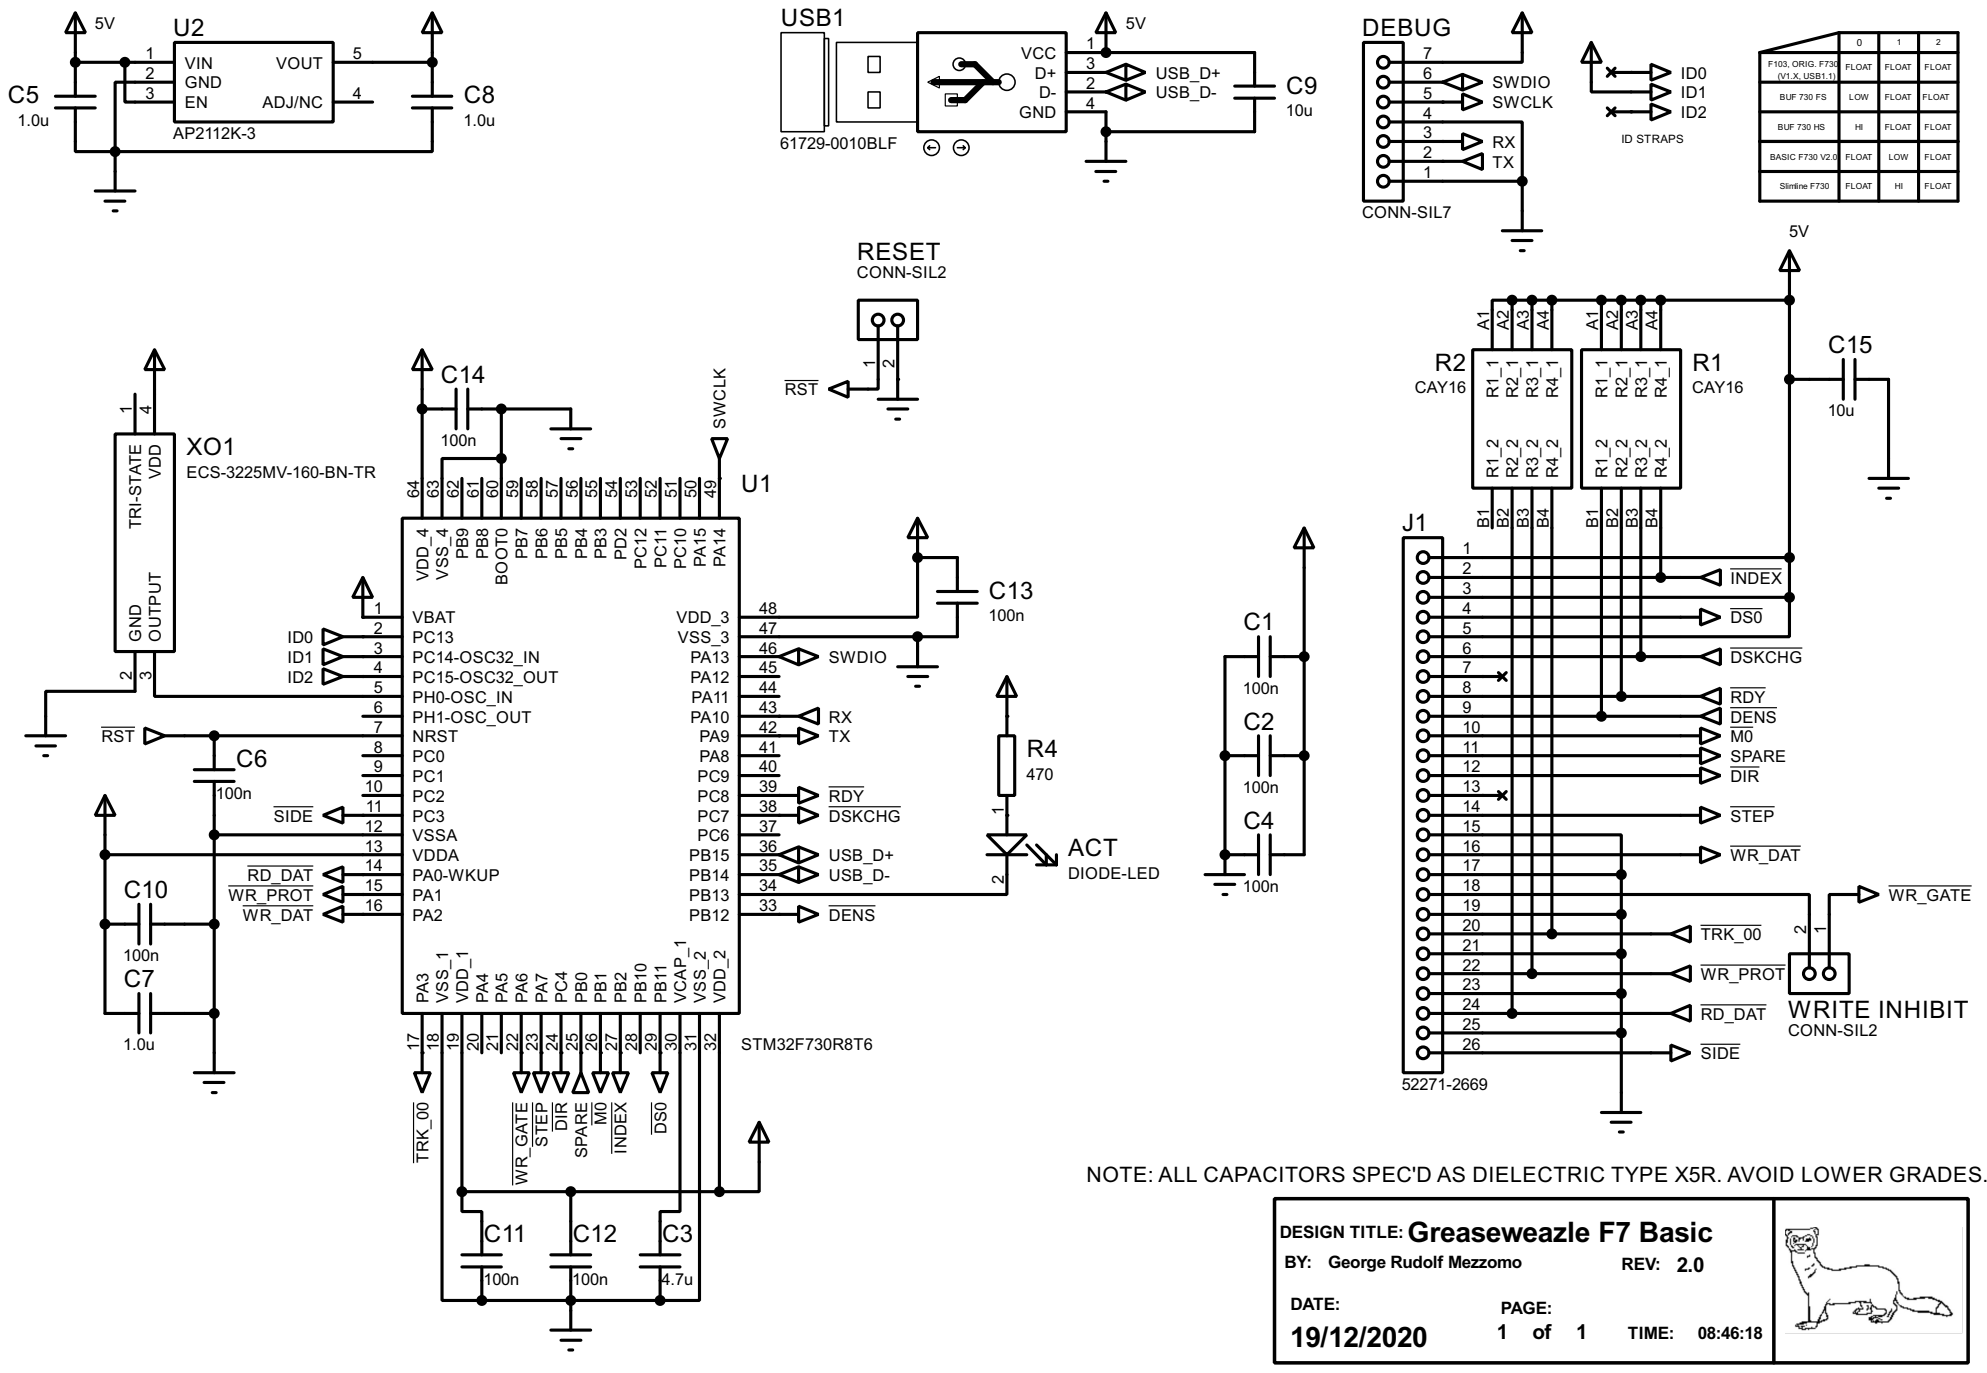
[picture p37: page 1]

(V1.X, USB1.1) | | FLOAT | FLOAT

BUF 730 FS | LOW | FLOAT | FLOAT

BUF 730 HS | HI | FLOAT | FLOAT

NOTE: ALL CAPACITORS SPEC'D AS DIELECTRIC TYPE X5R. AVOID LOWER GRADES.

DESIGN TITLE:Greaseweazle F7 Basic

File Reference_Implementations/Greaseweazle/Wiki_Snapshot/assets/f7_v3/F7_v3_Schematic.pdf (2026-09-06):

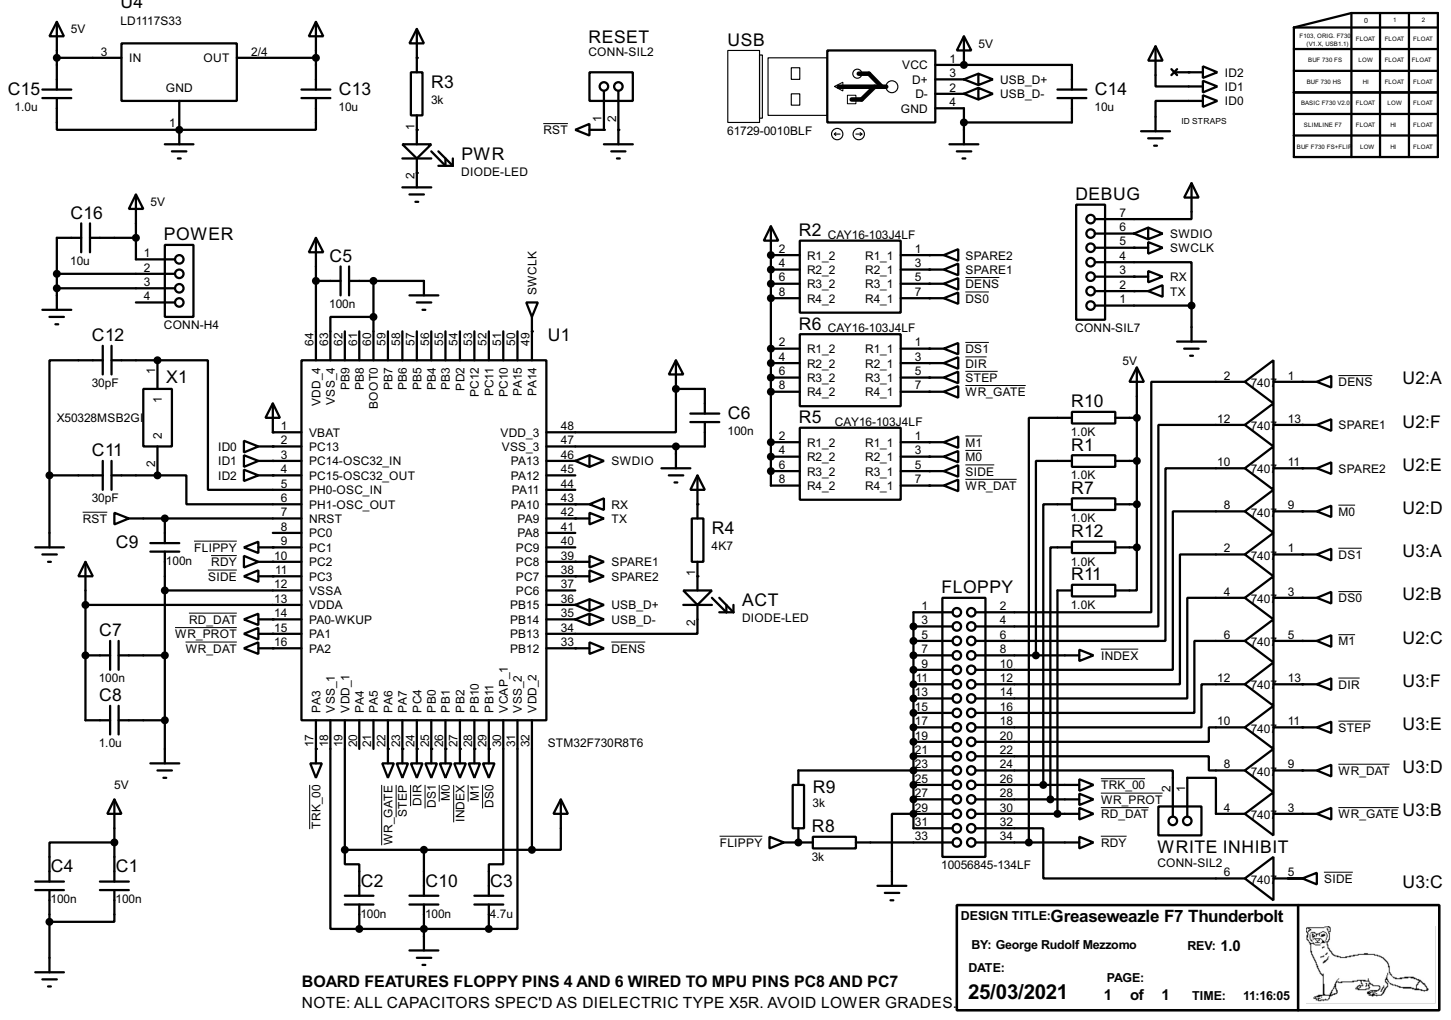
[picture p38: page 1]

FLOAT 0 | 1 | 2 F103, ORIG. F730

(V1.X, USB1.1) | FLOAT | FLOAT

SLIMLINE F7 | FLOAT | HI | FLOAT

BUF F730 FS+FLIP | LOW | HI | FLOAT

SIDE RD_DAT WR_PROT | 37 PB15

DESIGN TITLE:Greaseweazle F7 Thunderbolt

NOTE: ALL CAPACITORS SPEC'D AS DIELECTRIC TYPE X5R. AVOID LOWER GRADES. BOARD FEATURES FLOPPY PINS 4 AND 6 WIRED TO MPU PINS PC8 AND PC7

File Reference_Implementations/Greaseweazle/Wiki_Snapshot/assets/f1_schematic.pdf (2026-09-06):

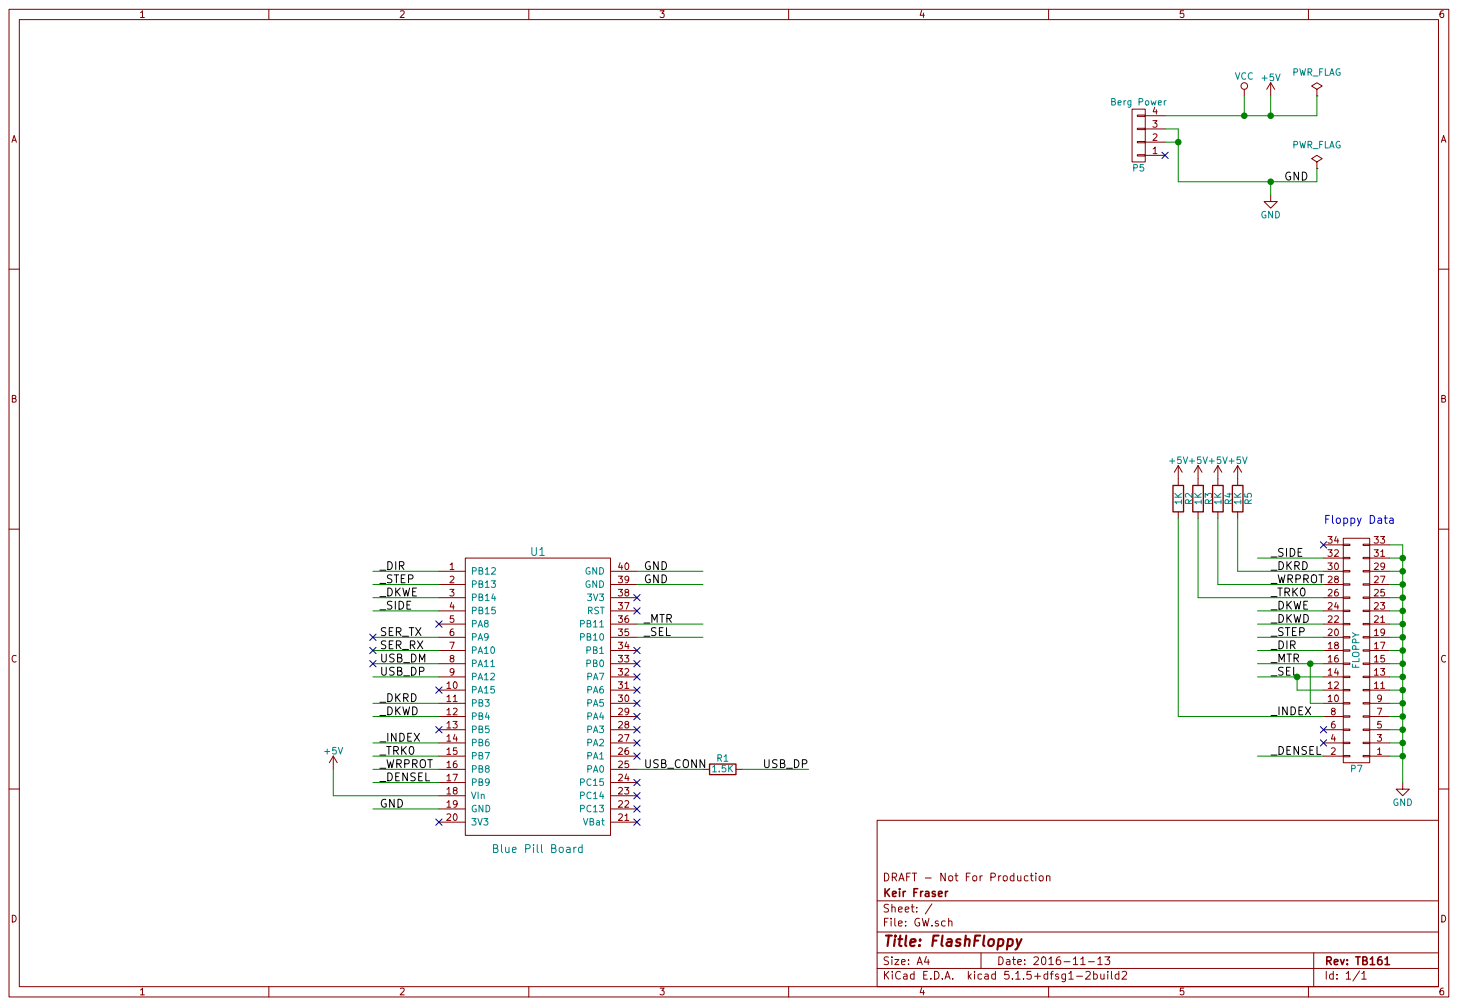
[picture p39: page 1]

File: GW.sch Sheet: / Keir Fraser DRAFT - Not For Production

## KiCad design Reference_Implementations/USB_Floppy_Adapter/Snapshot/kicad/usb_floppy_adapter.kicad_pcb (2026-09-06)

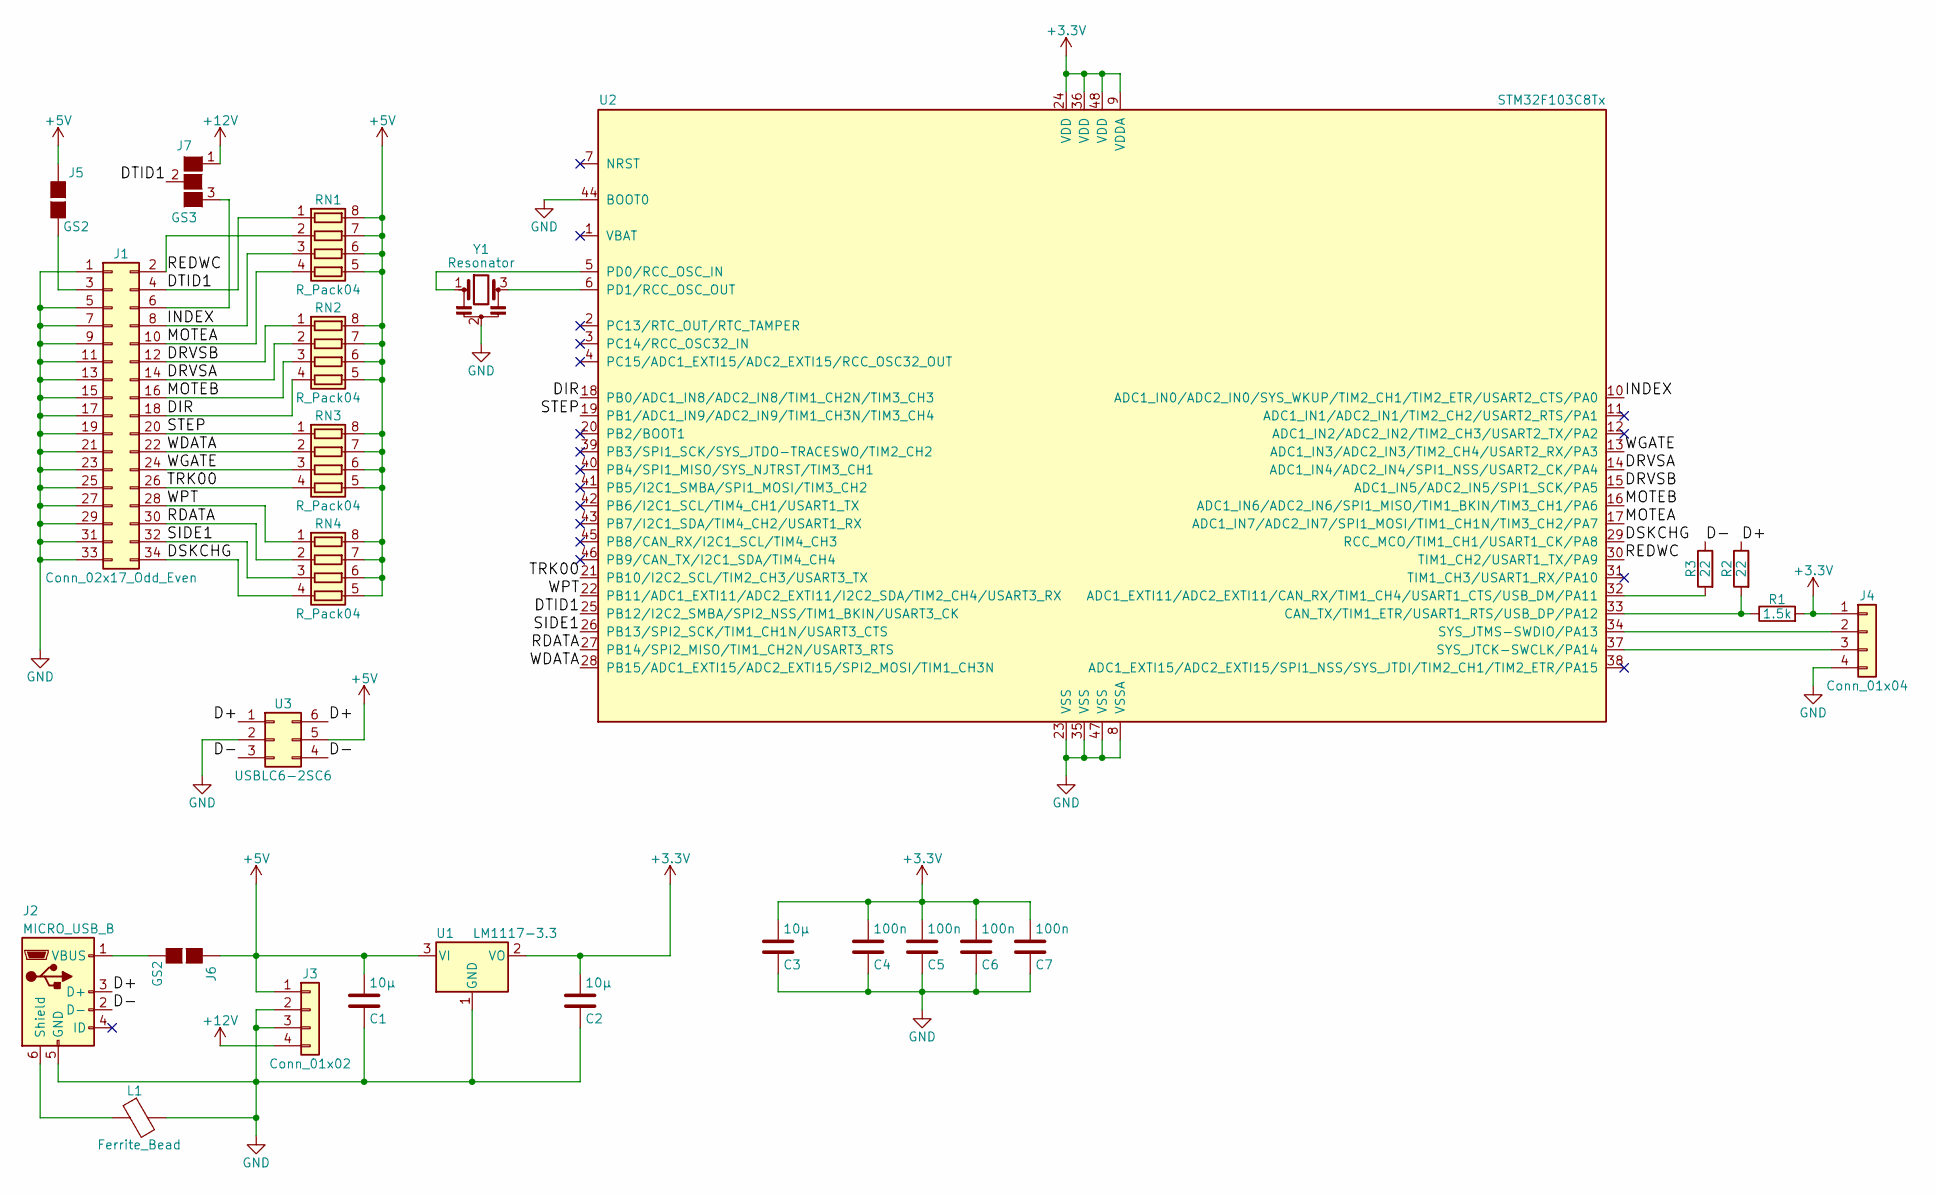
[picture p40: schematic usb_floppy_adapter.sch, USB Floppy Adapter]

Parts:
C1, C2, C3: 10µ; C_0805
C4, C5, C6, C7: 100n; C_0603
J1: Conn_02x17_Odd_Even; Socket_Strip_Straight_2x17_Pitch2.54mm
J2: MICRO_USB_B; USB_Micro-B_Vertical_Molex-105133-0001
J3: Conn_01x02; Pin_Header_Straight_1x04_Pitch2.54mm
J4: Conn_01x04; Pin_Header_Straight_1x04_Pitch1.27mm_SMD_Pin1Left
J5, J6: GS2
J7: GS3
L1: Ferrite_Bead; L_0805
R1: 1.5k; R_0603
R2, R3: 22; R_0603
RN1, RN2, RN3, RN4: R_Pack04; R_Array_Convex_4x0603
U1: LM1117-3.3; SOT-223-3Lead_TabPin2
U2: STM32F103C8Tx; LQFP-48_7x7mm_Pitch0.5mm
U3: USBLC6-2SC6; SOT-23-6
Y1: Resonator; Resonator_SMD_muRata_SFECV-3pin_6.9x2.9mm

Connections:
+3V3: C2.2, C3.2, C4.2, C5.2, C6.2, C7.2, J4.1, R1.2, U1.2 (VO), U2.9 (VDDA), U2.24 (VDD), U2.36 (VDD), U2.48 (VDD)
+5V: C1.2, J3.1, J5.1 (G1), J6.1 (G1), RN1.5 (R4.2), RN1.6 (R3.2), RN1.7 (R2.2), RN1.8 (R1.2), RN2.5 (R4.2), RN2.6 (R3.2), RN2.7 (R2.2), RN2.8 (R1.2), RN3.5 (R4.2), RN3.6 (R3.2), RN3.7 (R2.2), RN3.8 (R1.2), RN4.5 (R4.2), RN4.6 (R3.2), RN4.7 (R2.2), RN4.8 (R1.2), U1.3 (VI), U3.5
+12V: J3.4, J7.1 (G1)
/D+: J2.3 (D+), R2.1, U3.1, U3.6
/D-: J2.2 (D-), R3.1, U3.3, U3.4
/DIR: J1.18, RN2.4 (R4.1), U2.18 (PB0/ADC1_IN8/ADC2_IN8/TIM1_CH2N/TIM3_CH3)
/DRVSA: J1.14, RN2.2 (R2.1), U2.14 (ADC1_IN4/ADC2_IN4/SPI1_NSS/USART2_CK/PA4)
/DRVSB: J1.12, RN2.1 (R1.1), U2.15 (ADC1_IN5/ADC2_IN5/SPI1_SCK/PA5)
/DSKCHG: J1.34, RN4.4 (R4.1), U2.29 (RCC_MCO/TIM1_CH1/USART1_CK/PA8)
/DTID1: J1.4, J7.2 (G2), RN1.1 (R1.1), U2.25 (PB12/I2C2_SMBA/SPI2_NSS/TIM1_BKIN/USART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)
/INDEX: J1.8, RN1.3 (R3.1), U2.10 (ADC1_IN0/ADC2_IN0/SYS_WKUP/TIM2_CH1/TIM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)
/MOTEA: J1.10, RN1.4 (R4.1), U2.17 (ADC1_IN7/ADC2_IN7/SPI1_MOSI/TIM1_CH1N/T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)
/MOTEB: J1.16, RN2.3 (R3.1), U2.16 (ADC1_IN6/ADC2_IN6/SPI1_MISO/TIM1_BKIN/T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)
/RDATA: J1.30, RN4.2 (R2.1), U2.27 (PB14/SPI2_MISO/TIM1_CH2N/USART3_RTS)
/REDWC: J1.2, RN1.2 (R2.1), U2.30 (TIM1_CH2/USART1_TX/PA9)
/SIDE1: J1.32, RN4.3 (R3.1), U2.26 (PB13/SPI2_SCK/TIM1_CH1N/USART3_CTS)
/STEP: J1.20, RN3.1 (R1.1), U2.19 (PB1/ADC1_IN9/ADC2_IN9/TIM1_CH3N/TIM3_CH4)
/TRK00: J1.26, RN3.4 (R4.1), U2.21 (PB10/I2C2_SCL/TIM2_CH3/USART3_TX)
/WDATA: J1.22, RN3.2 (R2.1), U2.28 (PB15/ADC1_EXTI15/ADC2_EXTI15/SPI2_MOSI/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)
/WGATE: J1.24, RN3.3 (R3.1), U2.13 (ADC1_IN3/ADC2_IN3/TIM2_CH4/USART2_RX/PA3)
/WPT: J1.28, RN4.1 (R1.1), U2.22 (PB11/ADC1_EXTI11/ADC2_EXTI11/I2C2_SDA/T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)
GND: C1.1, C2.1, C3.1, C4.1, C5.1, C6.1, C7.1, J1.1, J1.5, J1.7, J1.9, J1.11, J1.13, J1.15, J1.17, J1.19, J1.21, J1.23, J1.25, J1.27, J1.29, J1.31, J1.33, J2.5 (GND), J3.2, J3.3, J4.4, L1.2, U1.1 (GND), U2.8 (VSSA), U2.23 (VSS), U2.35 (VSS), U2.44 (BOOT0), U2.47 (VSS), U3.2, Y1.2
unnamed: J1.3, J5.2 (G2)
unnamed: J1.6, J7.3 (G3)
unnamed: J2.1 (VBUS), J6.2 (G2)
unnamed: J2.6 (Shield), L1.1
unnamed: J4.2, U2.34 (SYS_JTMS-SWDIO/PA13)
unnamed: J4.3, U2.37 (SYS_JTCK-SWCLK/PA14)
unnamed: R1.1, R2.2, U2.33 (CAN_TX/TIM1_ETR/USART1_RTS/USB_DP/PA12)
unnamed: R3.2, U2.32 (ADC1_EXTI11/ADC2_EXTI11/CAN_RX/TIM1_CH4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)
unnamed: U2.5 (PD0/RCC_OSC_IN), Y1.1
unnamed: U2.6 (PD1/RCC_OSC_OUT), Y1.3

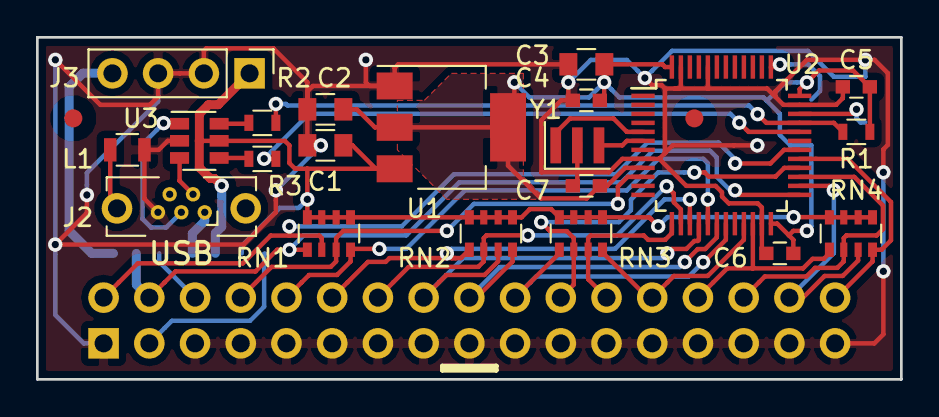
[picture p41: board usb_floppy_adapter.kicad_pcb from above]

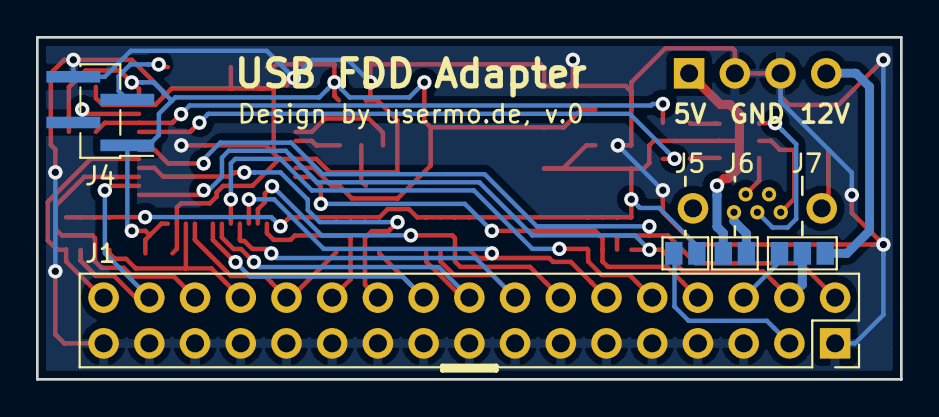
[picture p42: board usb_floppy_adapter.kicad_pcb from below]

Board: 2 copper layers, 48.0 x 19.0 mm, 26 parts (5 on the bottom side), 32 nets.

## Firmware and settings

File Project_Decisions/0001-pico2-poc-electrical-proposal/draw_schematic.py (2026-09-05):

# SPDX-License-Identifier: GPL-3.0-or-later
"""Render the tentative electrical concept to editable SVG and preview PNG.
Requires Pillow. Coordinates and net names are shared between both formats.
"""
from pathlib import Path
from html import escape
from PIL import Image, ImageDraw, ImageFont

OUT = Path(__file__).resolve().parent
INK, WIRE, MUTED, ACCENT = '#182737', '#145c46', '#516477', '#235e91'

class Sheet:
    def __init__(self, title, subtitle, height=1400):
        self.w, self.h = 1600, height
        self.im = Image.new('RGB', (self.w, self.h), 'white')
        self.d = ImageDraw.Draw(self.im)
        self.svg = [f'<svg xmlns="http://www.w3.org/2000/svg" width="{self.w}" height="{self.h}" viewBox="0 0 {self.w} {self.h}">', '<rect width="100%" height="100%" fill="white"/>']
        self.text(45, 25, title, 32, ACCENT)
        self.text(45, 72, subtitle, 18, MUTED)
        self.line((45, 110), (1555, 110), color=ACCENT)

    def text(self, x, y, s, size=20, color=INK):
        font = ImageFont.truetype('C:/Windows/Fonts/consola.ttf', size)
        self.d.text((x, y), s, fill=color, font=font)
        self.svg.append(f'<text x="{x}" y="{y+size}" fill="{color}" font-family="Consolas,monospace" font-size="{size}">{escape(s)}</text>')

    def line(self, *points, color=WIRE, width=2):
        self.d.line(points, fill=color, width=width)
        p = ' '.join(f'{x},{y}' for x,y in points)
        self.svg.append(f'<polyline points="{p}" fill="none" stroke="{color}" stroke-width="{width}"/>')

    def rect(self, x, y, w, h, color=MUTED):
        self.line((x,y),(x+w,y),(x+w,y+h),(x,y+h),(x,y), color=color)

    def dot(self, x, y, open=False):
        self.d.ellipse((x-4,y-4,x+4,y+4),fill='white' if open else WIRE,outline=WIRE,width=2)
        self.svg.append(f'<circle cx="{x}" cy="{y}" r="4" fill="{"white" if open else WIRE}" stroke="{WIRE}" stroke-width="2"/>')

    def ground(self,x,y):
        self.line((x,y),(x,y+12))
        for i,w in enumerate((18,12,6)):
            self.line((x-w,y+12+i*6),(x+w,y+12+i*6))

    def resistor(self,x,y,label,vertical=False):
        if vertical:
            self.line((x,y),(x,y+12)); self.rect(x-8,y+12,16,36,WIRE); self.line((x,y+48),(x,y+60)); self.text(x+16,y+17,label,18)
        else:
            self.line((x,y),(x+12,y)); self.rect(x+12,y-8,56,16,WIRE); self.line((x+68,y),(x+80,y)); self.text(x+8,y-36,label,18)

    def fet(self,x,y):
        # Gate terminal at x-70,y; drain at x+20,y-90; source at x+20,y+70.
        self.line((x-70,y),(x-25,y)); self.line((x-25,y-30),(x-25,y+30))
        for a,b in ((-32,-12),(-8,8),(12,32)): self.line((x-12,y+a),(x-12,y+b))
        self.line((x-12,y-27),(x+20,y-27),(x+20,y-90))
        self.line((x-12,y+27),(x+20,y+27),(x+20,y+70))
        self.line((x+20,y),(x-12,y)); self.line((x-5,y-5),(x-12,y),(x-5,y+5))
        self.text(x+36,y-38,'Q: AO3400A',18)
        self.text(x+36,y-12,'1=G  2=S  3=D',16,MUTED)
        self.text(x-47,y-53,'G',16); self.text(x+28,y-78,'D',16); self.text(x+28,y+42,'S',16)
        self.ground(x+20,y+70)

    def inv(self,x,y):
        # Input at x,y; output at x+108,y.
        self.line((x,y),(x+20,y)); self.line((x+20,y-30),(x+20,y+30),(x+85,y),(x+20,y-30))
        self.dot(x+91,y,True); self.line((x+95,y),(x+108,y))
        self.line((x+35,y+10),(x+35,y-9),(x+46,y-9),(x+46,y+10),(x+55,y+10),color=INK)
        self.text(x-4,y-68,'SN74LVC14A',18); self.text(x+8,y+38,'VCC = 3.3 V',16,MUTED)

    def save(self,name):
        self.text(45,self.h-44,'TENTATIVE | 2026-09-01 | GPIO numbers TBD | See README for limits and sources',18,MUTED)
        self.svg.append('</svg>')
        (OUT/f'{name}.svg').write_text('\n'.join(self.svg),encoding='utf-8')
        self.im.save(OUT/f'{name}.png')

s=Sheet('Pico 2 / floppy drive interface — circuit cells','3.3 V controller domain | 5 V cable domain | One cell per signal; names are symbolic')
s.text(45,130,'A. OUTPUT — GPIO high pulls the cable signal low',24,ACCENT)
s.text(75,220,'GPIO_TX',20)
s.line((170,255),(260,255)); s.resistor(260,255,'100R'); s.line((340,255),(470,255))
s.dot(385,255); s.resistor(385,275,'10k',True); s.line((385,255),(385,275)); s.ground(385,335)
s.fet(540,255); s.line((560,165),(1040,165)); s.text(760,132,'LINE_TX_n -> port selector',20)
s.text(1090,160,'At the selected DRIVE:',18,MUTED)
s.line((1040,165),(1040,205)); s.resistor(1040,205,'R_TERM',True); s.line((1040,265),(1040,285)); s.text(930,300,'+5 V drive supply',18)
s.text(1090,207,'Use its specified pull-up.',18)
s.text(1090,238,'150R is a legacy example.',18)
s.text(75,375,'GPIO low / high-Z = release. Pull-down keeps Q off during reset.',18)
s.text(75,405,'WRITE GATE only: add removable WRITE ARM link before the 100R gate resistor.',18)
s.line((45,453),(1555,453),color=MUTED)

s.text(45,472,'B. INPUT — asserted cable signal becomes GPIO high',24,ACCENT)
s.text(75,590,'LINE_RX_n',20); s.line((190,620),(520,620)); s.dot(350,620)
s.text(270,510,'+5V_IF',18); s.resistor(350,545,'1k initial',True); s.line((350,530),(350,545)); s.line((350,605),(350,620))
s.resistor(520,620,'100R'); s.line((600,620),(720,620)); s.inv(720,620)
s.line((828,620),(940,620)); s.resistor(940,620,'100R'); s.line((1020,620),(1260,620)); s.text(1290,605,'GPIO_RX',20)
s.text(75,710,'Pull-up is removable. Select its value from the drive sink rating and cable load.',18)
s.text(75,740,'Receiver supply: Pico 3V3(OUT). 100 nF at each IC. Inputs tolerate 5.5 V.',18)
s.line((45,792),(1555,792),color=MUTED)

s.text(45,810,'C. CONFIGURABLE DIRECTION — one GPIO, set by a hardware jumper',24,ACCENT)
s.text(65,940,'GPIO_FLEX',20); s.line((180,975),(320,975)); s.dot(320,975,True)
s.dot(360,925,True); s.dot(360,1025,True); s.line((320,975),(355,930),width=3)
s.text(230,863,'JP_DIR',18); s.text(370,889,'TX',18); s.text(370,1035,'RX',18)
s.line((360,925),(530,925)); s.resistor(530,925,'100R'); s.line((610,925),(720,925))
s.dot(655,925); s.line((655,925),(655,950)); s.resistor(655,950,'10k',True); s.ground(655,1010)
s.fet(790,925); s.line((810,835),(1015,835),(1015,900),(1270,900)); s.text(1280,878,'LINE_FLEX_n',18)
s.line((1015,900),(1015,1130)); s.dot(1015,900)
s.text(1130,954,'Cable pull-up as in A/B;',18); s.text(1130,982,'fit only as required.',18)
# Receiver drawn left-to-right with named net connected to shared cable node.
s.line((1015,1130),(1015,1195),(440,1195),(440,1110),(500,1110)); s.resistor(500,1110,'100R')
s.line((580,1110),(700,1110)); s.inv(700,1110); s.line((808,1110),(845,1110)); s.resistor(845,1110,'100R')
s.line((925,1110),(955,1110),(955,1060),(410,1060),(410,1025),(360,1025))
s.text(75,1230,'One shunt: TX or RX. No shunt: GPIO disconnected; Q stays off.',18)
s.text(75,1260,'This selects direction between configurations. For live open-drain bidirectionality,',18)
s.text(75,1290,'use separate TX and RX GPIOs instead; never tie the receiver output to the Q gate.',18)
s.save('interface-cells')
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

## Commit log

2026-08-30 Add floppy drive reference materials
2026-09-05 Organize project decisions and reference materials
2026-09-05 recovered files from a crashed session
    Preserve the Pico 2 electrical-interface proposal, supporting design notes, schematic generator, and rendered SVG and PNG drawings recovered from an interrupted work session.
    This material is retained in the non-authoritative Project_Decisions engineering notebook for future review and possible reuse.
    [draw_schematic.py]
2026-09-06 Add Greaseweazle reference snapshot
    Preserve a complete working-tree snapshot of the upstream Greaseweazle master branch at commit 26690f89967d519e0106ab9566019a026b920bb4.
    Record the upstream URL, revision, retrieval date, completeness, local-modification status, and Unlicense provenance in the associated README. The snapshot excludes only upstream Git history and repo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
    [diskdefs.cfg, diskdefs_acorn.cfg, diskdefs_akai.cfg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]
2026-09-06 Add USB floppy adapter reference snapshot
    Preserve a complete working-tree snapshot of roybaer/usb_floppy_adapter master at commit 6b198eee4d43223143619c8f1f6366a4c19ca641. Record its upstream URL, revision, retrieval date, completeness, loc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
    [usb_floppy_adapter.kicad_pcb, usb_floppy_adapter.sch]
2026-09-09 Establish KiCad design and automation toolchain
2026-09-09 Add headless KiCad automation workflow
    [empty-native.kicad_sch]
2026-09-09 Enforce warning-free KiCad CLI execution
